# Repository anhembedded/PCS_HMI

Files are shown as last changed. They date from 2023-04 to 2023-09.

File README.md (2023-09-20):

# Microcontroller-HMI replace for PLC

The Festo PCS system, currently available at Cao Thang Technical College, is used for teaching the practical course of Electrical and Electronic Engineering 2, utilizing control systems through EASY PORT or PLC S7-1200 and HMI. However, it poses challenges in terms of maintenance, repair, and replacement due to its high cost. Therefore, this project employs the STM32 microcontroller as a cost-effective alternative, aiming to proactively enhance maintenance and repair, as well as improve the quality of microcontroller utilization and embedded programming skills among students in the field of Electrical and Electronic Engineering.

## Table of Contents

- [Installation](#installation)
- [Usage](#usage)
- [Contributing](#contributing)

## Installation

## Usage

## Contributing

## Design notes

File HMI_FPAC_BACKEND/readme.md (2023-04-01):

# STM32F469I-DISCO TBS

The default IDE is set to STM32CubeIDE, to change IDE open the STM32F469I-DISCO.ioc with CubeMX and select from the supported IDEs (EWARM from version 8.50.9, MDK-ARM, and STM32CubeIDE). Supports flashing of the STM32F469I-DISCO board directly from TouchGFX Designer using GCC and STM32CubeProgrammer.Flashing the board requires STM32CubeProgrammer which can be downloaded from the ST webpage. 

This TBS is configured for 480 x 800 pixels 16bpp screen resolution.  

Performance testing can be done using the GPIO pins designated with the following signals: VSYNC_FREQ  - Pin PA2(D5), RENDER_TIME - Pin PA6(D6), FRAME_RATE  - Pin PA1(D3), MCU_ACTIVE  - Pin PG12(D4)

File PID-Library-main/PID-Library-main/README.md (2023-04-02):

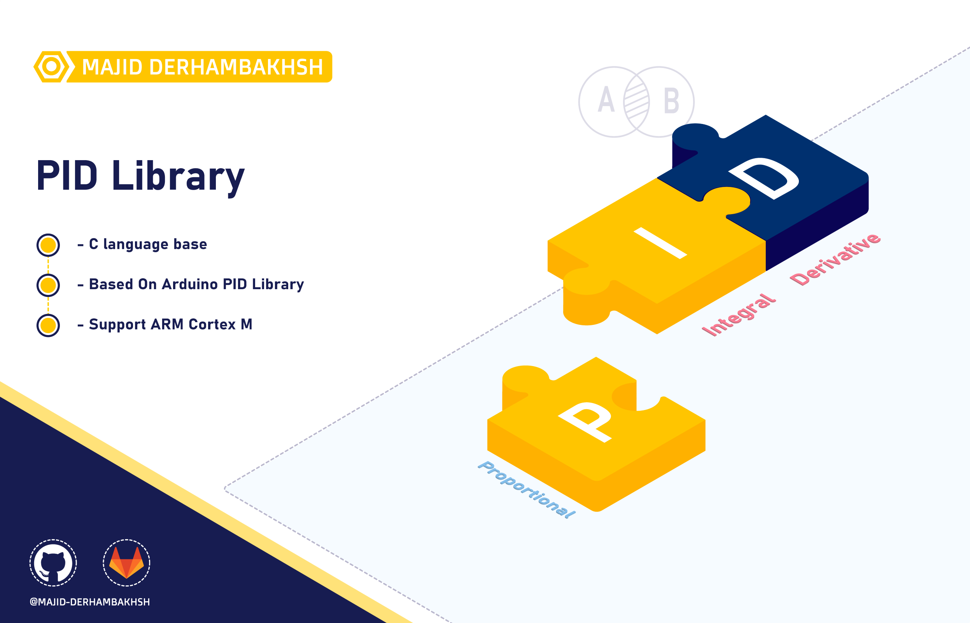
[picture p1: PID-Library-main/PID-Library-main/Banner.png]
Banner


# PID-Library (C Version)

PID Controller library for ARM Cortex M (STM32)

> #### Download Arduino Library : [Arduino-PID-Library](https://github.com/br3ttb/Arduino-PID-Library)  

## Release

- #### Version : 1.0.0

- #### Type : Embedded Software

- #### Support  

               - ARM STM32 series  

- #### Program Language : C/C++

- #### Properties

- #### Changes  

- #### Required Library/Driver

## Overview

### Initialization and de-initialization functions

```c++
void PID(PID_TypeDef *uPID, double *Input, double *Output, double *Setpoint, double Kp, double Ki, double Kd, PIDPON_TypeDef POn, PIDCD_TypeDef ControllerDirection);
void PID2(PID_TypeDef *uPID, double *Input, double *Output, double *Setpoint, double Kp, double Ki, double Kd, PIDCD_TypeDef ControllerDirection);
```

### Operation functions

```c++
/* ::::::::::: Computing ::::::::::: */
uint8_t PID_Compute(PID_TypeDef *uPID);

/* ::::::::::: PID Mode :::::::::::: */
void            PID_SetMode(PID_TypeDef *uPID, PIDMode_TypeDef Mode);
PIDMode_TypeDef PID_GetMode(PID_TypeDef *uPID);

/* :::::::::: PID Limits ::::::::::: */
void PID_SetOutputLimits(PID_TypeDef *uPID, double Min, double Max);

/* :::::::::: PID Tunings :::::::::: */
void PID_SetTunings(PID_TypeDef *uPID, double Kp, double Ki, double Kd);
void PID_SetTunings2(PID_TypeDef *uPID, double Kp, double Ki, double Kd, PIDPON_TypeDef POn);

/* ::::::::: PID Direction ::::::::: */
void          PID_SetControllerDirection(PID_TypeDef *uPID, PIDCD_TypeDef Direction);
PIDCD_TypeDef PID_GetDirection(PID_TypeDef *uPID);

/* ::::::::: PID Sampling :::::::::: */
void PID_SetSampleTime(PID_TypeDef *uPID, int32_t NewSampleTime);

/* ::::::: Get Tunings Param ::::::: */
double PID_GetKp(PID_TypeDef *uPID);
double PID_GetKi(PID_TypeDef *uPID);
double PID_GetKd(PID_TypeDef *uPID);
```

### Macros

```diff  
non   
```

## Guide

#### This library can be used as follows

#### 1.  Add pid.h header  

#### 2.  Create PID struct and initialize it, for example

- Initializer:

  ```c++
  PID(PID_TypeDef *uPID, double *Input, double *Output, double *Setpoint, double Kp, double Ki, double Kd, PIDPON_TypeDef POn, PIDCD_TypeDef ControllerDirection);
  ```

- Parameters:  
  - uPID : Pointer to pid struct
  - Input : The variable we're trying to control (double)
  - Output : The variable that will be adjusted by the pid (double)
  - Setpoint : The value we want to Input to maintain (double)
  - Kp,Ki,Kd : Tuning Parameters. these affect how the pid will change the output (double>=0)
  - POn : Either P_ON_E (Default) or P_ON_M. Allows Proportional on Measurement to be specified.  
  - ControllerDirection : Either DIRECT or REVERSE. determines which direction the output will move when faced with a given error. DIRECT is most common  

- Example:

  ```c++  
  PID_TypeDef TPID;

  double Temp, PIDOut, TempSetpoint;

  PID(&TPID, &Temp, &PIDOut, &TempSetpoint, 2, 5, 1, _PID_P_ON_E, _PID_CD_DIRECT);
  ```

#### 3.  Set 'mode', 'sample time' and 'output limit', for example  

- Functions:

  ```c++
  void PID_SetMode(PID_TypeDef *uPID, PIDMode_TypeDef Mode);
  void PID_SetOutputLimits(PID_TypeDef *uPID, double Min, double Max);
  void PID_SetSampleTime(PID_TypeDef *uPID, int32_t NewSampleTime);
  ```

- Parameters:  
  - uPID : Pointer to pid struct
  - Mode : _PID_MODE_AUTOMATIC or_PID_MODE_MANUAL
  - Min : Low end of the range. must be < max (double)
  - Max : High end of the range. must be > min (double)
  - NewSampleTime : How often, in milliseconds, the PID will be evaluated. (int>0)  

- Example:

  ```c++  
  PID_SetMode(&TPID, _PID_MODE_AUTOMATIC);
  PID_SetSampleTime(&TPID, 500);
  PID_SetOutputLimits(&TPID, 1, 100);
  ```
  
#### 4.  Using Compute function, for example  

```c++
PID_Compute(&TPID);
```  

## Examples  

#### Example 1: PID Compute for temperature

```c++  
#include "main.h"
#include "pid.h"

PID_TypeDef TPID;

char OutBuf[50];
double Temp, PIDOut, TempSetpoint;

int main(void)
{
 
  HW_Init();
  
  PID(&TPID, &Temp, &PIDOut, &TempSetpoint, 2, 5, 1, _PID_P_ON_E, _PID_CD_DIRECT);
 
  PID_SetMode(&TPID, _PID_MODE_AUTOMATIC);
  PID_SetSampleTime(&TPID, 500);
  PID_SetOutputLimits(&TPID, 1, 100);
  
    while (1) 
    {
  
      Temp = GetTemp();
      PID_Compute(&TPID);
      
      sprintf(OutBuf, "Temp%3.2f : %u\n", Temp, (uint16_t)PIDOut);
      UART_Transmit((uint8_t *)OutBuf, strlen(OutBuf));
      
      Delay_ms(500);
    
    }
}
   
```

## Tests performed

- [x] Run on STM32 Fx cores

## Developers

- ### Majid Derhambakhsh

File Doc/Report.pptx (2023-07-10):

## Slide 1

TRƯỜNG KỸ THUẬT CAO ĐẲNG CAO THẮNG
KHOA CƠ KHÍ
BỘ MÔN CƠ ĐIỆN TỬ

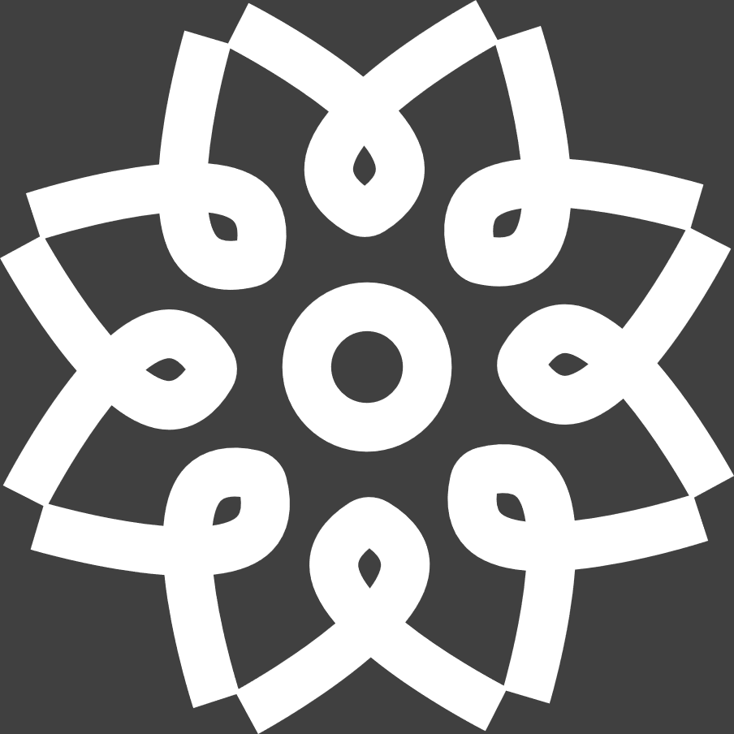
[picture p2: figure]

BÁO CÁO ĐỒ ÁN

THIẾT KẾ VÀ THI CÔNG LÒ NHIỆT

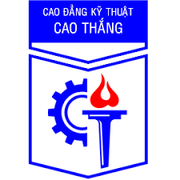
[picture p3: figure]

Ngày 14/12/2022
12 giờ 30 sáng

www.caothang.edu.vn

## Nhóm thực hiện

- GVHD: HỒ MINH CHÍNH

- SVTH: TRẦN HOÀNG ANH 0307171101 CĐ CĐT 19B
- TGTH: 12/6/2023 – 8/7/2023

## Mục tiêu

- Sử dụng board vi điều khiển STM32 có màng hình cảm ứng thay thế PLC S7-1200 và màng hình HMI.

## Chương 1: TỔNG QUAN

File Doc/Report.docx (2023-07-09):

# LỜI CẢM ƠN

Đến với trang đầu tiên của đồ án này , em xin gửi lời cảm ơn đến quý Thầy Cô của Trường Cao Đẳng Kỹ Thuật Cao Thắng là những người đã tận tình truyền đạt những kiến thức cho em suốt thời gian qua.

Bên cạnh đó, cho em gửi lời cảm ơn này đến tất cả Thầy Cô của bộ môn Cơ Điện Tử. mọi người đã luôn tận tình giảng dạy và theo sát trong chặng đường vừa qua.

Và đặc biệt hơn em xin gửi lời cảm ơn chân thành đến Thầy Th.s Hồ Minh Chính người đã đồng hành cùng em mặc dù dịch bệnh vẫn còn phức tạp nhưng thầy vẫn luôn sẵn sàng hỗ trợ đề tài đồ án tốt nghiệp này.

# TÓM TẮT

Ai cũng biết nước đóng vai trò quan trọng trong đời sống cũng như sản xuất, như xa xưa con người lấy nước bằng những cách thô sơ và khó khăn. Và công nghệ 4.0 đang tiếp cận ngày càng nhiều vào cuộc sống của chúng ta thì việc lấy nước từ nơi này sang nơi khác trở nên dễ dàng hơn tiết kiệm nhân công và thời gian.

Để nói rõ hơn thì đồ án này của em là cải tiến trạm PCS bằng việc mô phỏng quá trình lấy nước từ bồn tank1 sang bồn tank2 và ngược lại bằng cách viết chương trình cho board stm32f469 DISC, với giao diện điều khiển bằng màng hình cảm ứng điện dung, ngoài ra có thể điều khiển được mức nước lưu lượng và cũng như áp suất.

Với đề tài đồ án này em đã thực hiện theo các bước sau:

Bước 1: Nghiên cứu tài liệu về tổng quan về chức năng, mục đích sử dụng của hệ thống.

Bước 2: Nghiên cứu sâu vào các đặt tính điện, lô-gíc , chức năng của phần điều khiển mức nước, lưu lượng và áp suất.

Bước 3: Chọn các module chức năng đáp ứng được các yêu cầu về điện, và tín hiệu điều khiển.

Bước 4: Tiến hành viết firmware cho vi điều khiển.

Bước 5: Tiến hành viết HMI cho vi điều khiển.

# DANH SÁCH CHỮ VIẾT TẮT

PCS Processing control system

PID Proportional, Integral, and Derivative

SCADA Supervisory Control And Data Acquisition

# DANH SÁCH CÁC HÌNH

# DANH SÁCH BẢNG

# Chương 1: TỔNG QUAN

## 1.1. Tính cấp thiết của đề tài:

## 1.2. Tổng quan kết quả nghiên cứu liên quan

#### Các kết quả nghiên cứu nước ngoài:

#### Các kết quả nghiên cứu trong nước:

## 1.3. Mục tiêu nghiên cứu của đề tài:

## 1.4. Nhiệm vụ của đề tài và giới hạn đề tài

### Nhiệm vụ đề tài:

### Giới hạn đề tài:

# Chương 2: CƠ SỞ LÝ THUYẾT

## 2.1. Tổng quan về board Stm32f469 DISC

Stm32f469 DISC là một bộ kit phát triển dựa trên vi điều khiển STM32F469NIH6 có hiệu năng cao với lõi ARM Cortex-M4 và Chrom-ART Accelerator. Bộ kit cho phép người dùng phát triển các ứng dụng đa dạng tận dụng các tính năng đồ họa, âm thanh, cảm biến, màn hình màu WVGA, bảo mật, mở rộng bộ nhớ và kết nối. Bộ kit có sẵn trình gỡ lỗi/programmer ST-LINK/V2-1 tích hợp; các bo mạch mở rộng chuyên biệt có thể được kết nối nhờ các cổng Arduino UNO hoặc các cổng mở rộng. Bộ kit cũng có màn hình LCD TFT 4 inch 800x480 pixel với giao tiếp MIPI DSI và màn hình cảm ứng điện dung, DAC âm thanh SAI, jack cắm tai nghe stereo, 3 micro MEMS, khe cắm thẻ MicroSD, bộ nhớ SDRAM 4Mx32bit, bộ nhớ Flash Quad-SPI 128-Mbit và nhiều tính năng khác .

## 2.2. Tổng quan về lõi ARM® Cortex®-M4

Lõi ARM® Cortex®-M4 là một bộ xử lý nhúng hiệu năng cao được phát triển để đáp ứng các thị trường điều khiển tín hiệu số yêu cầu một sự kết hợp hiệu quả và dễ sử dụng giữa khả năng điều khiển và xử lý tín hiệu. Lõi Cortex-M4 có các tính năng và lợi ích sau :

- Hỗ trợ đơn vị tính toán dấu chấm động (FPU) với định dạng IEEE 754-2008.

- Hỗ trợ giao tiếp song song và nối tiếp với các giao thức khác nhau .

- Hỗ trợ gỡ lỗi và theo dõi với các thành phần ETM, MPU, NVIC, FPB, DWT, ITM, AHB, TPIU.

Lõi Cortex-M4 được thiết kế để phục vụ cho nhiều ứng dụng như điều khiển công nghiệp, cảm biến IoT, trí tuệ nhân tạo, xử lý âm thanh và hình ảnh. Lõi Cortex-M4 có thể hoạt động ở tốc độ lên đến 240 MHz và có khả năng xử lý 1.25 DMIPS/MHz. Lõi Cortex-M4 là một trong những lõi vi xử lý ARM phổ biến nhất hiện nay.

## 2.3. Tổng quan về nền tảng stm32 touch gfx

STM32 touch gfx là một nền tảng đồ họa nâng cao và miễn phí được tối ưu hóa cho các vi điều khiển STM32. STM32 touch gfx cho phép tạo ra các giao diện người dùng đẹp mắt và trơn tru trên các thiết bị nhúng, từ các ứng dụng đơn giản với ít màu sắc đến các ứng dụng phức tạp với độ phân giải và màu sắc cao. STM32 touch gfx tận dụng các khả năng phần cứng, kiến trúc và hệ sinh thái của STM32 để tăng tốc quá trình phát triển giao diện người dùng.

STM32 touch gfx có kích thước nhỏ gọn, chỉ cần một lượng bộ nhớ hạn chế để chạy các giao diện người dùng mượt mà. STM32 touch gfx có thể chạy với RTOS hoặc trên bare metal, hỗ trợ các vi điều khiển STM32 dựa trên các bộ xử lý Arm Cortex-M0+, M3, M4, M33 và M7.

## 2.4. Bộ điều khiển PID

Bộ điều khiển PID là một loại bộ điều khiển phản hồi phổ biến trong các hệ thống tự động hóa công nghiệp. Bộ điều khiển PID sử dụng ba thành phần cơ bản: đạo hàm (D), tích phân (I) và tỷ lệ (P) để tính toán một tín hiệu điều khiển dựa trên sự chênh lệch giữa giá trị mong muốn và giá trị thực tế của một biến quá trình. Bộ điều khiển PID có thể điều chỉnh độ nhạy, thời gian đáp ứng và độ ổn định của hệ thống bằng cách thay đổi các thông số P, I và D. Bộ điều khiển PID được ứng dụng rộng rãi trong các lĩnh vực như điều khiển nhiệt độ, áp suất, lưu lượng, tốc độ, vị trí và nhiều biến quá trình khác.

## 2.5. Phương pháp thiết kế bộ điều khiển PID theo Ziegler-Nichols

Phương pháp Ziegler-Nichols là một phương pháp đơn giản để lựa chọn các hệ số Kp, Ki và Kd cho bộ điều khiển PID. Phương pháp này dựa trên việc quan sát biểu đồ đáp ứng của hệ thống khi áp dụng một tín hiệu bước vào đầu vào.

# Chương 3: GIỚI THIỆU MÔ HÌNH

### 1.1.1. Bơm:

Giới thiệu đặc tính bơm, các thông số cơ bản, vai trò của bơm trong hệ thống

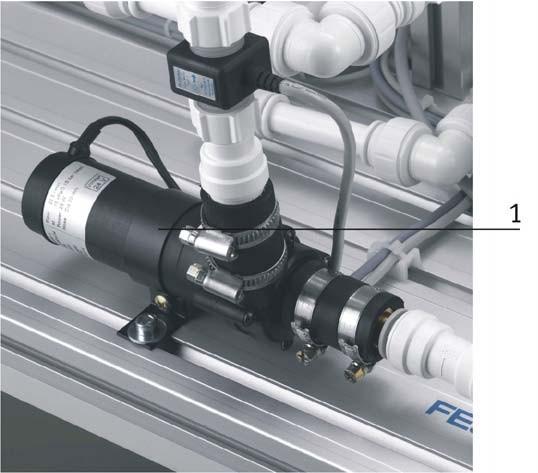
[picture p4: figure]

Hình 3-2 cụm bơm

Máy bơm không được vận hành khi chạy khô. Trước khi vận hành thử, bể chứa hoặc hệ thống đường ống đến / từ máy bơm phải được đổ đầy chất lỏng.

Bơm được dẫn động bởi bộ điều khiển động cơ A4 và rơ le K1. Với đầu ra kỹ thuật số (O2 tại XMA1), có thể chuyển từ điều khiển nhị phân kỹ thuật số sang biến điều khiển tương tự từ 0 đến 24 V. Tại điều khiển nhị phân kỹ thuật số (O2 = 0), máy bơm được bật / tắt với một đầu ra bổ sung (O3 tại XMA1). Ở điều khiển tương tự (O2 = 1), điện áp biến tần từ kênh tín hiệu đầu ra tương tự 0 (UA1 tại X2) đang cài đặt tốc

độ của bơm từ 0 đến 10 V.

- Chức năng của bơm

Máy bơm cung cấp chất lỏng từ bể chứa qua hệ thống đường ống. Tốc độ dòng chảy được phát hiện nhờ cảm biến cánh gạt quang điện tử B102 (2) ở dạng giá trị thực. Giá trị thực tế cũng nên được giữ trên một tốc độ dòng chảy nhất định nếu xảy ra nhiễu loạn hoặc thay đổi điểm đặt.

Để điều khiển hệ thống, có thể sử dụng phần tử liên tục . Có hai chế độ hoạt động:

- Điều khiển tốc độ dòng chảy bằng máy bơm P101 như một hệ thống được điều khiển. Giá trị thao tác là điện áp của máy bơm, thiết lập tốc độ quay vòng.
- Điều khiển tốc độ dòng chảy bằng van tỷ lệ V106 như một hệ thống được điều khiển. Giá trị thao tác là điện áp của cuộn van, thiết lập hành trình của piston van. Máy bơm P101 đang chạy với tốc độ quay vòng không đổi.

### 1.1.2. Bình chứa

#### 1.1.2.1. Bình B101

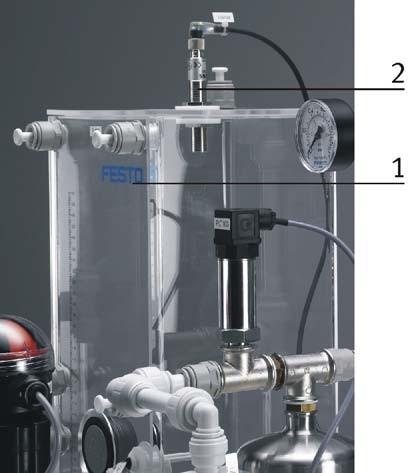
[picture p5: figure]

Hình 3-3 tank 1

#### 1.1.2.2. Bình chứa B102

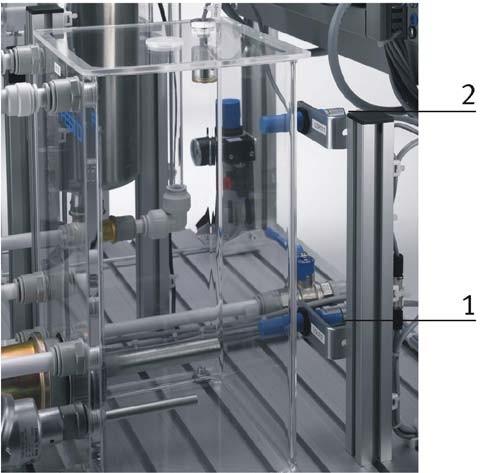
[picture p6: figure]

Hình 3-4 tank 2

#### 1.1.2.3. Bình áp suất B103

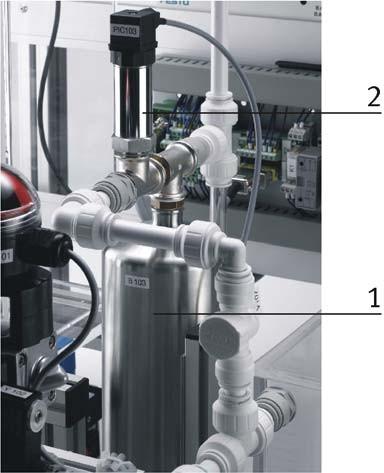
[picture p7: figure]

Hình 3-5 bình áp suất

Áp suất quá trình của chất lỏng bên trong bình tích áp phải được điều chỉnh. Hệ thống điều khiển áp suất được sử dụng là hệ thống được điều khiển có khả năng tự điều chỉnh (hệ thống điều khiển PT1). Bởi vì bình tích áp được làm đầy một phần khí (không khí) nên nó là một hệ thống lưu trữ năng lượng.

Thông qua hệ thống đường ống, máy bơm P101 cung cấp chất lỏng từ bồn chứa vào bồn chứa áp suất được bơm đầy khí B103 (1). Áp suất của khí (không khí) trong bình tích áp được phát hiện bằng cảm biến áp suất tương đối áp suất dưới dạng một giá trị thực tế. Giá trị thực tế cũng nên được giữ ở một áp suất nhất định nếu xảy ra nhiễu loạn hoặc thay đổi điểm đặt.

### 1.1.3. Van cầu đóng mở bằng khí nén

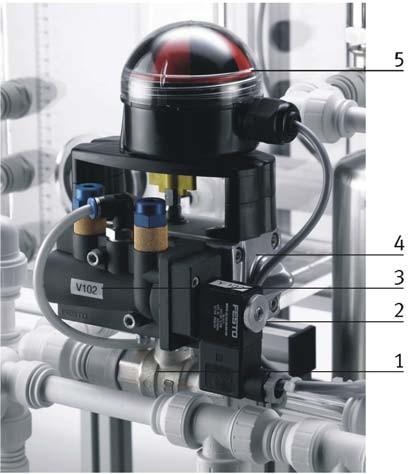
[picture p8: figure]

Hình 3-6 van cầu đómg

V102 lắp khớp được đóng mở bằng bộ truyền động khí nén. Thiết bị được điều khiển bao gồm một van bi bằng đồng (1) với kiểu ổ quay SYPAR (4), sử dụng nguyên lý chạy scotch. Một van điện từ (2) 5/2 chiều (3) với kiểu cổng tới NAMUR và hộp cảm biến (5) được lắp mặt bích vào ổ quay. Dòng chảy của chất lỏng từ thùng trên B102 vào thùng dưới B101 được điều khiển bằng van bi của bộ truyền động quá trình.

Cấu tạo của van cầu

1. van bi đồng điện
2. van điện từ
3. Van 5/2 chiều với kiểu cổng tới kiểu ổ quay NAMUR
4. SYPAR, hộp cảm biến nguyên lý ổ cắm scotch
5. bao gồm hai công tắc vi điện với cần con lăn. Hai tín hiệu nhị phân 24 VDC (S115 và S116) được kết nối làm đầu vào cho I / O-terminal XMA1. Ngoài ra còn có một chỉ dẫn trực quan về vị trí ổ đĩa cho người vận hành.

### 1.1.4. Van tỉ lệ

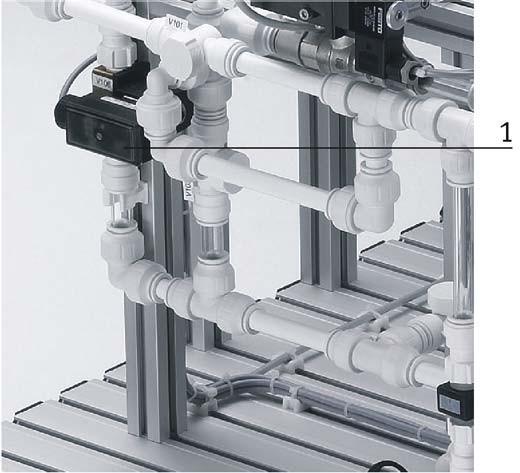
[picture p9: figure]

Hình 3-7 van tỉ lệ

Van tỷ lệ V106 (1) là van 2 chiều được kích hoạt trực tiếp để kiểm soát dòng chảy của chất lỏng. Nó có thể được sử dụng như một phần tử điều chỉnh từ xa trong các vòng mở hoặc đóng. Các piston của van được nâng lên khỏi chỗ của nó như một chức năng của dòng điện cuộn dây điện từ và giải phóng dòng chảy qua van

Điện tử điều khiển của van tỷ lệ được kích hoạt với đầu ra nhị phân (O4 tại XMA1). Tín hiệu tương tự từ kênh 1 (UA2 tại X2) được điều khiển đầu vào tín hiệu của van tỷ lệ với tín hiệu tương tự tiêu chuẩn từ 0 đến 10 V.

Tín hiệu tương tự tiêu chuẩn được biến đổi thành điều chế độ rộng xung (PWM) và độ mở của van có thể điều chỉnh vô hạn. Tần suất của PWM có thể được điều chỉnh cho các loại van khác nhau.

### 1.1.5. Các cảm biến

#### 1.1.1.1. Cảm biến siêu âm

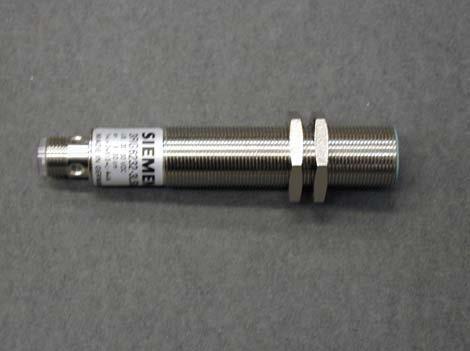
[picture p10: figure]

Hình 3-8 cảm biến siêu âm

Chức năng:

- Nguyên tắc hoạt động của cảm biến siêu âm dựa trên việc tạo ra sóng âm và phát hiện chúng sau phản xạ trên một vật thể. Thông thường, không khí trong khí quyển hoạt động như một vật mang sóng siêu âm.
- Máy phát âm thanh được kích hoạt trong một khoảng thời gian ngắn và phát ra xung siêu âm mà tai người không nghe được. Sau khi phát xạ, xung siêu âm được phản xạ trên một vật thể nằm trong phạm vi và dội ngược trở lại máy thu. Khoảng thời gian của xung siêu âm được đánh giá bằng điện tử. Trong một phạm vi nhất định, tín hiệu đầu ra tỷ lệ với thời lượng tín hiệu của xung siêu âm. Đối tượng được phát hiện có thể được làm bằng các vật liệu khác nhau. Hình dạng hoặc màu sắc, tình trạng rắn, lỏng hoặc bột không có bất kỳ hoặc ảnh hưởng rất nhỏ đến việc phát hiện.
- Trong trường hợp các vật thể có bề mặt nhẵn, đồng đều, bề mặt đó phải được căn chỉnh theo chiều dọc của chùm tia siêu âm.
- Với loại cảm biến này, bạn có thể thực hiện hai loại phép đo: Đầu tiên, bạn có thể đo khoảng cách giữa cảm biến và một đối tượng. Thiết lập của nhà sản xuất của cảm biến là lý tưởng cho loại phép đo này. Tăng tín hiệu đầu ra ở khoảng cách tăng tới đối tượng.
- Nhưng để đo mức đổ đầy của vật chứa, cần phải có một thiết lập khác vì khi mức lấp đầy tăng lên, khoảng cách của đối tượng được đo (mặt nước) đến cảm biến ngày càng nhỏ.
- Do đó đầu ra tín hiệu được thay đổi từ đặc tính tăng sang đặc tính giảm. Ngoài ra, phạm vi đo đã được thay đổi để chúng tôi có thể nhận được tín hiệu đầu ra tối đa ở mức tối đa và tín hiệu đầu ra tối thiểu ở mức lấp đầy tối thiểu.

Thông số kĩ thuật:

Thông số | Giá trị
Bảo vệ | Kháng nước IP 67
Trọng lượng | Tối đa 67g
Nhiệt độ môi trường xung quanh | -25 đến 70°C
Lỗi điểm chuyển mạch | ± 2,5 % (-25 to 70°C)
Điện áp hoạt động định mức Ue | 24 V DC
Dải điện áp hoạt động UB | 20 ... 30 V DC (ở 12 ... 20 V DC giảm độ nhạy lên đến 20%)
Gợn sóng dư cho phép | 10%
Mức tiêu thụ hiện tại không hoạt động I0 | ‹ 50 mA
Công tắc đầu ra (NC / NO) / Đầu ra tần số (FA) Định mức hoạt động hiện tại tức là Điện áp rơi Ud | ≤ 150 mA ≤ 3 V at 150 mA
Đầu ra tương tự (UA / IA) Phạm vi hiện tại Sức tải | 4...20 mA 0...300 Ω
Cảm biến hoạt động | Điện áp hoạt động hoặc dòng điện đầu vào trở kháng cao IE. Tối đa 16 mA
Cảm biến không hoạt động | 0 ... 3 V Dòng đầu vào IE tối đa 11 mA

bảng 3-1 thông số kĩ thuật cảm biến siêu âm

Chi tiết thiết lập:

Thông số | Giá trị
Phạm vi đo lường | Từ: 50mm Đến: 345mm
Phạm vi đo lường tối đa | Từ: 46mm Đến: 346mm
Tín hiệu đầu ra (Dòng điện) | 4…20 mA

bảng 3-2 thông số thiết lập cảm biến siêu âm

#### 1.1.1.2. Cảm biến siêu âm tương tự

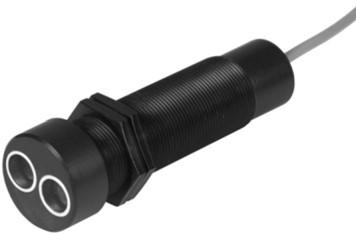
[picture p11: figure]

Hình 3-9 cảm biến siêu âm(1)

Chức năng:

- Nguyên tắc hoạt động của cảm biến siêu âm dựa trên việc tạo ra sóng âm và phát hiện chúng sau phản xạ trên một vật thể. Thông thường, không khí trong khí quyển hoạt động như một vật mang sóng siêu âm. Máy phát âm thanh được kích hoạt trong một khoảng thời gian ngắn và phát ra xung siêu âm mà tai người không nghe được. Sau khi phát xạ, xung siêu âm được phản xạ trên một vật thể nằm trong phạm vi và dội ngược trở lại máy thu. Khoảng thời gian của xung siêu âm được đánh giá bằng điện tử. Trong một phạm vi nhất định, tín hiệu đầu ra tỷ lệ với thời lượng tín hiệu của xung siêu âm. Đối tượng được phát hiện có thể được làm bằng các vật liệu khác nhau. Hình dạng hoặc màu sắc, tình trạng rắn, lỏng hoặc bột không có bất kỳ hoặc ảnh hưởng rất nhỏ đến việc phát hiện. Trong trường hợp các vật thể có bề mặt nhẵn, đồng đều, bề mặt đó phải được căn chỉnh theo chiều dọc của chùm tia siêu âm.
- Cảm biến siêu âm có thể được lắp ráp trên một giá đỡ bằng cách sử dụng hai đai ốc đầu nối. Cảm biến có thiết kế hình trụ với ren M30x1.

Thông số màu dây:

Điện áp hoạt động | Cực dương | Màu trắng
| Cực âm | Màu nâu
Tín hiệu đầu ra tương tự | Dòng điện | Màu xanh lá

bảng 3-3 màu dây

- Cảm biến được bảo vệ chống phân cực ngược.
- Đầu ra cảm biến cung cấp một dòng điện ấn tượng và được tải trong quá trình hoạt động ngắn mạch. Tốt nhất, đầu ra nên được tải với điện trở RL = 0 Ω.

Thômg số kĩ thuật:

Thông số | Giá trị
Điện áp hoạt động cho phép | 24 VDC
Tiêu thụ hiện tại (không tải) | ‹ 35 mA
Chịu tải | ‹ 400 Ω
Ngõ ra dòng điện | 4 ... 20 mA
Dải đo | 500 ... 150 mm
Khoảng cách tối thiểu giữa cảm biến và tường phản xạ bên | › 75 mm
Độ phân giải | 1 mm
Phạm vi nhiệt độ hoạt động / Môi trường xung quanh | –20 ... +75 °C
Nhiệt độ dao động | 0,1%/°C
Lỗi tuyến tính | 0,2% FSD * (* FSD = độ lệch toàn quy mô)
Đo tần số xung | 40 Hz
Góc khẩu độ hình nón âm thanh | Approx. 5°
Bảo vệ phân cực ngược | có
Bảo vệ | Kháng nước IP 65
Vật liệu | Nhựa dẻo
Trọng lượng | 0,250 kg

bảng 3-4 thông số kĩ thuật cảm biến siêu âm (1)

#### 1.1.1.3. Cảm biến lưu lượng

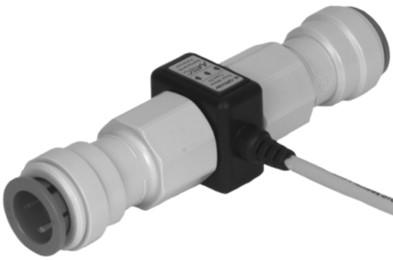
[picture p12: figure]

Hình 3-10 cảm biến lưu lượng

Chức năng:

- Chất lỏng trong suốt được đưa vào theo hướng của mũi tên được dẫn thành chuyển động tròn qua tấm xoáy trong buồng đo và được dẫn vào rôto ba cánh gạt nhẹ. Tốc độ của rôto tỷ lệ thuận với tốc độ dòng chảy và được phát hiện mà không cần phản hồi thông qua hệ thống quang điện tử hồng ngoại tích hợp (diode và phototransistor).
- Bộ khuếch đại tích hợp cung cấp tín hiệu sóng vuông ổn định, theo đó mức tín hiệu phụ thuộc vào điện áp cung cấp được áp dụng (5 đến 12 V DC).
- Do thiết kế đặc biệt của rôto, bất kỳ bong bóng khí nào (bọt khí) có thể xuất hiện trong chất lỏng, sẽ không bị hòa tan mà mang theo chất lỏng. Mọi vị trí lắp ráp đều được. Hướng của dòng chảy được biểu thị bằng một mũi tên trên vỏ cảm biến. Vùng ổn định lên hoặc xuống của thiết bị đo là không cần thiết.
- Các dao động hoặc xung tốc độ dòng chảy không có ảnh hưởng tiêu cực đến kết quả đo.
- Một bộ lọc bảo vệ được lắp ở phía đầu vào.
- Tất cả các bộ phận của vỏ máy đo tiếp xúc với môi trường được làm bằng polyvinylidene fluoride (PVDF)

Thông số kĩ thuật:

Thông số | Giá trị
Điện áp hoạt động cho phép | 5 ... 12 VDC
Mức tiêu thụ dòng | 6 ... 24 mA
Dải tần số ( Đầu ra) | 26,66 ... 800 Hz
Tải tối đa | 2,2 k
Khai thác tín hiệu | Hồng ngoại (Quang điện tử)
Hệ số K (xung / dm³) | 3200
Dải đo | 0,5 ... 15,0 l/phút
Độ tin cậy của phép đo | ± 1% trong số đo. Giá trị, tại 20 °C
Tuyến tính | ± 1% tại 20 °C
Độ nhớt | Áp dụng lên đến 15 cST.
Áp lực vận hành | Tối đa. 6 bar tại 80°C
Phạm vi nhiêt độ tiêu chuẩn | 0°C... +65 °C
Bảo vệ phân cực ngược | có
Vật liệu | PVDF Viton
Kích thước: Chiều dài Kết nối dây | 47mm M20x2
Kết nối điện | Cáp, dài 750 mm

bảng 3-5 thông số kĩ thuật cảm biến lưu lượng

#### 1.1.1.4. Cảm biến áp suất tương tự

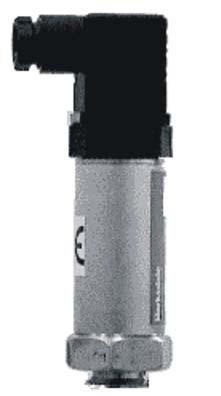
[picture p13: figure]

Hình 3-11 cảm biến áp suất (1)

Chức năng

- Cảm biến áp suất tương tự piezoresistive với bộ khuếch đại tích hợp và bộ bù nhiệt độ được lắp vào một vỏ nhôm duy nhất. Áp suất cần đo được truyền đến một phần tử tạo áp lực. Do đó, tín hiệu được tạo ra được khuếch đại và xuất ra dưới dạng điện áp tại đầu nối điện.
- Cảm biến áp suất tương tự được lắp vào hệ thống đường ống thông qua đầu nối G ½ ”. Kết nối điện được thực hiện bằng ổ cắm 3 chân.

2

3

1

1 Nguồn +24 VDC
2 Nối đất, 0 VDC
3 Đầu ra điện áp: 0 VDC đến 10 VDC

Thông số kĩ thuật

Thông số | Giá trị
Dải đo | 0 mbar đến 100 mbar
Quá tải | 2,5 bar
Cung cấp điện áp UB | 13 VDC đến 30 VDC
Tín hiệu đầu ra | 0 VDC đến 10 VDC
Mức tiêu thụ hiện tại | tối đa 25 mA ở đầu ra hiện tại tối đa. 5 mA ở đầu ra điện áp
Lỗi tuyến tính | ±0,5% f. s.
Thời gian đáp ứng | ≤1 ms
Tính lặp lại | ≤±0,1% v. f. s.
Trung bình | Nước
Màng | Thép không gỉ
Nhiệt độ môi trường tiêu chuẩn | 0 °C đến +65 °C
Kết nối điện | ổ cắm 3-pin
Kết nối quá trình | G ½ "ren vít bên ngoài, thép không gỉ
Trọng lượng | 250 g
Phạm vi nhiệt độ Phương tiện truyền thông Thiết bị điện tử Lưu trữ | -25°C đến +100°C -25°C đến +80°C -40°C đến +100°C

bảng 3-6 thông số kĩ thuật cảm biến áp suất

#### 1.1.1.5. Cảm biến áp suất

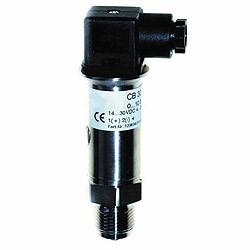
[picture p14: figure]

Hình 3-12 cảm biến áp suất

Chức năng:

- Bộ chuyển đổi đo áp suất sử dụng tế bào đo lường gốm làm cảm biến.
- Thiết bị điện tử chuyển tín hiệu đo thành các tín hiệu đầu ra 4..20mA, 0..20mA hoặc 0..10V.
- Do thiết kế mạnh mẽ, cảm biến này cũng được sử dụng trong môi trường công nghiệp khắc nghiệt.
- Phạm vi nhiệt độ quá trình tối đa không được vượt quá 100 ° C.

Thiết kế:

- Để bảo vệ thiết bị điện tử khỏi rung động và độ ẩm, nó được truyền vào.
- Điểm 0 có thể được điều chỉnh bằng một chiết áp tích hợp. Nó có thể đạt được bằng cách tháo một vít vỏ.
- Cảm biến có thể được kết nối với công nghệ 2 dây hoặc 3 dây.
- Việc bù áp được thực hiện bằng một lỗ ở đầu cảm biến.

Thông số kĩ thuật

Thông số | Giá trị
Kết nối điện | Đầu nối khuỷu tay đẩy vào DIN 43650
Bảo vệ | Kháng nước IP65
Các bộ phận tiếp xúc với chất đo | Vòng đệm bằng gốm, thép không gỉ,vòng đệm NBR
Ô đo lường | Tế bào gốm
Phạm vi nhiệt độ - Nhiệt độ quá trình (ở mức tối đa nhiệt độ môi trường 50 ° C) - Nhiệt độ bảo quản - Nhiệt độ môi trường cho phép - Phạm vi nhiệt độ bù | 25°C..+100°C -40°C..+85°C -25°C..85°C -10°C..55°C
Ảnh hưởng nhiệt độ - Về điểm 0 - Trên phạm vi | ‹0,25% f.E./10K ‹0,15% f.E./10K
Nguồn cấp - Định mức điện áp - Dải điện áp - Tối đa cung cấp điện áp cho phép | 24VDC 11VDC..40VDC 40VDC
Đầu ra tín hiệu Công nghệ 2 dây Công nghệ 3 dây | 4..20mA 0..20mA or 0..10V
Giới hạn hiện tại ở tín hiệu đầu ra | Ở 110% dải áp suất
Phạm vi điều chỉnh | Điểm không ± 10%
Độ lệch đường cong đặc trưng (Độ tuyến tính, độ trễ, độ lặp lại) | ‹0,5% f.E. (điều chỉnh điểm 0)
Thời gian đáp ứng | ‹3ms
Tải RL tối đa | (Usupply-11)/0,02
Tải ở đầu ra tín hiệu 0..10V | ›2,5 kΩ
Trọng lượng | ~300g
Khả năng chống ồn | Đến DIN 50082

bảng 3-7 thông số kĩ thuật cảm biến áp suất

#### 1.1.1.6. Cảm biến tiệm cận điện dung

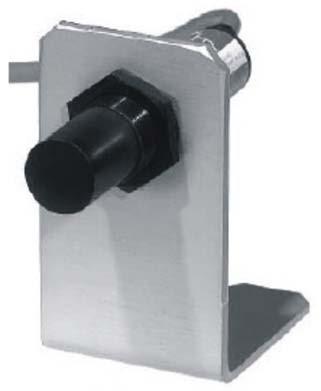
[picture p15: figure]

Hình 3-14 cảm biến tiệm cận điện dung

Chức năng

- Nguyên lý hoạt động của cảm biến tiệm cận điện dung dựa trên việc đánh giá sự thay đổi điện dung của tụ điện trong mạch cộng hưởng RC. Điện dung tăng lên khi một đối tượng tiếp cận cảm biến độ gần. Điều này dẫn đến sự thay đổi trong hoạt động dao động của mạch RC có thể được đánh giá. Sự thay đổi điện dung phần lớn phụ thuộc vào khoảng cách, kích thước và hằng số điện môi của vật liệu tương ứng.
- Cảm biến tiệm cận có đầu ra PNP, tức là đường tín hiệu được chuyển sang điện thế dương ở trạng thái được chuyển mạch. Công tắc được thiết kế dưới dạng tiếp điểm thường mở.
- Tải được kết nối giữa đầu ra tín hiệu cảm biến và đất. Đi-ốt phát sáng màu vàng (LED) cho biết trạng thái chuyển mạch. Không thể lắp cảm biến tiệm cận điện dung.
- Cảm biến tiệm cận điện dung có thể được gắn qua một giá đỡ góc và hai đai ốc khóa. Cảm biến có thiết kế hình trụ với ren M18x1.

Thông số kĩ thuật

Thông số | Giá trị
Điện áp hoạt động cho phép | 10 ... 55 VDC
Chuyển đầu ra | PNP, Tiếp điểm thường mở
Khoảng cách chuyển đổi danh nghĩa | 2 ... 8 mm
Độ trễ (ở khoảng cách chuyển mạch danh nghĩa) | 3 ... 15 %
Chuyển mạch tối đa hiện tại | 200 mA
Tần số chuyển mạch tối đa | 300 Hz
Mức tiêu thụ hiện tại khi chạy không tải (ở 55 V) | 7 mA
Nhiệt độ môi trường hoạt động cho phép | 20 °C ... +70 °C
Bảo vê | Kháng nước IP 65
Bảo vệ phân cực ngược, cường độ ngắn mạch | có
Vật liệu | Nhựa nhiệt dẻo
Trọng lượng | 0,20 kg
Kết nối điện | Cáp, dài 2000 mm

# Chương 4: THIẾT KẾ THI CÔNG HỆ THỐNG NHÚNG

Xác định vấn đề:

Là hệ thống nhúng điều khiển các cổng I/O và các peripherals, thông qua màng hình cảm ứng. Chương trình phức tạp, nhiều trạng thái, nhiều event. Yêu cầu chính xác về mặc thời gian, không bỏ lỡ event. Thực toán có liên quan đến số thực. Cần phần mềm debug chuyên nghiệp.

Căn cứ vào các yêu cầu đó ta cần có:

- Phương pháp quản lý mã nguồn: áp dụng GIT vào quả lý mã nguồn.
- IDE chuyên nghiệp: sử dụng Visual studio code để phát triển phần mềnm.
- Phần mềm được chạy trên real time os: áp dụng freeRTOS cho phần mềm
- Tách riêng forntend và backend để phát triển độc lập: tạo 1 project cho frontend, và 1 project cho backend để phát triển độc lập.

Chương trình được phân thì 2 lớp (layer):

Frontend và backend, frontend gồm các file chương trình C++ để điều khiển HMI, backend gồm các chương trình để điều khiển I/O, peripherals…

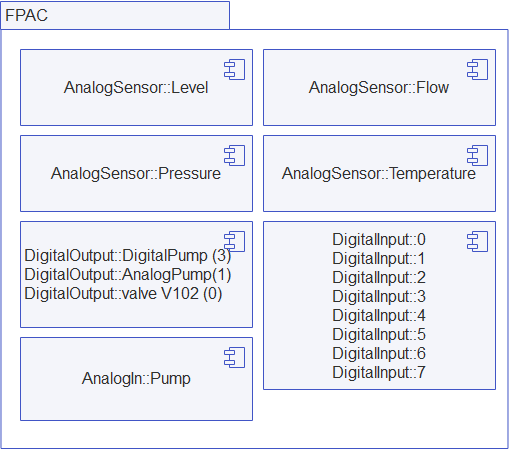
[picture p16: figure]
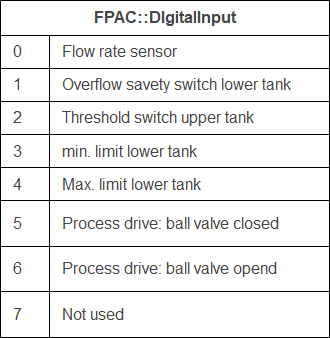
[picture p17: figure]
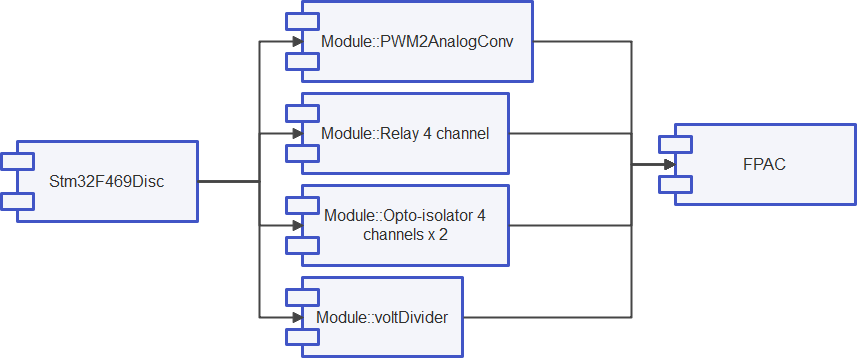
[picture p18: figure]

- Các loại tính hiệu điều khiển:

Digital Input

Logic level 0 – 24v, tần số thấp.

Số lượng 8.

Digital Output

Logic level 0 – 24v, tần số thấp, công suất cần đủ để đóng ngắt relay.

Số lượng 3.

Analog Output

0 – 10v

Số lượng 1.

Analog Input

0 -10v, chưa được hạn dòng.

Số lượng 3.

### Chon thiết bị:

#### Digital Input:

Opto Isolator 4 channel Module x2.

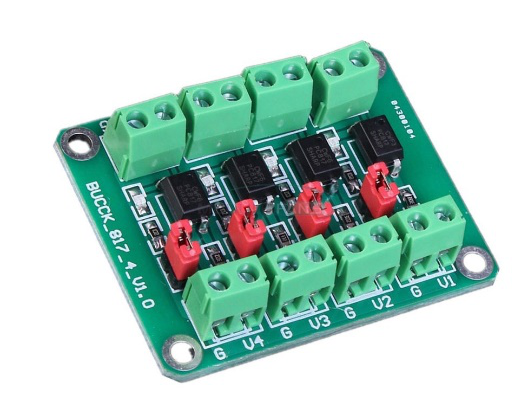
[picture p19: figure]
PC817 4 Channel Optocoupler Isolation Board Voltage Converter Adapter ...

Điện áp tính hiệu điều kiển: 0-24V

Điện áp đầu ra tối đa của ngõ ra: 30V

#### Digital Output:

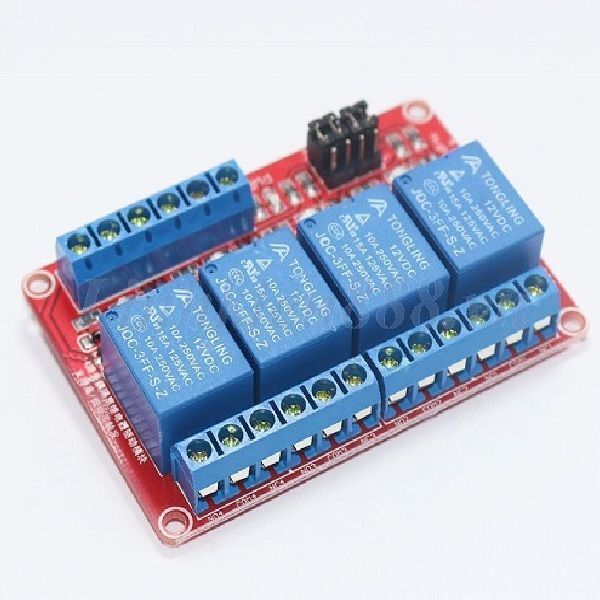
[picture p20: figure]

Relay 4 channel Module.

Tính hiệu điều khiển: digital logic level 3.3V

Điện áp nuôi mạch: 5 VDC.

Tiếp điểm đóng ngắt max: 250VAC-10A hoặc 30VDC-10A

#### Analog Output

Pwm to analog converter module

#### Analog Input

Mạch chia phân 4 kênh tự gia công và thiết kế

Input analog 0 – 10 V, output analog 0 – 3.1 V

#### Nguồn cho vi điều kiển và các module

Thiết kế chương trình điều khiển

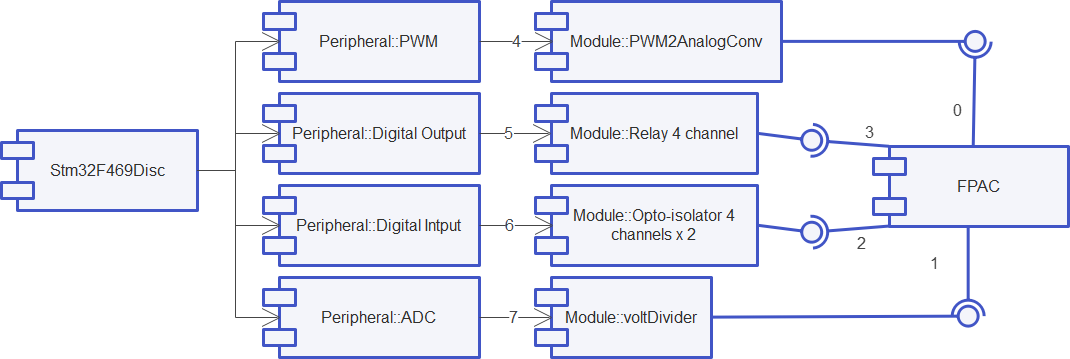
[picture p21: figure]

Căn cứ vào yêu cầu tín hiều của hệ thống, ta có bảng sau:

SignalType | STM32 Peripheral | STM32F469 Alternative Function | Peripheral Clock Bus | STM32F469 Pinout | Note
AnalogIn0 | ADC1 | ADC12_IN9 | APB2 | PB1
AnalogIn1 | ADC1 | ADC12_IN12 | APB2 | PC2
AnalogIn2 | ADC1 | ADC12_IN13 | APB2 | PC3
AnalogIn3 | ADC1 | ADC12_IN14 | APB2 | PC4
DigitalOutput0 | GPIOC | ADC12_IN15 | AHB1 | PC5
DigitalOutput1 | GPIOA | ADC12_IN4 | AHB1 | PA4
DigitalOutput2 | GPIOG | | AHB1 | PG9
DigitalOutput3 | GPIOG | | AHB1 | PG14
DigitalOutput4 | GPIOG | | AHB1 | PG13
AnalogOut0 | TIM5 | TIM5_CH2/PWM | APB1 | PA1 | 1.37 Khz
Non
AnalogOut1 | TIM5 | TIM5_CH3/PWM | APB1 | PA2 | 1.37 Khz
Non
DigitalInput0 | GPIOG | | AHB1 | PG11 | EXTI_LINE_11
DigitalInput1 | GPIOG | | AHB1 | PG10 | EXTI_LINE_10
DigitalInput2 | GPIOA | | AHB1 | PA7 | EXTI_LINE_7
DigitalInput3 | GPIOH | | AHB1 | PH6 | EXTI_LINE_6
DigitalInput4 | GPIOB | | AHB1 | PB15 | EXTI_LINE_15
DigitalInput5 | GPIOB | | AHB1 | PB14 | EXTI_LINE_14
DigitalInput6 | GPIOD | | AHB1 | PD3 | EXTI_LINE_3

Viết chương trình cấu hình các chứng năng của vi điều khiển theo bảng sau.

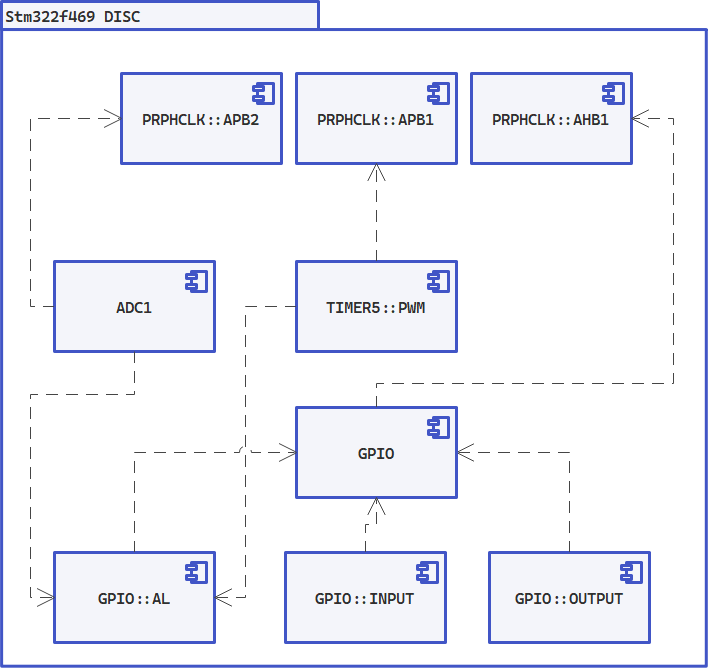
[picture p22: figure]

Cấu hình Analog.

Cấu hình digital input.

Cấu hình digital output.

Cấu hình timer pwm.

Thiết kế giao diện HMI:

Giao diện được thiết kế trên phần mềm TouchGfx designer.

# Chương 5: Thực Nghiệm

      1. Level
      2. Flow
      3. Pressure

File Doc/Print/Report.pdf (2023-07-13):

TRƯỜNG CAO ĐẲNG KỸ THUẬT CAO THẮNG

KHOA CƠ KHÍ

BỘ MÔN CƠ ĐIỆN TỬ

## Tên đề tài:

# BÁO CÁO ĐỒ ÁN

THIẾT KẾ, THI CÔNG BỘ ĐIỀU KHIỂN PCS

GVHD: TH.S HỒ MINH CHÍNH

MSSV:
SVTH: TRẦN HOÀNG ANH | 0307171101

Lớp: CĐ CĐT 19B

## Mục lục

1. Thực nghiệm xác định hệ số factor và offet của cảm biến .........49

## LỜI CẢM ƠN

Đến với trang đầu tiên của đồ án này , em xin gửi lời cảm ơn đến quý Thầy Cô của Trường Cao Đẳng Kỹ Thuật Cao Thắng là những người đã tận tình truyền đạt những kiến thức cho em suốt thời gian qua.

Bên cạnh đó, cho em gửi lời cảm ơn này đến tất cả Thầy Cô của bộ môn Cơ Điện Tử. mọi người đã luôn tận tình giảng dạy và theo sát trong chặng đường vừa qua.

Và đặc biệt hơn em xin gửi lời cảm ơn chân thành đến Thầy Th.s Hồ Minh Chính người đã đồng hành cùng em mặc dù dịch bệnh vẫn còn phức tạp nhưng thầy vẫn luôn sẵn sàng hỗ trợ đề tài đồ án tốt nghiệp này.

## TÓM TẮT

Ai cũng biết nước đóng vai trò quan trọng trong đời sống cũng như sản xuất, như xa xưa con người lấy nước bằng những cách thô sơ và khó khăn. Và công nghệ 4.0 đang tiếp cận ngày càng nhiều vào cuộc sống của chúng ta thì việc lấy nước từ nơi này sang nơi khác trở nên dễ dàng hơn tiết kiệm nhân công và thời gian.
Để nói rõ hơn thì đồ án này của em là cải tiến trạm PCS bằng việc mô phỏng quá trình lấy nước từ bồn tank1 sang bồn tank2 và ngược lại bằng cách viết chương trình cho board stm32f469 DISC, với giao diện điều khiển bằng màng hình cảm ứng điện dung, ngoài ra có thể điều khiển được mức nước lưu lượng và cũng như áp suất.

## DANH SÁCH CHỮ VIẾT TẮT

PCS | Processing control system
CMSIS | The Cortex Microcontroller Software Interface Standard
FPAC | Festo process automation compact Workstation

## DANH SÁCH CÁC HÌNH

Hình 4.5 cung cấp 1 hàm với chức năng là trả về giá trị của system

## DANH SÁCH BẢNG

## Chương 1: TỔNG QUAN

### 1.1. Tính cấp thiết của đề tài:

Trong thời đại 4.0, công nghiệp hóa và số hóa là xu hướng không thể đảo ngược. PLC HMI là thiết bị điều khiển và hiển thị thông tin quan trọng trong các hệ thống tự động hóa. Tuy nhiên, PLC HMI có những hạn chế như giá thành cao, khả năng mở rộng thấp và giao diện người dùng không thân thiện. Để khắc phục những hạn chế đó, đề tài này dùng stm32 touchgfx thay thế PLC HMI trên hệ PCS là một giải pháp tiềm năng. stm32 touchgfx là một nền tảng phát triển ứng dụng giao diện người dùng đồ họa trên vi điều khiển stm32. stm32 touchgfx có những ưu điểm như giá thành rẻ, khả năng tùy biến cao và giao diện người dùng đẹp mắt. Đề tài này có tính cấp thiết cao vì nó góp phần nâng cao hiệu quả và tiết kiệm chi phí cho nhà trường và doanh nghiệp trong thời đại 4.0.

Một số lợi ích của việc sử dụng stm32 touchgfx để thay thế PLC HMI là:

- Giảm chi phí: stm32 touchgfx có giá thành rẻ hơn so với PLC HMI, do không cần mua thêm các bộ phận như bộ nhớ, bộ xử lý, bộ nguồn, v.v.
- Tăng tính linh hoạt: stm32 touchgfx có khả năng tùy biến cao, do có thể lập trình theo nhu cầu của từng ứng dụng, cũng như có thể kết nối với nhiều loại cảm biến và thiết bị khác nhau.
- Tăng hiệu suất: stm32 touchgfx có tốc độ xử lý nhanh hơn so với PLC HMI, do sử dụng vi điều khiển 32 bit và có hỗ trợ phần cứng cho đồ họa. Ngoài ra, stm32 touchgfx cũng có khả năng cập nhật phần mềm dễ dàng hơn so với PLC HMI, do có thể sử dụng kết nối USB hoặc không dây.

### 1.2. Tổng quan kết quả nghiên cứu liên quan

1.2.1 Các kết quả nghiên cứu nước ngoài:

Một số kết quả nghiên cứu ở nước ngoài về việc sử dụng stm32 touchgfx để thay thế PLC HMI là:

- Một nghiên cứu của Đại học Kỹ thuật Istanbul, Thổ Nhĩ Kỳ, đã thiết kế và xây dựng một hệ thống điều khiển công nghiệp cho một máy ép nhựa, sử dụng stm32 touchgfx để tạo giao diện người dùng đồ họa và kết nối với một vi điều khiển STM32F407VGT6 để điều khiển các thiết bị như động cơ, van, cảm biến, v.v. Hệ thống này đã được kiểm tra và đánh giá về hiệu suất và độ tin cậy, và cho kết quả tốt hơn so với PLC HMI truyền thống.
- Một nghiên cứu của Đại học Kỹ thuật Quốc gia Athens, Hy Lạp, đã phát triển một hệ thống điều khiển công nghiệp cho một máy sản xuất bánh pizza, sử dụng stm32 touchgfx để tạo giao diện người dùng đồ họa và kết nối với một vi điều khiển STM32F429ZIT6 để điều khiển các thiết bị như băng tải, máy trộn, máy ép, v.v. Hệ thống này đã được kiểm tra và đánh giá về hiệu suất và độ tin cậy, và cho kết quả tương đương hoặc tốt hơn so với PLC HMI truyền thống.
- Một nghiên cứu của Đại học Kỹ thuật Hà Lan, Hà Lan, đã thiết kế và xây dựng một hệ thống điều khiển công nghiệp cho một máy pha cà phê, sử dụng stm32 touchgfx để tạo giao diện người dùng đồ họa và kết nối với một vi điều khiển STM32F746NGH6 để điều khiển các thiết bị như bơm, van, nhiệt kế, v.v. Hệ thống này đã được kiểm tra và đánh giá về hiệu suất và độ tin cậy, và cho kết quả tốt hơn so với PLC HMI truyền thống.

Như vậy, có thể thấy rằng stm32 touchgfx là một nền tảng phát triển giao diện người dùng đồ họa hiệu quả và tiết kiệm cho các ứng dụng điều khiển công nghiệp, có thể thay thế PLC HMI trong nhiều trường hợp. Tuy nhiên, stm32 touchgfx cũng có một số hạn chế như:

- Yêu cầu kỹ năng lập trình cao: stm32 touchgfx yêu cầu người dùng phải có kỹ năng lập trình C/C++ và hiểu biết về vi điều khiển stm32, cũng như các giao thức truyền thông và các thiết bị điều khiển công nghiệp. Điều này có thể gây khó khăn cho những người không có nền tảng kỹ thuật.
- Không tương thích với các thiết bị khác: stm32 touchgfx chỉ hỗ trợ vi điều khiển stm32 của STMicroelectronics, do đó không thể kết nối với các thiết bị sử dụng vi điều khiển khác hoặc các PLC HMI khác. Điều này có thể gây hạn chế cho việc mở rộng hoặc tích hợp hệ thống.

Do đó, stm32 touchgfx là một giải pháp phù hợp cho những người có kỹ năng lập trình cao và muốn tạo ra các giao diện người dùng đồ họa chuyên nghiệp và độc đáo cho các ứng dụng điều khiển công nghiệp. Tuy nhiên, stm32 touchgfx cũng cần được cải tiến về khả năng tương thích và dễ sử dụng để có thể phổ biến rộng rãi hơn trong tương lai.
1.2.2 Các kết quả nghiên cứu trong nước:
Stm32 touchgfx hiện tại là chưa phổ biến ở Việt Nam do nhiều lý do như giá thành cao, thiếu tài liệu hướng dẫn bản ngữ, khó khăn trong việc cài đặt và sử dụng.

### 1.3. Mục tiêu nghiên cứu của đề tài:

Hệ thống PCS hãng Festo đang có tại Trường CĐ KT Cao Thắng dùng để dạy môn thực hành cơ điện tử 2 sử dụng bộ điều khiển bằng EASY PORT hoặc PLC S7-1200và HMI khó khăn trong việc bảo trì, sửa chữa thay thế, giá thành cao nên đề tài này sử dụng vi điều kiển STM32 thay thế nhằm giảm giá thành, chủ động trong thay thế sữa chữa cũng như nâng cao chất lượng việc sử dụng vi điều khiển, lập trình nhúng trong sinh viên ngành cơ điện tử.

### 1.4. Nhiệm vụ của đề tài và giới hạn đề tài

1.4.1 Nhiệm vụ đề tài:
Thiết kế thi công bảng điện dễ dàng lắp đặt với hệ thống hiện có mà không làm thay đổi cấu trúc chung, dễ dàng thay đổi linh hoạt giữa các bộ điều khiển bằng EASY PORT và PLC S7-1200 hiện có.

Thiết kế chế tạo mạch chuyển đổi tín hiệu ngõ ra, ngõ vào 0V-24V thành tín hiệu 0V-3.3V kết nối với Vi điều khiển STM32

Thiết kế chế tạo mạch chuyển đổi tín hiệu ngõ ra, ngõ vào analog 0-10V sẵn có thành tín hiệu 0V-3.3V giao tiếp với vi điều khiển STM32.

Lập trình bộ điều khiển PID trên vi điều khiển STM32

Thiết kế giao diện điều khiển thuật toán PID với đối tượng mức

1.4.2 Giới hạn đề tài:
Đề tài được nghiên cứu điều khiển các quá trình mức, lưu lượng và áp suất trên mô hình PCS của hãng Festo.

## Chương 2: CƠ SỞ LÝ THUYẾT

### 2.1. Tổng quan về board Stm32f469 DISC

Stm32f469 DISC là một bộ kit phát triển dựa trên vi điều khiển STM32F469NIH6 có hiệu năng cao với lõi ARM Cortex-M4 và Chrom-ART Accelerator. Bộ kit cho phép người dùng phát triển các ứng dụng đa dạng tận dụng các tính năng đồ họa, âm thanh, cảm biến, màn hình màu WVGA, bảo mật, mở rộng bộ nhớ và kết nối. Bộ kit có sẵn trình gỡ lỗi/programmer ST-LINK/V2-1 tích hợp; các bo mạch mở rộng chuyên biệt có thể được kết nối nhờ các cổng Arduino UNO hoặc các cổng mở rộng. Bộ kit cũng có màn hình LCD TFT 4 inch 800x480 pixel với giao tiếp MIPI DSI và màn hình cảm ứng điện dung, DAC âm thanh SAI, jack cắm tai nghe stereo, 3 micro MEMS, khe cắm thẻ MicroSD, bộ nhớ SDRAM 4Mx32bit, bộ nhớ Flash Quad-SPI 128-Mbit và nhiều tính năng khác .

### 2.2. Tổng quan về lõi ARM® Cortex®-M4

Lõi ARM® Cortex®-M4 là một bộ xử lý nhúng hiệu năng cao được phát triển để đáp ứng các thị trường điều khiển tín hiệu số yêu cầu một sự kết hợp hiệu quả và dễ sử dụng giữa khả năng điều khiển và xử lý tín hiệu. Lõi Cortex-M4 có các tính năng và lợi ích sau :

- Hỗ trợ đơn vị tính toán dấu chấm động (FPU) với định dạng IEEE 754-2008.
- Hỗ trợ giao tiếp song song và nối tiếp với các giao thức khác nhau .
- Hỗ trợ gỡ lỗi và theo dõi với các thành phần MPU, NVIC, DWT, AHB, TPIU.

Lõi Cortex-M4 được thiết kế để phục vụ cho nhiều ứng dụng như điều khiển công nghiệp, cảm biến IoT, trí tuệ nhân tạo, xử lý âm thanh và hình ảnh. Lõi Cortex-M4 có thể hoạt động ở tốc độ lên đến 240 MHz và có khả năng xử lý 1.25 DMIPS/MHz. Lõi Cortex-M4 là một trong những lõi vi xử lý ARM phổ biến nhất hiện nay.

### 2.3. Tổng quan về nền tảng stm32 touch gfx

STM32 touch gfx là một nền tảng đồ họa nâng cao và miễn phí được tối ưu hóa cho các vi điều khiển STM32. STM32 touch gfx cho phép tạo ra các giao diện người dùng đẹp mắt và trơn tru trên các thiết bị nhúng, từ các ứng dụng đơn giản với ít màu sắc đến các ứng dụng phức tạp với độ phân giải và màu sắc cao. STM32 touch gfx tận dụng các khả năng phần cứng, kiến trúc và hệ sinh thái của STM32 để tăng tốc quá trình phát triển giao diện người dùng.

STM32 touch gfx có kích thước nhỏ gọn, chỉ cần một lượng bộ nhớ hạn chế để chạy các giao diện người dùng mượt mà. STM32 touch gfx có thể chạy với RTOS hoặc trên bare metal, hỗ trợ các vi điều khiển STM32 dựa trên các bộ xử lý Arm Cortex-M0+, M3, M4, M33 và M7.
2.4. Bộ điều khiển PID
Bộ điều khiển PID là một loại bộ điều khiển phản hồi phổ biến trong các hệ thống tự động hóa công nghiệp. Bộ điều khiển PID sử dụng ba thành phần cơ bản: đạo hàm (D), tích phân (I) và tỷ lệ (P) để tính toán một tín hiệu điều khiển dựa trên sự chênh lệch giữa giá trị mong muốn và giá trị thực tế của một biến quá trình. Bộ điều khiển PID có thể điều chỉnh độ nhạy, thời gian đáp ứng và độ ổn định của hệ thống bằng cách thay đổi các thông số P, I và D. Bộ điều khiển PID được ứng dụng rộng rãi trong các lĩnh vực như điều khiển nhiệt độ, áp suất, lưu lượng, tốc độ, vị trí và nhiều biến quá trình khác.

## Chương 3: GIỚI THIỆU MÔ HÌNH

### 3.1 Bơm:

Giới thiệu đặc tính bơm, các thông số cơ bản, vai trò của bơm trong hệ thống

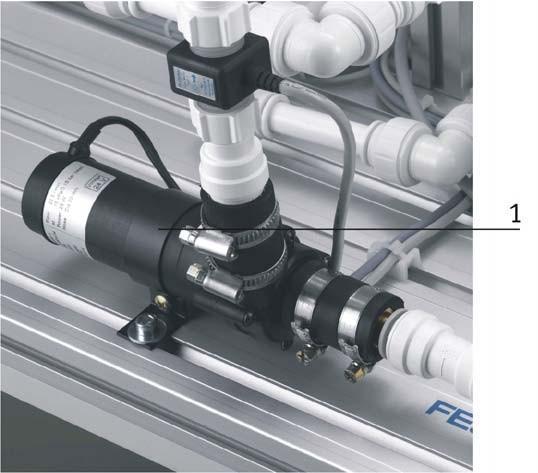
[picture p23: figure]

Hình 3.1 Cụm bơm

Máy bơm không được vận hành khi chạy khô. Trước khi vận hành thử, bể chứa hoặc hệ thống đường ống đến / từ máy bơm phải được đổ đầy chất lỏng.

Bơm được dẫn động bởi bộ điều khiển động cơ A4 và rơ le K1. Với đầu ra kỹ thuật số (O2 tại XMA1), có thể chuyển từ điều khiển nhị phân kỹ thuật số sang biến điều khiển tương tự từ 0 đến 24 V. Tại điều khiển nhị phân kỹ thuật số (O2 = 0), máy bơm được bật / tắt với một đầu ra bổ sung (O3 tại XMA1). Ở điều khiển tương tự (O2 = 1), điện áp biến tần từ kênh tín hiệu đầu ra tương tự 0 (UA1 tại X2) đang cài đặt tốc
độ của bơm từ 0 đến 10 V.

### 3.2 Chức năng của bơm

Máy bơm cung cấp chất lỏng từ bể chứa qua hệ thống đường ống. Tốc độ dòng chảy được phát hiện nhờ cảm biến cánh gạt quang điện tử B102 (2) ở dạng giá trị thực. Giá trị thực tế cũng nên được giữ trên một tốc độ dòng chảy nhất định nếu xảy ra nhiễu loạn hoặc thay đổi điểm đặt.

Để điều khiển hệ thống, có thể sử dụng phần tử liên tục . Có hai chế độ hoạt động:

- Điều khiển tốc độ dòng chảy bằng máy bơm P101 như một hệ

thống được điều khiển. Giá trị thao tác là điện áp của máy

bơm, thiết lập tốc độ quay vòng.

- Điều khiển tốc độ dòng chảy bằng van tỷ lệ V106 như một hệ

thống được điều khiển. Giá trị thao tác là điện áp của cuộn

van, thiết lập hành trình của piston van. Máy bơm P101 đang

chạy với tốc độ quay vòng không đổi.

### 3.3 Bình chứa

3.3.1 Bình B101

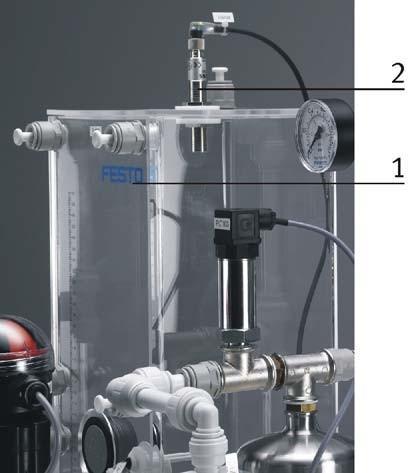
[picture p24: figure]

Hình 3.2


3.3.2 Bình áp suất B103

Hình 3-4 Bình chứa B102

Áp suất quá trình của chất lỏng bên trong bình tích áp phải được điều chỉnh. Hệ thống điều khiển áp suất được sử dụng là hệ

Hình 3.345Hình Bình ch Bình ch Bình ch 3.3ứa B102 thống được điều khiển có khả năng tự điều chỉnh (hệ thống điều khiển PT1). Bởi vì bình tích áp được làm đầy một phần khí (không khí) nên nó là một hệ thống lưu trữ năng lượng.

Thông qua hệ thống đường ống, máy bơm P101 cung cấp chất lỏng từ bồn chứa vào bồn chứa áp suất được bơm đầy khí B103 (1). Áp suất của khí (không khí) trong bình tích áp được phát hiện bằng cảm biến áp suất tương đối áp suất dưới dạng một giá trị thực tế. Giá trị thực tế cũng nên được giữ ở một áp suất nhất định nếu xảy ra nhiễu loạn hoặc thay đổi điểm đặt.

3.4 Van cầu đóng mở bằng khí nén


Hình 3-5
V102 lắp khớp được đóng mở bằng bộ truyền động khí nén. Thiết bị được điều khiển bao gồm một van bi bằng đồng (1) với kiểu ổ quay SYPAR (4), sử dụng nguyên lý chạy scotch. Một van điện từ
(2) 5/2 chiều (3) với kiểu cổng tới NAMUR và hộp cảm biến (5) được lắp mặt bích vào ổ quay. Dòng chảy của chất lỏng từ thùng trên B102 vào thùng dưới B101 được điều khiển bằng van bi của bộ truyền động quá trình.
Cấu tạo của van cầu
1. van bi đồng điện
2. van điện từ

3. Van 5/2 chiều với kiểu cổng tới kiểu ổ quay NAMUR
4. SYPAR, hộp cảm biến nguyên lý ổ cắm scotch
5. bao gồm hai công tắc vi điện với cần con lăn. Hai tín hiệu nhị

phân 24 VDC (S115 và S116) được kết nối làm đầu vào cho I

/ O-terminal XMA1. Ngoài ra còn có một chỉ dẫn trực quan về

vị trí ổ đĩa cho người vận hành.

3.4 Các cảm biến
3.1.1.1 Cảm biến siêu âm


Hình 3.6 cảm biến siêu âm

Chức năng:

− | Nguyên tắc hoạt động của cảm biến siêu âm dựa trên việc
| tạo ra sóng âm và phát hiện chúng sau phản xạ trên một vật thể. Thông thường, không khí trong khí quyển hoạt động như
| một vật mang sóng siêu âm.
− | Máy phát âm thanh được kích hoạt trong một khoảng thời gian ngắn và phát ra xung siêu âm mà tai người không nghe
| được. Sau khi phát xạ, xung siêu âm được phản xạ trên một vật thể nằm trong phạm vi và dội ngược trở lại máy thu.
| Khoảng thời gian của xung siêu âm được đánh giá bằng điện
| tử. Trong một phạm vi nhất định, tín hiệu đầu ra tỷ lệ với thời
| lượng tín hiệu của xung siêu âm. Đối tượng được phát hiện
| có thể được làm bằng các vật liệu khác nhau. Hình dạng hoặc

màu sắc, tình trạng rắn, lỏng hoặc bột không có bất kỳ hoặc

ảnh hưởng rất nhỏ đến việc phát hiện.

− | Trong trường hợp các vật thể có bề mặt nhẵn, đồng đều,
| bề mặt đó phải được căn chỉnh theo chiều dọc của chùm tia
| siêu âm.
− | Với loại cảm biến này, bạn có thể thực hiện hai loại phép
| đo: Đầu tiên, bạn có thể đo khoảng cách giữa cảm biến và
| một đối tượng. Thiết lập của nhà sản xuất của cảm biến là lý
| tưởng cho loại phép đo này. Tăng tín hiệu đầu ra ở khoảng
| cách tăng tới đối tượng.
− | Nhưng để đo mức đổ đầy của vật chứa, cần phải có một
| thiết lập khác vì khi mức lấp đầy tăng lên, khoảng cách của
| đối tượng được đo (mặt nước) đến cảm biến ngày càng nhỏ.
− | Do đó đầu ra tín hiệu được thay đổi từ đặc tính tăng sang
| đặc tính giảm. Ngoài ra, phạm vi đo đã được thay đổi để
| chúng tôi có thể nhận được tín hiệu đầu ra tối đa ở mức tối đa
| và tín hiệu đầu ra tối thiểu ở mức lấp đầy tối thiểu.

Thông số kĩ thuật:

Thông số | Giá trị
Bảo vệ | Kháng nước IP 67
Trọng lượng | Tối đa 67g
Nhiệt độ môi trường xung quanh | -25 đến 70°C
Lỗi điểm chuyển mạch | ± 2,5 % (-25 to 70°C)
Điện áp hoạt động định mức Ue | 24 V DC
Dải điện áp hoạt động UB | 20 ... 30 V DC (ở 12 ... 20 V DC giảm độ nhạy lên đến 20%)
Gợn sóng dư cho phép | 10%

Mức tiêu thụ hiện tại không hoạt động I0 | ‹ 50 mA
Công tắc đầu ra (NC / NO) / Đầu ra tần số (FA) Định mức hoạt động hiện tại tức là Điện áp rơi Ud | ≤ 150 mA ≤ 3 V at 150 mA
Đầu ra tương tự (UA / IA) Phạm vi hiện tại Sức tải | 4...20 mA 0...300 Ω
Cảm biến hoạt động | Điện áp hoạt động hoặc dòng điện đầu vào trở kháng cao IE. Tối đa 16 mA
Cảm biến không hoạt động | 0 ... 3 V Dòng đầu vào IE tối đa 11 mA

Bảng 3-1 thông số kĩ thuật cảm biến siêu âm
Chi tiết thiết lập:
Thông số | Giá trị
Phạm vi đo lường | Từ: 50mm Đến: 345mm
Phạm vi đo lường tối đa | Từ: 46mm Đến: 346mm
Tín hiệu đầu ra (Dòng điện) | 4…20 mA

Bảng 3-2 Thông số thiết lập cảm biến siêu âm

3.1.1.2Cảm biến siêu âm tương tự

Hình 3.7 cảm biến siêu âm

Chức năng:

− Nguyên tắc hoạt động của cảm biến siêu âm dựa trên việc

tạo ra sóng âm và phát hiện chúng sau phản xạ trên một vật thể.

Thông thường, không khí trong khí quyển hoạt động như một vật

mang sóng siêu âm. Máy phát âm thanh được kích hoạt trong một khoảng thời gian ngắn và phát ra xung siêu âm mà tai người không

nghe được. Sau khi phát xạ, xung siêu âm được phản xạ trên một vật thể nằm trong phạm vi và dội ngược trở lại máy thu. Khoảng

thời gian của xung siêu âm được đánh giá bằng điện tử. Trong một

phạm vi nhất định, tín hiệu đầu ra tỷ lệ với thời lượng tín hiệu của

xung siêu âm. Đối tượng được phát hiện có thể được làm bằng

các vật liệu khác nhau. Hình dạng hoặc màu sắc, tình trạng rắn,

lỏng hoặc bột không có bất kỳ hoặc ảnh hưởng rất nhỏ đến việc

phát hiện. Trong trường hợp các vật thể có bề mặt nhẵn, đồng đều,

bề mặt đó phải được căn chỉnh theo chiều dọc của chùm tia siêu

âm.

− Cảm biến siêu âm có thể được lắp ráp trên một giá đỡ bằng

cách sử dụng hai đai ốc đầu nối. Cảm biến có thiết kế hình trụ với

ren M30x1.

− | Cảm biến được bảo vệ chống phân cực ngược.
− | Đầu ra cảm biến cung cấp một dòng điện ấn tượng và được
| tải trong quá trình hoạt động ngắn mạch. Tốt nhất, đầu ra nên
| được tải với điện trở RL = 0 Ω.

Thômg số kĩ thuật:
Thông số | Giá trị
Điện áp hoạt động cho phép | 24 VDC
Tiêu thụ hiện tại (không tải) | ‹ 35 mA
Chịu tải | ‹ 400 Ω
Ngõ ra dòng điện | 4 ... 20 mA
Dải đo | 500 ... 150 mm
Khoảng cách tối thiểu giữa cảm biến và tường phản xạ bên | › 75 mm
Độ phân giải | 1 mm
Phạm vi nhiệt độ hoạt động / Môi trường xung quanh | –20 ... +75 °C
Đo tần số xung | 40 Hz
Bảo vệ phân cực ngược | có
Bảo vệ | Kháng nước IP 65
Vật liệu | Nhựa dẻo
Trọng lượng | 0,250 kg

Bảng 3-3 thông số kĩ thuật cảm biến siêu âm

3.1.1.3Cảm biến lưu lượng

Hình 3.8 cảm biến lưu lượng

Chức năng:

− Chất lỏng trong suốt được đưa vào theo hướng của mũi tên

được dẫn thành chuyển động tròn qua tấm xoáy trong buồng

đo và được dẫn vào rôto ba cánh gạt nhẹ. Tốc độ của rôto tỷ

lệ thuận với tốc độ dòng chảy và được phát hiện mà không

cần phản hồi thông qua hệ thống quang điện tử hồng ngoại

tích hợp (diode và phototransistor).

− Bộ khuếch đại tích hợp cung cấp tín hiệu sóng vuông ổn định,

theo đó mức tín hiệu phụ thuộc vào điện áp cung cấp được

áp dụng (5 đến 12 V DC).

− Do thiết kế đặc biệt của rôto, bất kỳ bong bóng khí nào (bọt

khí) có thể xuất hiện trong chất lỏng, sẽ không bị hòa tan mà

mang theo chất lỏng. Mọi vị trí lắp ráp đều được. Hướng của

dòng chảy được biểu thị bằng một mũi tên trên vỏ cảm biến.

Vùng ổn định lên hoặc xuống của thiết bị đo là không cần thiết.

− Các dao động hoặc xung tốc độ dòng chảy không có ảnh

hưởng tiêu cực đến kết quả đo.

− Một bộ lọc bảo vệ được lắp ở phía đầu vào.

− Tất cả các bộ phận của vỏ máy đo tiếp xúc với môi trường

được làm bằng polyvinylidene fluoride (PVDF)

Thông số kĩ thuật:

Thông số | Giá trị
Điện áp hoạt động cho phép | 5 ... 12 VDC
Mức tiêu thụ dòng | 6 ... 24 mA
Dải đo | 0,5 ... 15,0 l/phút
Độ tin cậy của phép đo | ± 1% trong số đo. Giá trị, tại 20 °C
Tuyến tính | ± 1% tại 20 °C
Phạm vi nhiêt độ tiêu chuẩn | 0°C... +65 °C
Bảo vệ phân cực ngược | có
Vật liệu | PVDF
Kích thước: Chiều dài Kết nối dây | 47mm M20x2
Kết nối điện | Cáp, dài 750 mm

Bảng 3-4 thông số kĩ thuật cảm biến lưu lượng
3.1.1.4 Cảm biến áp suất tương tự

Hình 3.9 cảm biến áp suất

Chức năng

− Cảm biến áp suất tương tự piezoresistive với bộ khuếch đại

tích hợp và bộ bù nhiệt độ được lắp vào một vỏ nhôm duy

nhất. Áp suất cần đo được truyền đến một phần tử tạo áp

lực. Do đó, tín hiệu được tạo ra được khuếch đại và xuất ra

dưới dạng điện áp tại đầu nối điện.

− Cảm biến áp suất tương tự được lắp vào hệ thống đường

ống thông qua đầu nối G ½ ”. Kết nối điện được thực hiện

bằng ổ cắm 3 chân.

1 Nguồn +24 VDC

2 Nối đất, 0 VDC

3 Đầu ra điện áp: 0 VDC đến 10 VDC

Thông số kĩ thuật

Thông số | Giá trị
Dải đo | 0 mbar đến 100 mbar
Quá tải | 2,5 bar
Cung cấp điện áp UB | 13 VDC đến 30 VDC
Tín hiệu đầu ra | 0 VDC đến 10 VDC
Mức tiêu thụ hiện tại | tối đa 25 mA ở đầu ra hiện tại tối đa. 5 mA ở đầu ra điện áp
Lỗi tuyến tính | ±0,5% f. s.
Thời gian đáp ứng | ≤1 ms

2

3
1

Tính lặp lại | ≤±0,1% v. f. s.
Trung bình | Nước
Màng | Thép không gỉ
Nhiệt độ môi trường tiêu chuẩn | 0 °C đến +65 °C
Kết nối điện | ổ cắm 3-pin
Kết nối quá trình | G ½ "ren vít bên ngoài, thép không gỉ
Trọng lượng | 250 g
Phạm vi nhiệt độ Phương tiện truyền thông Thiết bị điện tử Lưu trữ | -25°C đến +100°C -25°C đến +80°C -40°C đến +100°C

Bảng 3-5 thông số kĩ thuật cảm biến áp suất

Bảng 3-6 thông số kĩ thuật cảm biến áp suất

3.1.1.5Cảm biến tiệm cận điện dung


Hình 3.10 cảm biến tiệm cận điện dung

Chức năng

− Cảm biến tiệm cận có đầu ra PNP, tức là đường tín hiệu được

chuyển sang điện thế dương ở trạng thái được chuyển mạch.

Công tắc được thiết kế dưới dạng tiếp điểm thường mở.

− Tải được kết nối giữa đầu ra tín hiệu cảm biến và đất. Đi-ốt

phát sáng màu vàng (LED) cho biết trạng thái chuyển mạch.

Không thể lắp cảm biến tiệm cận điện dung.

− Cảm biến tiệm cận điện dung có thể được gắn qua một giá đỡ

góc và hai đai ốc khóa. Cảm biến có thiết kế hình trụ với ren

M18x1.

Thông số kĩ thuật

Thông số | Giá trị
Điện áp hoạt động cho phép | 10 ... 55 VDC
Chuyển đầu ra | PNP, Tiếp điểm thường mở
Khoảng cách chuyển đổi danh nghĩa | 2 ... 8 mm
Độ trễ (ở khoảng cách chuyển mạch danh nghĩa) | 3 ... 15 %
Chuyển mạch tối đa hiện tại | 200 mA
Tần số chuyển mạch tối đa | 300 Hz
Mức tiêu thụ hiện tại khi chạy không tải (ở 55 V) | 7 mA
Nhiệt độ môi trường hoạt động cho phép | 20 °C ... +70 °C
Bảo vê | Kháng nước IP 65

Bảo vệ phân cực ngược, cường độ ngắn mạch | có
Vật liệu | Nhựa nhiệt dẻo
Trọng lượng | 0,20 kg
Kết nối điện | Cáp, dài 2000 mm

Bảng 3-7 Thông số kỹ thuật cảm biến điện dung

## Chương 4: THIẾT KẾ THI CÔNG HỆ THỐNG NHÚNG

### 4.1 Xác định vấn đề:

Là hệ thống nhúng điều khiển các cổng I/O và các peripherals, thông qua màng hình cảm ứng. Chương trình phức tạp, nhiều trạng thái, nhiều event. Yêu cầu thời gian thực, đa nhiệm và chia sẻ tài nguyên. Thực toán có liên quan đến số thực. Cần phần mềm debug chuyên nghiệp phân tích và trực quan hóa hành vi thời gian thực của ứng dụng nhúng. Thời gian flash frontend và backend cùng lúc rất lâu.

Căn cứ vào các yêu cầu đó ta cần có:

- Phương pháp quản lý mã nguồn: áp dụng GIT để quản lý mã nguồn.
- IDE chuyên nghiệp: sử dụng Visual studio code để phát triển phần mềm.
- Phần mềm được chạy trên real time OS: cài freeRTOS cho phần mềm.
- Tách riêng forntend và backend để phát triển độc lập: tạo 1 project stm32 cho frontend, và 1 stm32 project cho backend để phát triển độc lập.

Chương trình được phân thành 2 lớp (layer):

Frontend và backend, frontend gồm các file chương trình C++ để điều khiển HMI, backend gồm các chương trình để điều khiển I/O, peripherals…


Hình 4.1 project frontend và backend

### 4.2 Xây dựng kiến trúc phần mềm

6.


Hình 4.2 kiến trúc của phần mềm

Stm32F469 : board stm32

CMSIS: là một tập hợp các định nghĩa, giao diện và thư viện phần mềm cho các vi điều khiển dựa trên lõi ARM Cortex-M. CMSIS giúp đơn giản hóa việc phát triển và tái sử dụng các ứng dụng phần mềm trên nhiều nền tảng phần cứng khác nhau.

STM32F469 HAL là một tập hợp các thư viện phần cứng trừu tượng cho các vi điều khiển STM32. Nó cung cấp các hàm API để tương tác với các ngoại vi như GPIO, UART, SPI, I2C.

STM32F469 LOW-LEVEL: là viết tắt của STM32 Low Layer. Đây là một bộ thư viện phần mềm cho các dòng vi điều khiển STM32, cung cấp các hàm API để truy cập trực tiếp vào các thanh ghi và bit của các module ngoại vi.

BSP: Board support packet là một tập hợp các phần mềm và tài liệu hỗ trợ cho việc phát triển ứng dụng trên một board nhúng cụ thể. Nó thường bao gồm các driver, bootloader, hệ điều hành, các thư viện và các công cụ phát triển. Board support packet giúp cho các nhà phát triển có thể tận dụng được các tính năng và khả năng của board mà không cần phải viết lại hoặc cấu hình lại các phần mềm cơ bản.

User firmware: firmware cấu hình và điểu khiểu GPIO, và các peripherals.

User app: Phần mềm bao gồm frontend và backend.

### 4.3 Phát triển firmware


Hình 4.3 Sơ đồ khối từ vi điều khiển đến hệ PCS

Hình 4.4 Sơ đồ các ngoại vi trong stm32f469

SignalType | STM32 Peripheral | STM32F469 Alternative Function | Peripheral Clock Bus | STM32F469 Pinout | Note
AnalogIn0 | ADC1 | ADC12_IN9 | APB2 | PB1
AnalogIn1 | ADC1 | ADC12_IN12 | APB2 | PC2
AnalogIn2 | ADC1 | ADC12_IN13 | APB2 | PC3
AnalogIn3 | ADC1 | ADC12_IN14 | APB2 | PC4
DigitalOutput0 | GPIOC | ADC12_IN15 | AHB1 | PC5
DigitalOutput1 | GPIOA | ADC12_IN4 | AHB1 | PA4
DigitalOutput2 | GPIOG | | AHB1 | PG9
DigitalOutput3 | GPIOG | | AHB1 | PG14
DigitalOutput4 | GPIOG | | AHB1 | PG13
AnalogOut0 | TIM5 | TIM5_CH2/PWM | APB1 | PA1 | 1.37 Khz
Non
AnalogOut1 | TIM5 | TIM5_CH3/PWM | APB1 | PA2 | 1.37 Khz
Non
DigitalInput0 | GPIOG | | AHB1 | PG11 | EXTI_LINE_11
DigitalInput1 | GPIOG | | AHB1 | PG10 | EXTI_LINE_10
DigitalInput2 | GPIOA | | AHB1 | PA7 | EXTI_LINE_7
DigitalInput3 | GPIOH | | AHB1 | PH6 | EXTI_LINE_6
DigitalInput4 | GPIOB | | AHB1 | PB15 | EXTI_LINE_15
DigitalInput5 | GPIOB | | AHB1 | PB14 | EXTI_LINE_14
DigitalInput6 | GPIOD | | AHB1 | PD3 | EXTI_LINE_3
Bảng 4-1 bảng thiết lập firmware

4.3.1 Firmware PID
Ứng dụng thư viện PID có sẵn cho stm32. Viết trên ngôn ngữ C

Có chức năng tính toán PID theo kP, kI, kD.

Có thể tùy chỉnh được thời gian lấy mẫu.

Yêu cầu từ thư viện:Thư viện yêu cầu cung cấp 1 hàm với chức năng là trả về giá trị của system ticks kiểu dữ liệu uint32_t.


Hình 4.5 cung cấp 1 hàm với chức năng là trả về giá trị của system ticks.

4.3.2 Firmware External Interrupt
Xây đựng cấu hình theo yêu cầu: Trigger edge : falling and rising, các chân từ ARD_D7 đến ARD_D13.

4.3.3 Firmware PWM
- Xây đựng cấu hình theo yêu cầu: Sử dụng timer 5 pwm out channel 2 và channel 3, Xung PWM có tần số trong đoạn [1000 -3000] Hz. Sử dụng ngắt tràng để update giá trị dutyCycle

4.3.4 Firmware ADC
4.3.5 Firmware Digital Output

### 4.4 Các task của phần mền:

Việc áp dụng hệ điều hành dẫn đến việc cần thiết kết các task cho hệ thống.

Task là một đơn vị cơ bản của hệ điều hành thời gian thực (RTOS). Một task có thể được hiểu như một chương trình con độc lập, thực hiện một nhiệm vụ cụ thể.

Vậy ta xây các task như là: task tính toán PID, task đọ và gửi dữ liệu analog, task xử lý đồ họa. các task này sẽ hoạt động song song với nhau.


Hình 4.6 Các tác vụ (task) của chương trình

4.4.1 Task::readAnalog


Hình 4.7 sơ đồ, task::ADC


4.4.2 Task::Pwm

Hình 4.8 activity diagram pwm task

4.4.3 Task::PwmPid

Hình 4.9 activity diagram Task::PwmPid


4.4.4 Task::digitalOutput

Hình 4.10 activity diagram Task::DigitalOutput
4.4.5 Task::Digital Input

Hình 4.11 activity diagram Task::digitalInput

4.4.6 Task::PidComputing


Hình 4.12 activity diagram task::PidComputing

Hình 4.13 class
diagram pid
parameter

## Chương 5: Chọn linh kiện – thiết kế bảng điện

### 5.1 Chọn các module chuyển đổi tính hiệu

5.1.1 Module::PWM2AnalogConv

Hình 5.0.1 Module::PWM2AnalogConv Module::Input : xung PWM logic level 5v, 1000Hz – 3000Hz

Module::Output : tính hiệu analog 0 – 10v

Module::powerSupply : DC 24v

5.1.2 Module::Opto-isolator 4 channels


Hình 5.0.2 Module::Opto-isolator 4 channels

Module::Input : tín hiệu digital logic level 5v - 24v cho từng kênh

Module::powerSupply : không

5.1.3 Module::Relay 4 channel


Hình 5.0.3 Module::Relay 4 channel

Module::Input : tín hiệu digital logic level 5v cho từng kênh

Module::Output : đóng/mở tiếp điểm relay

Module::powerSupply : DC 5v

5.1.4 Analog 0 – 10V to Analog 0 – 3.1V


Hình 5.0.4 Analog 0 – 10V to Analog 0 – 3.1V module Ứng dụng nguyên lý mạch chia áp

Tự làm mạch chia áp cho 4 kênh analog.

Module::Input : tín hiệu analog 0 - 10V cho từng kênh

Module::Output : tín hiệu analog 0 – 3.1V từng kênh

Module::powerSupply : không (linh kiện điện tử thụ động)

## Chương 6: Thiết kết giao diện người dùng

### 6.1 Tổng quan nền tảng stm32TouchGfx

Stm32TouchGfx là một nền tảng phần mềm cho phép thiết kế giao diện người dùng (GUI) trên các thiết bị nhúng sử dụng vi điều khiển STM32. stm32TouchGfx cung cấp một bộ công cụ tích hợp (IDE) cho phép người dùng tạo, chỉnh sửa và xem trước các GUI trên máy tính, sau đó biên dịch và tải chúng lên thiết bị nhúng. stm32TouchGfx hỗ trợ nhiều loại màn hình cảm ứng, đồ họa 2D và 3D, hiệu ứng chuyển động, âm thanh và nhiều tính năng khác.

Hình 6.0.1 logo touch gfx

### 6.2 Thiết kế giao diện người dùng trên stm32TouchGfx

Để thiết kế giao diện người dùng trên stm32TouchGfx, người dùng cần thực hiện các bước sau:

- Tạo một dự án mới trong IDE của stm32TouchGfx, chọn loại vi điều khiển STM32, loại màn hình cảm ứng và các thư viện phần mềm cần thiết.
- Thêm các widget (các thành phần giao diện như nút, thanh trượt, văn bản, hình ảnh, ...) vào màn hình chính của GUI, sắp xếp vị trí và kích thước của chúng theo ý muốn.
- Thiết lập các thuộc tính của các widget, như màu sắc, kiểu chữ, hình nền, hiệu ứng, ...
- Tạo các sự kiện (event) và hành động (action) cho các widget, như khi nhấn, kéo, thả, vuốt, ... Các sự kiện và hành động có thể được lập trình bằng ngôn ngữ C++ hoặc kéo thả trong IDE.


- Xem trước GUI trên máy tính hoặc thiết bị nhúng, kiểm tra tính năng và hiệu suất của nó.
- Biên dịch và tải GUI lên thiết bị nhúng, thử nghiệm và sửa lỗi nếu có.

Hình 6.0.2 Giao diện thiết kế đồ họa của Touch gfx

### 6.3 Menu::screen

Hình 6.0.3 Menu::screen

### 6.4 Screen::SettingVar


Hình 6.0.4 Screen::SettingVar 6.5 Screen::ClosedLoopControl

Hình 6.0.5 Screen::ClosedLoopControl

### 6.6 Screen::ClosedLoopSetting


Hình 6.0.6 Screen::ClosedLoopSetting (1)

Hình 6.0.7 Screen::ClosedLoopSetting (2)

## Chương 7: Thực Nghiệm

### 1. Thực nghiệm xác định hệ số factor và offet của cảm biến

Thực nghiệm với cảm biến áp xuất, đầu tiên cho đóng/mở các van sao cho nước được bơm vào bình áp suất, vào màng hình setting var, chọn chế độ điều khiển bơm là analog, kéo thanh slider của bơm tối đa, để công suất của bơm cực đại. Lúc này ta thấy giá trị analog của cảm biến áp suất là 4.79v, giá trị hiển thị trên áp suất kế là 250 mbar. Tiếp tục thay đổi thanh slider của bơm tại 1 vị trí khác bất kỳ, ta được cặp số tương ứng 2.1V và 100 mbar.

Vì cảm biến là tuyến tính. Ta có thể tìm factor và offet bằng cách lập hệ phương trình:
{

250 = 4.79f + o
100 = 2.1f + o

giải hệ phương trình ta được:
{

f = 55,76
o = −17.09

Ta nhập 55.75 ở ô factor Ch.2 và -17.09 ở ô offset Ch.2

Sau đó nhấn nút tick để lưu và hệ thống cập nhật 2 giá trị.

Hình 7.0.1 nhập offset và factor

### 2. Thực nghiệm điều khiển PID

Điều khiển lưu lương:


Vào màng hình điều khiển pid, đóng/mở các van sao cho nước được bơm chạy qua cảm biến lưu lượng. Trên màng hình, mở digital 1, chọn bơm ở chế độ analog,

Hình 7.0.2 mở chế độ bơm analog

Sau đó chọn set

Hình 7.0.3 chọ set vào screen::SetingVar
Chon nhấn vào nút Actuator để chọn hệ điều khiển.


Hình 7.0.4 Chọn hệ điều khiển Chọn Flow rate và ấn vào nút tick xanh.

Sau đó tiến hành nhập các hệ số Kp = 1, Ti = 3, Td = 0 và set point = 100 như mong muốn. Ấn Confirm để hoàn tất cài đặt.

Hình 7.0.5 nhấn Start
Nhấn start để chạy, ta được biểu đồ như trên.

### 3. Một số biểu đồ đã thực nghiệm


Hình 7.0.6 Biểu đồ điều khiển mức nước với Kp = 10

Hình 7.7 Biểu đồ điều khiển lưu lượng với Kp = 1, Ti =3

## Chương 8: Kết quả và hướng nghiên cứu

### 8.1 Mục tiêu đã đạt được

Dùng vi điều khiển điều khiển đọc và điều khiển các thiết bị chuẩn công nghiệp.
Thiết kế và lập trình giao diện người dùng cho vi điều khiển.

Điều khiển mức nước, lưu lượng, và áp suất bằng thuật toán PID với chất lượng tương đượng hệ điều khiển bằng EASY PORT và PLC s7-1200 hiện có.

### 8.2 Hướng nghiên cứu

Có thể phảt triển tiếp theo hướng IOT, sử dụng vi điều khiển và màng hình cảm ứng kết hợp với các giải phải IOT để điều khiển hệ từ xa.

## TÀI LIỆU THAM KHẢO

STM32F469xx and STM32F479xx advanced Arm®-based 32-bit MCUs, Reference manual, STMicroelectronics
STM32F469xx Data sheet , Data sheet, STMicroelectronics
TouchGFX Documentation, STMicroelectronics
SEGGER system view Recording and analyzing runtime
behavior of embedded systems, User Guide, SEGGER Microcontroller GmbH
Richard Barry, Mastering the FreeRTOS™ Real Time Kernel A Hands-On Tutorial Guide, Tutorial book
Nguyễn Thị Phương Hà, Huỳnh Thái Hoàng, Lý thuyết điều khiển tự động, Nhà xuất bản đại học quốc gia Thành Phố Hồ Chí Minh, 2005. Bảng 9-1 Bảng tài liệu tham khảo

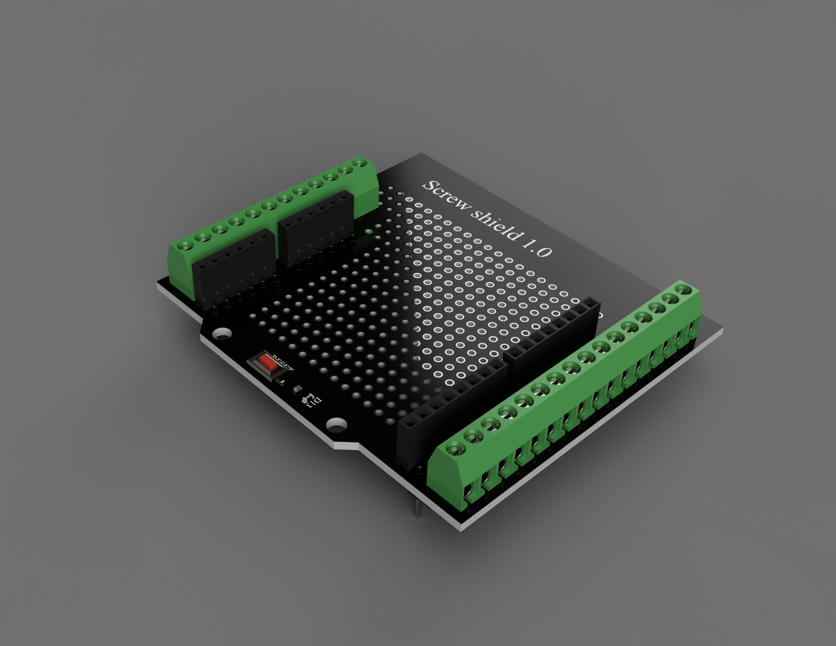
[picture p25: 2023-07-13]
Doc/bv h.Anh/arduino-uno-screw-shield-1.snapshot.9/0467bda1-4859-41b6-84f7-e0f14bcb8b81.PNG

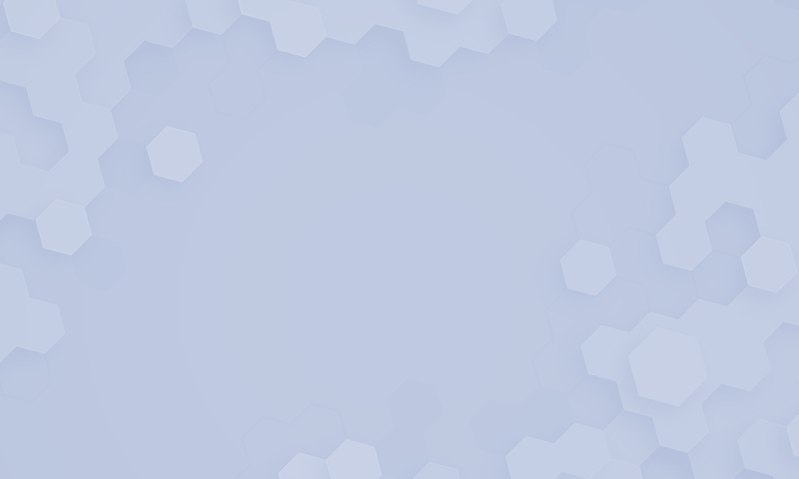
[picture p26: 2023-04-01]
HMI_FPAC_BACKEND/TouchGFX/assets/images/__generated/clay_theme_images_backgrounds_800x480_puzzle.png

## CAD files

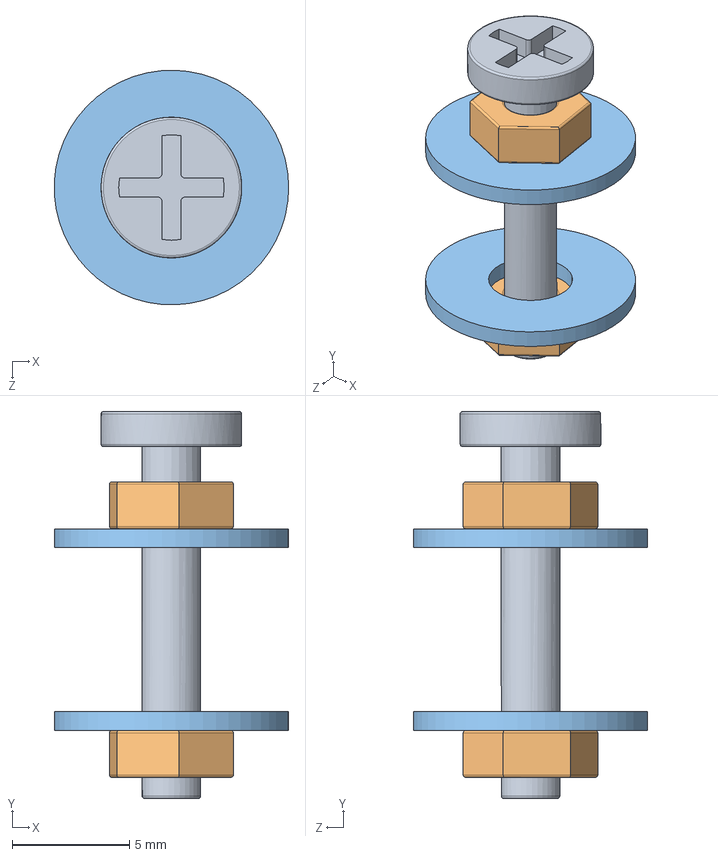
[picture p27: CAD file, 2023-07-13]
Doc/bv h.Anh/ban dien/cum m3.SLDASM
9.99 x 16.5 x 10.00 mm
m3
dai oc m3 x 2
long den m3 x 2

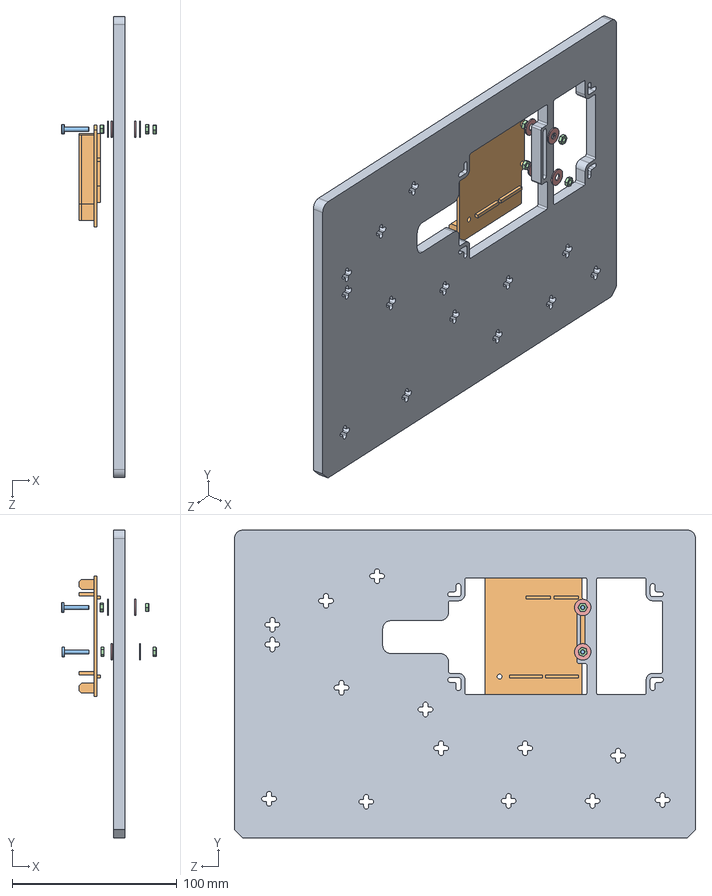
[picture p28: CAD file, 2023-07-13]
Doc/bv h.Anh/ban dien/step.SLDASM
57.5 x 187.0 x 280.0 mm
de
m3 x 2
dai oc m3 x 4
long den m3 x 4

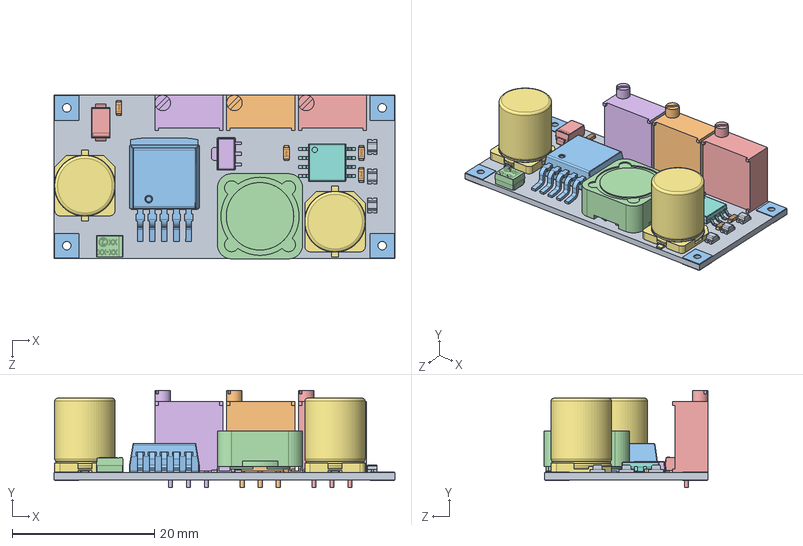
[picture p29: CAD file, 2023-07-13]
Doc/bv h.Anh/ban dien/lm 2596.SLDASM
48.0 x 13.7 x 23.1 mm
PCB^DC-DC
Trimmer 3296^DC-DC
TO263-5-1^DC-DC
DR125 series^DC-DC
Trimmer 3296^DC-DC_3
Trimmer 3296^DC-DC_2
CAPAE-D8.0x10.2^DC-DC x 2
SO-8 208mil^DC-DC___ _________
LED-0805h1.1^DC-DC x 3
Resistor 0603^DC-DC x 4
Connecting pin^DC-DC x 8
TR3 B-CASE^DC-DC
SMA DO-214AC^DC-DC
TO-243AA^DC-DC

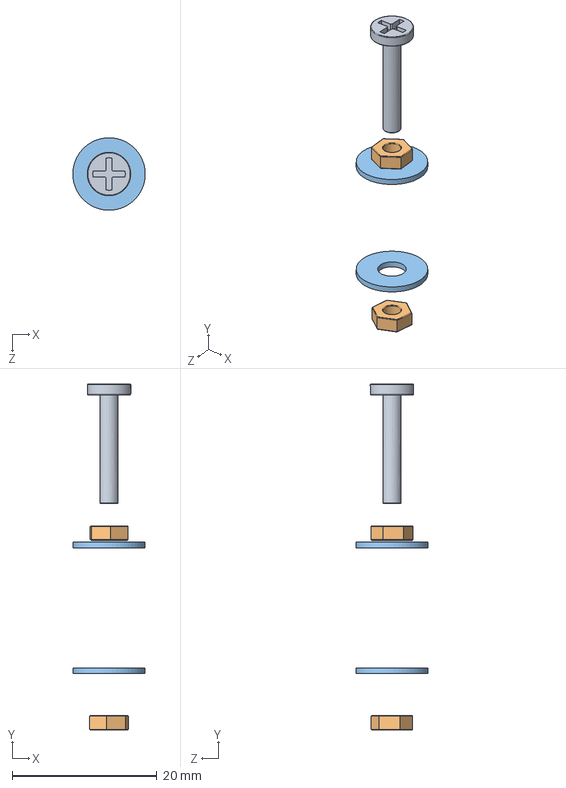
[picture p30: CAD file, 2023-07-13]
Doc/bv h.Anh/ban dien/cum m3 1.1.SLDASM
9.99 x 47.7 x 10.00 mm
m3
dai oc m3 x 2
long den m3 x 2

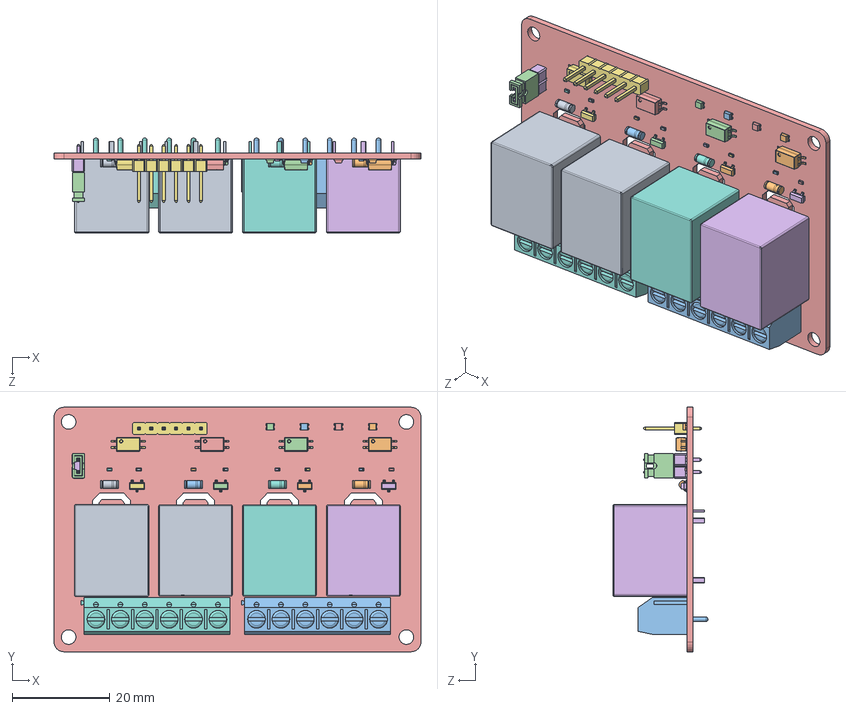
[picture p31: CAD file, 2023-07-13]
Doc/bv h.Anh/ban dien/New folder/4_Relay_module.SLDASM
75.2 x 50.1 x 19.4 mm
Relay001
Optolop
Optolop001
Optolop002
Relay004
Optolop003
Relay003
Relay002
BL-LS0805UWC
PZ_TransistorSMD002
6pin
SOD-80C
BL-LS0805UWC002
BL-LS0805UWC003
BL-LS0805UWC001
2pin
PZ_TransistorSMD003
SOD-80C001
SOD-80C003
PZ_TransistorSMD001
SOD-80C002
2Pin_jumper
PZ_TransistorSMD

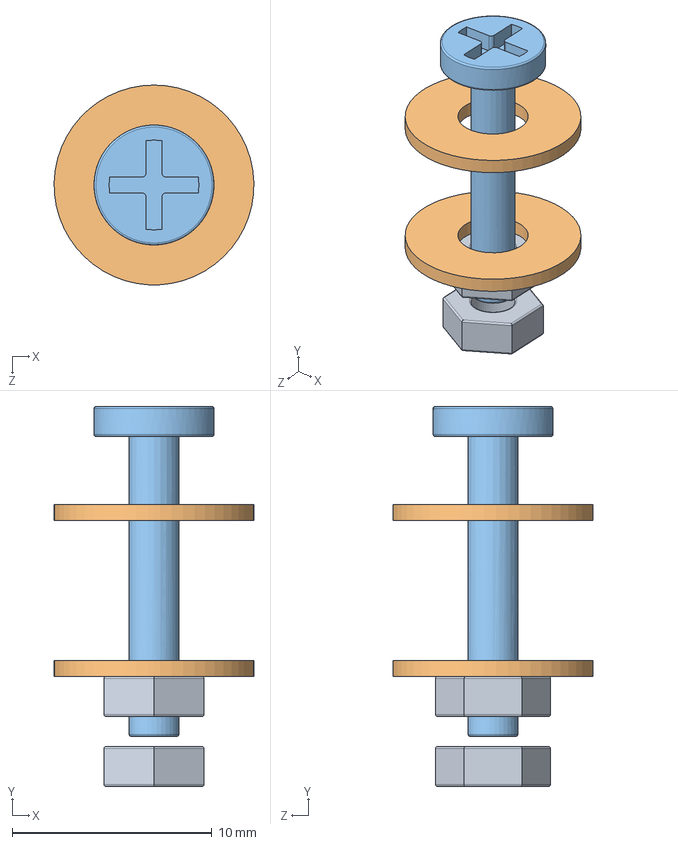
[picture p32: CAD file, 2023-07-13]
Doc/bv h.Anh/ban dien/cum m3 2.SLDASM
10.00 x 19.0 x 10.0 mm
dai oc m3 x 2
long den m3 x 2
m3

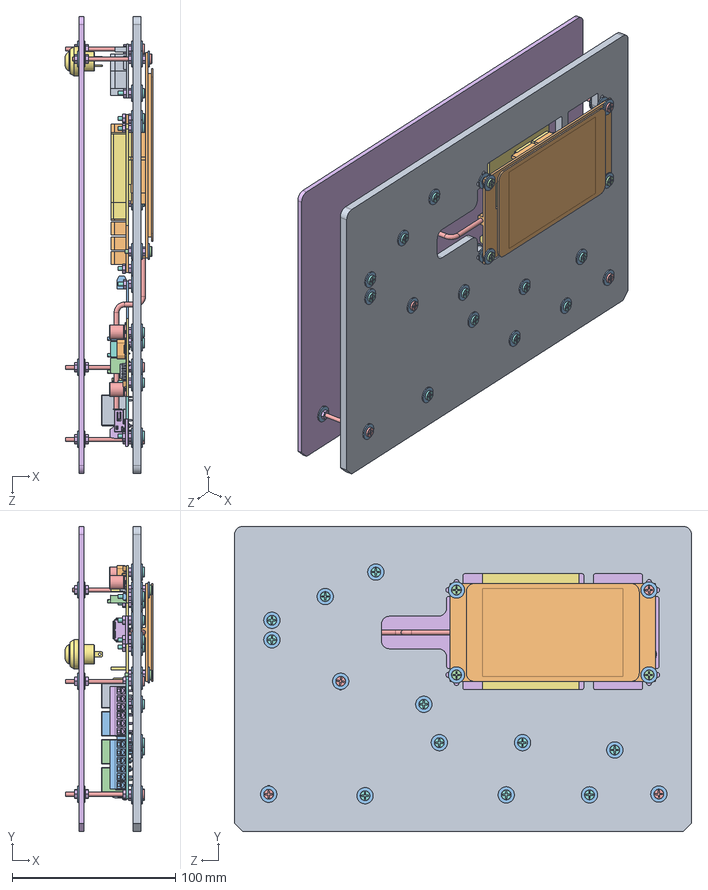
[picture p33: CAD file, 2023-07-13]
Doc/bv h.Anh/ban dien/ban dien.SLDASM
53.8 x 187.0 x 280.0 mm
de
man hinh
long den m3 x 52
m3x25 x 3
m3x30 x 4
dai oc m3 x 48
screw shield
m3 x 13
Relay001
Optolop
Optolop001
Optolop002
Relay004
Optolop003
Relay003
Relay002
BL-LS0805UWC
PZ_TransistorSMD002
6pin
SOD-80C
BL-LS0805UWC002
BL-LS0805UWC003
BL-LS0805UWC001
2pin
PZ_TransistorSMD003
SOD-80C001
SOD-80C003
PZ_TransistorSMD001
SOD-80C002
2Pin_jumper
PZ_TransistorSMD
USB2A_Female_DIP2,54_PCB_adapter board
PCB^DC-DC
Trimmer 3296^DC-DC
TO263-5-1^DC-DC
DR125 series^DC-DC
Trimmer 3296^DC-DC_3
Trimmer 3296^DC-DC_2
CAPAE-D8.0x10.2^DC-DC x 2
SO-8 208mil^DC-DC___ _________
LED-0805h1.1^DC-DC x 3
Resistor 0603^DC-DC x 4
Connecting pin^DC-DC x 8
TR3 B-CASE^DC-DC
SMA DO-214AC^DC-DC
TO-243AA^DC-DC
day cap
tam lot
nut reset

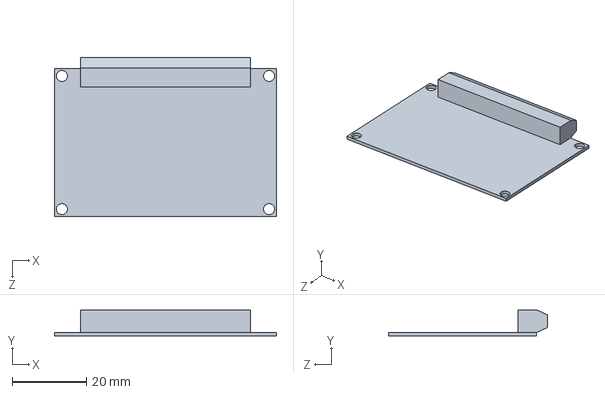
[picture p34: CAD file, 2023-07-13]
Doc/bv h.Anh/ban dien/4.SLDPRT
60.0 x 7.00 x 43.0 mm

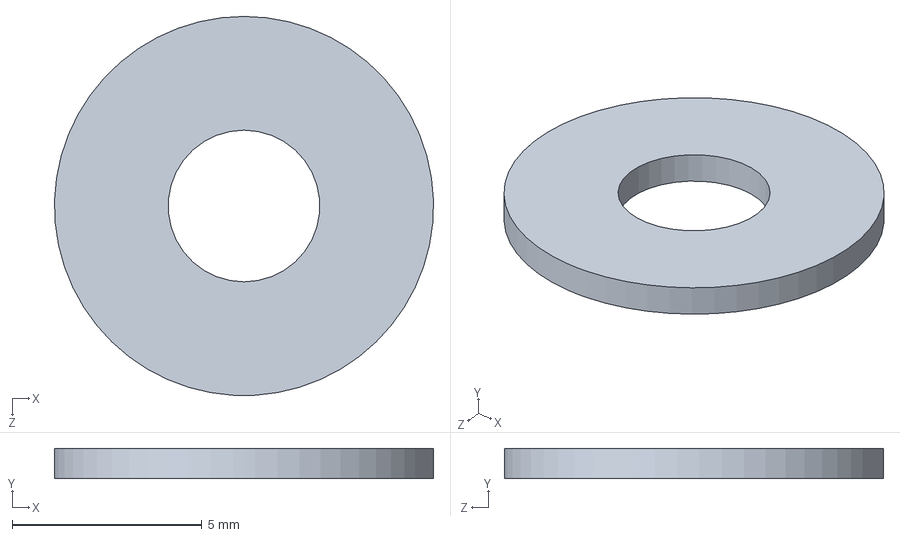
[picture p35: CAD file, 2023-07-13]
Doc/bv h.Anh/ban dien/long den m3.SLDPRT
10.00 x 0.8 x 10.0 mm

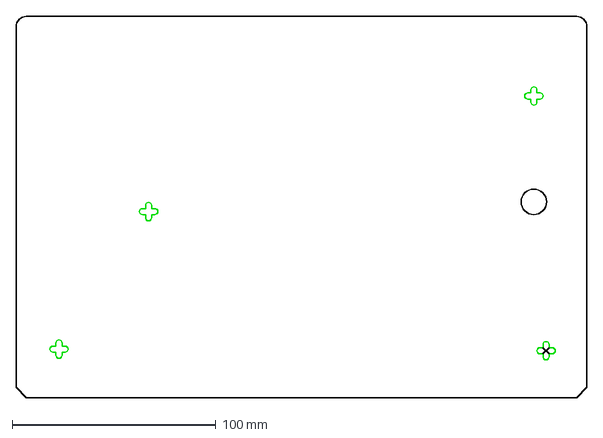
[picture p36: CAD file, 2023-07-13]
Doc/bv h.Anh/mica/bv cat mica 3mm.dxf
280.0 x 187.0 mm

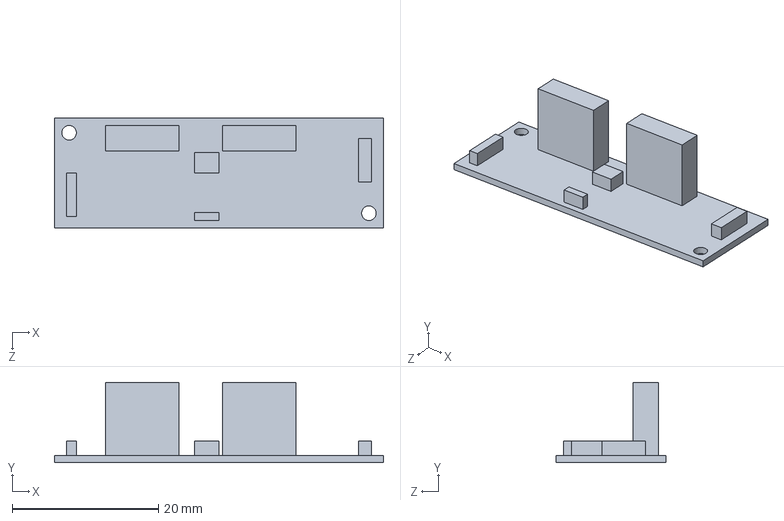
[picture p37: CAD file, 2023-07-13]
Doc/bv h.Anh/ban dien/2.SLDPRT
45.0 x 11.0 x 15.0 mm

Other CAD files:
Doc/bv h.Anh/ban dien/New folder/SOD-80C001.sldprt
Doc/bv h.Anh/mica/bv cat mica 5mm.dwg
Doc/bv h.Anh/ban dien/New folder/Compound008.sldprt
Doc/bv h.Anh/ban dien/New folder/Compound007.sldprt
Doc/bv h.Anh/ban dien/TO263-5-1^DC-DC.sldprt
Doc/bv h.Anh/mica/de.DWG
Doc/bv h.Anh/ban dien/New folder/Compound001.sldprt
Doc/bv h.Anh/arduino-uno-screw-shield-1.snapshot.9/Arduino Uno Screw Shield.f3d
Doc/bv h.Anh/ban dien/1.SLDPRT
Doc/bv h.Anh/ban dien/2d/1.SLDDRW
Doc/bv h.Anh/ban dien/2d/2.SLDDRW
Doc/bv h.Anh/ban dien/2d/2d/2.SLDDRW
Doc/bv h.Anh/ban dien/2d/2d/3.SLDDRW
Doc/bv h.Anh/ban dien/2d/2d/4.SLDDRW
Doc/bv h.Anh/ban dien/2d/2d/STEP 3.SLDDRW
Doc/bv h.Anh/ban dien/2d/2d/STEP 4.SLDDRW
Doc/bv h.Anh/ban dien/2d/2d/STEP 5.SLDDRW
Doc/bv h.Anh/ban dien/2d/2d/STEP 6.SLDDRW
Doc/bv h.Anh/ban dien/2d/2d/STEP 7.SLDDRW
Doc/bv h.Anh/ban dien/2d/2d/STEP 8.SLDDRW
Doc/bv h.Anh/ban dien/2d/2d/STEP 9.SLDDRW
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

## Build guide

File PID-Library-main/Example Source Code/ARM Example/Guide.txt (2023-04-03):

~ Author   : Majid Derhambakhsh
~ Created  : 11/28/2021
~ Support  : Majid.Derhambakhsh@outlook.com
~ Github ID: Majid-Derhambakhsh

- MCU                  : STM32F103C8T
- Compiler             : STM32CubeIDE.
- Library              : HAL Library.
- Programming language : C

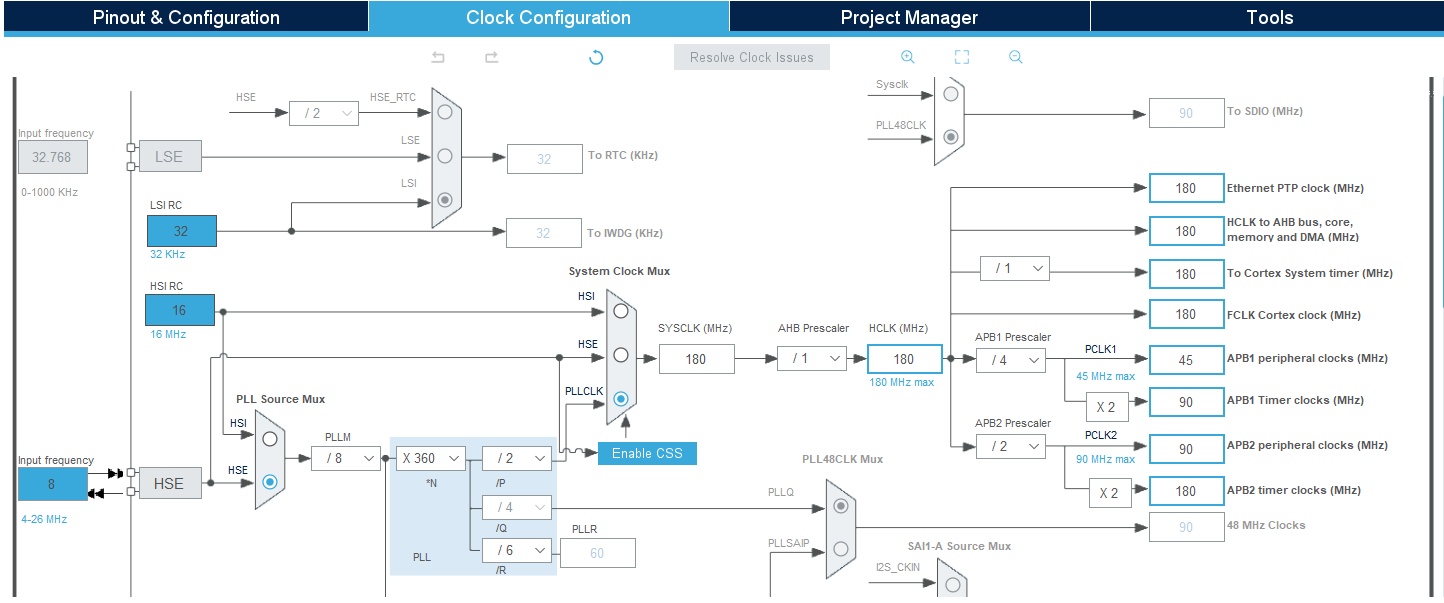
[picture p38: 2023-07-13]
Doc/Print/ClockDiagramProject.png

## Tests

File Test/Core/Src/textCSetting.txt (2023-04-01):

{
    "configurations": [
        {
            "name": "Win32",
            "includePath": [
                "${workspaceFolder}/**",
                "${workspaceFolder}/**/Core/Inc",
                "${workspaceFolder}/**/Drivers/STM32F4xx_HAL_Driver/Inc",
                "${workspaceFolder}/**/Drivers/STM32F4xx_HAL_Driver/Inc/Legacy",
                "${workspaceFolder}/**/Middlewares/Third_Party/FreeRTOS/Source/include",
                "${workspaceFolder}/**/Middlewares/Third_Party/FreeRTOS/Source/CMSIS_RTOS_V2",
                "${workspaceFolder}/**/Middlewares/Third_Party/FreeRTOS/Source/portable/GCC/ARM_CM4F",
                "${workspaceFolder}/**/Drivers/CMSIS/Device/ST/STM32F4xx/Include",
                "${workspaceFolder}/**/Drivers/CMSIS/Include"
            ],
            "defines": [
                "DEBUG",
                "USE_HAL_DRIVER",
                "STM32F469xx",
                "USE_FULL_LL_DRIVER"
            ],
            "windowsSdkVersion": "10.0.22000.0",
            "intelliSenseMode": "windows-gcc-x64",
            "configurationProvider": "ms-vscode.makefile-tools",
            "cStandard": "c11",
            "cppStandard": "c++11",
            "compilerPath": "C:/MinGW/bin/g++.exe"
        }
    ],
    "version": 4
}

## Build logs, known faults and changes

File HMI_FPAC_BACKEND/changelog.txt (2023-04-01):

3.0.9
- Upgraded to TouchGFX 4.21.0
- Upgraded to STM32CubeMX 6.7.0
- Upgraded to Firmware Package FW_F4 1.27.1
- Added Readme

3.0.8
- Upgraded to TouchGFX 4.20.0

3.0.7
- Upgraded to TouchGFX 4.19.1
- Upgraded to STM32CubeMX 6.5.0
- Upgraded to Firmware Package FW_F4 1.27.0
- Added GPIO pins (VSYNC_FREQ, RENDER_TIME, FRAME_RATE, MCU_ACTIVE) for performance testing

3.0.6
- Upgraded to TouchGFX 4.18.1
- Upgraded to STM32CubeMX 6.4.0

3.0.5
- Removed generation of .bin files for the external flash section
- Upgraded to TouchGFX 4.18

3.0.4
- Upgraded to STM32CubeMX 6.3.0
- Upgraded to Firmware Package FW_F4 1.26.2

3.0.3
- Upgraded to TouchGFX 4.17
- Upgraded to STM32CubeMX 6.2.1
- Upgraded to Firmware Package FW_F4 1.26.1
- Added DefaultTask to allow IP integration out of STM32CubeMX

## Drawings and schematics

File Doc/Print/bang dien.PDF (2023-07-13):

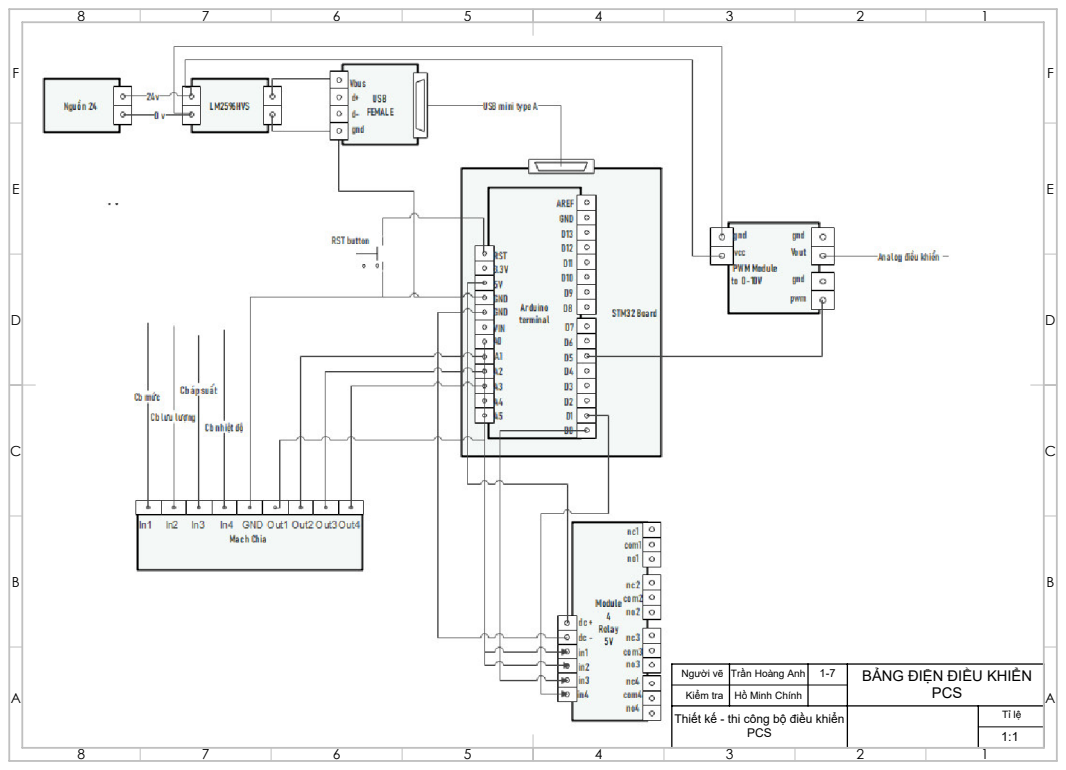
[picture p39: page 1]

Người vẽ | Trần Hoàng Anh | 1-7 | BẢNG ĐIỆN ĐIỀU KHIỂN
Kiểm tra | Hồ Minh Chính | | PCS
Thiết kế - thi công bộ điều khiển | | Tỉ lệ

PCS | | 1:1

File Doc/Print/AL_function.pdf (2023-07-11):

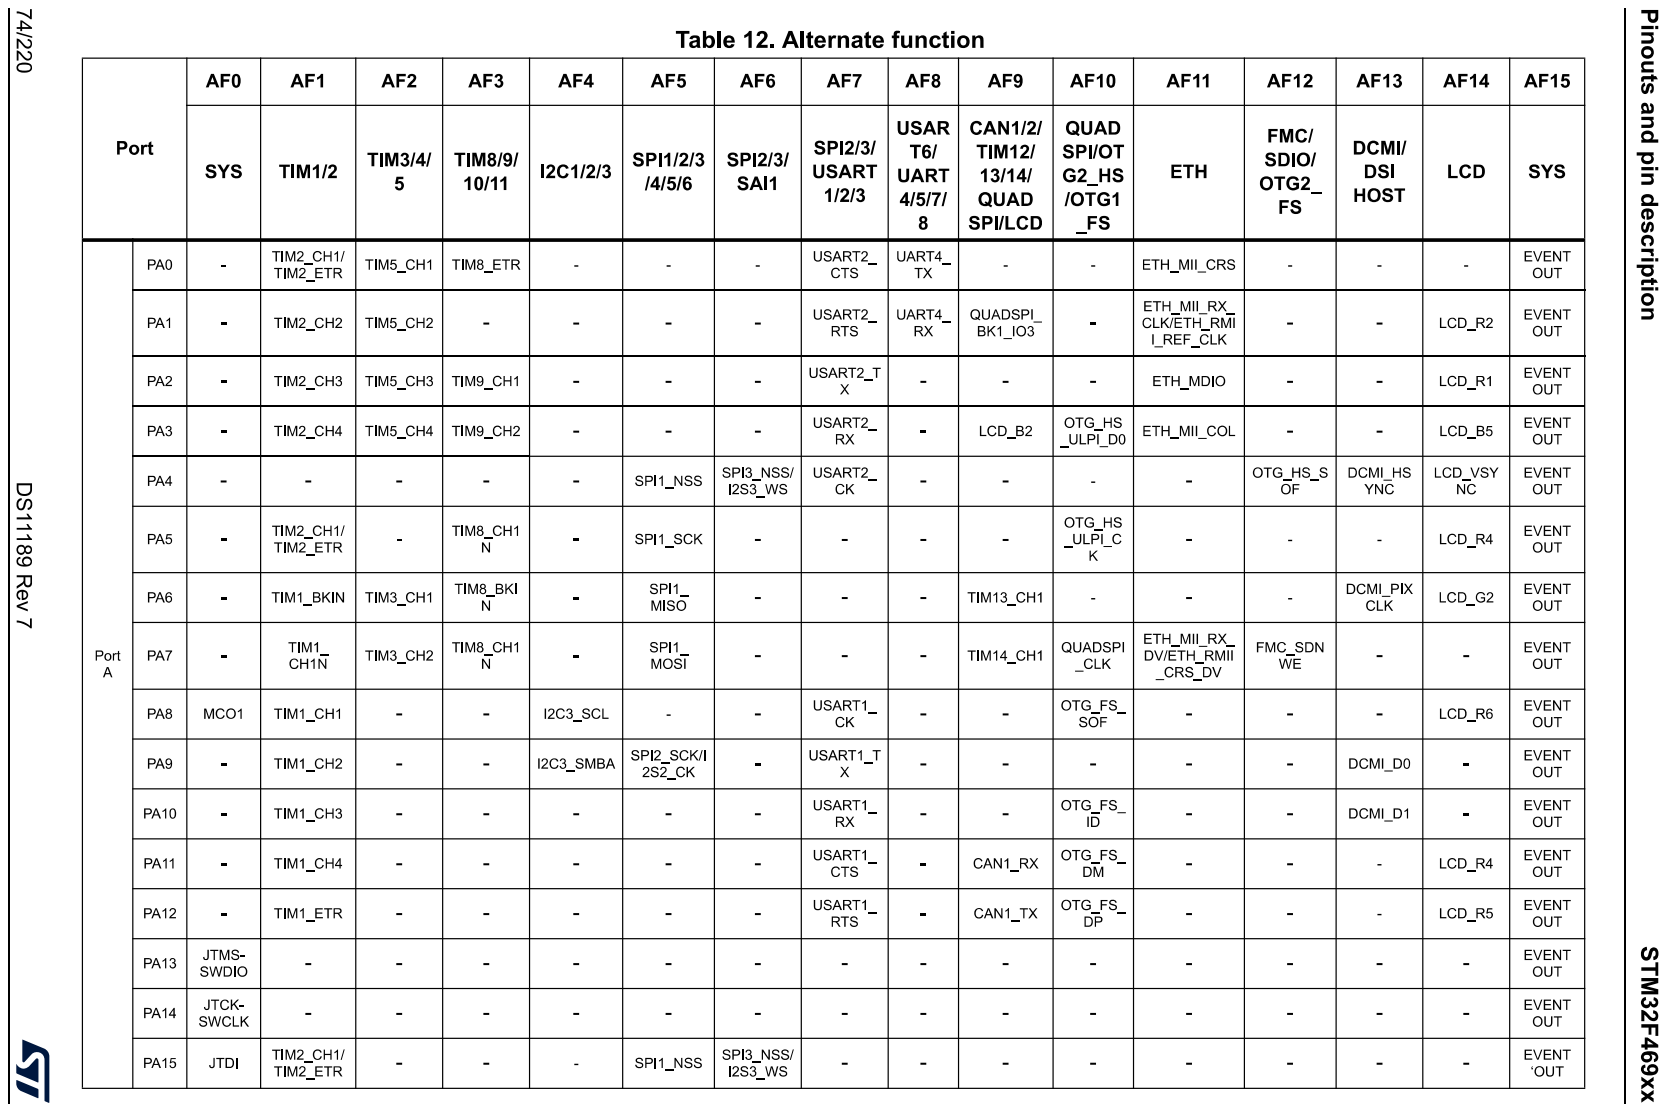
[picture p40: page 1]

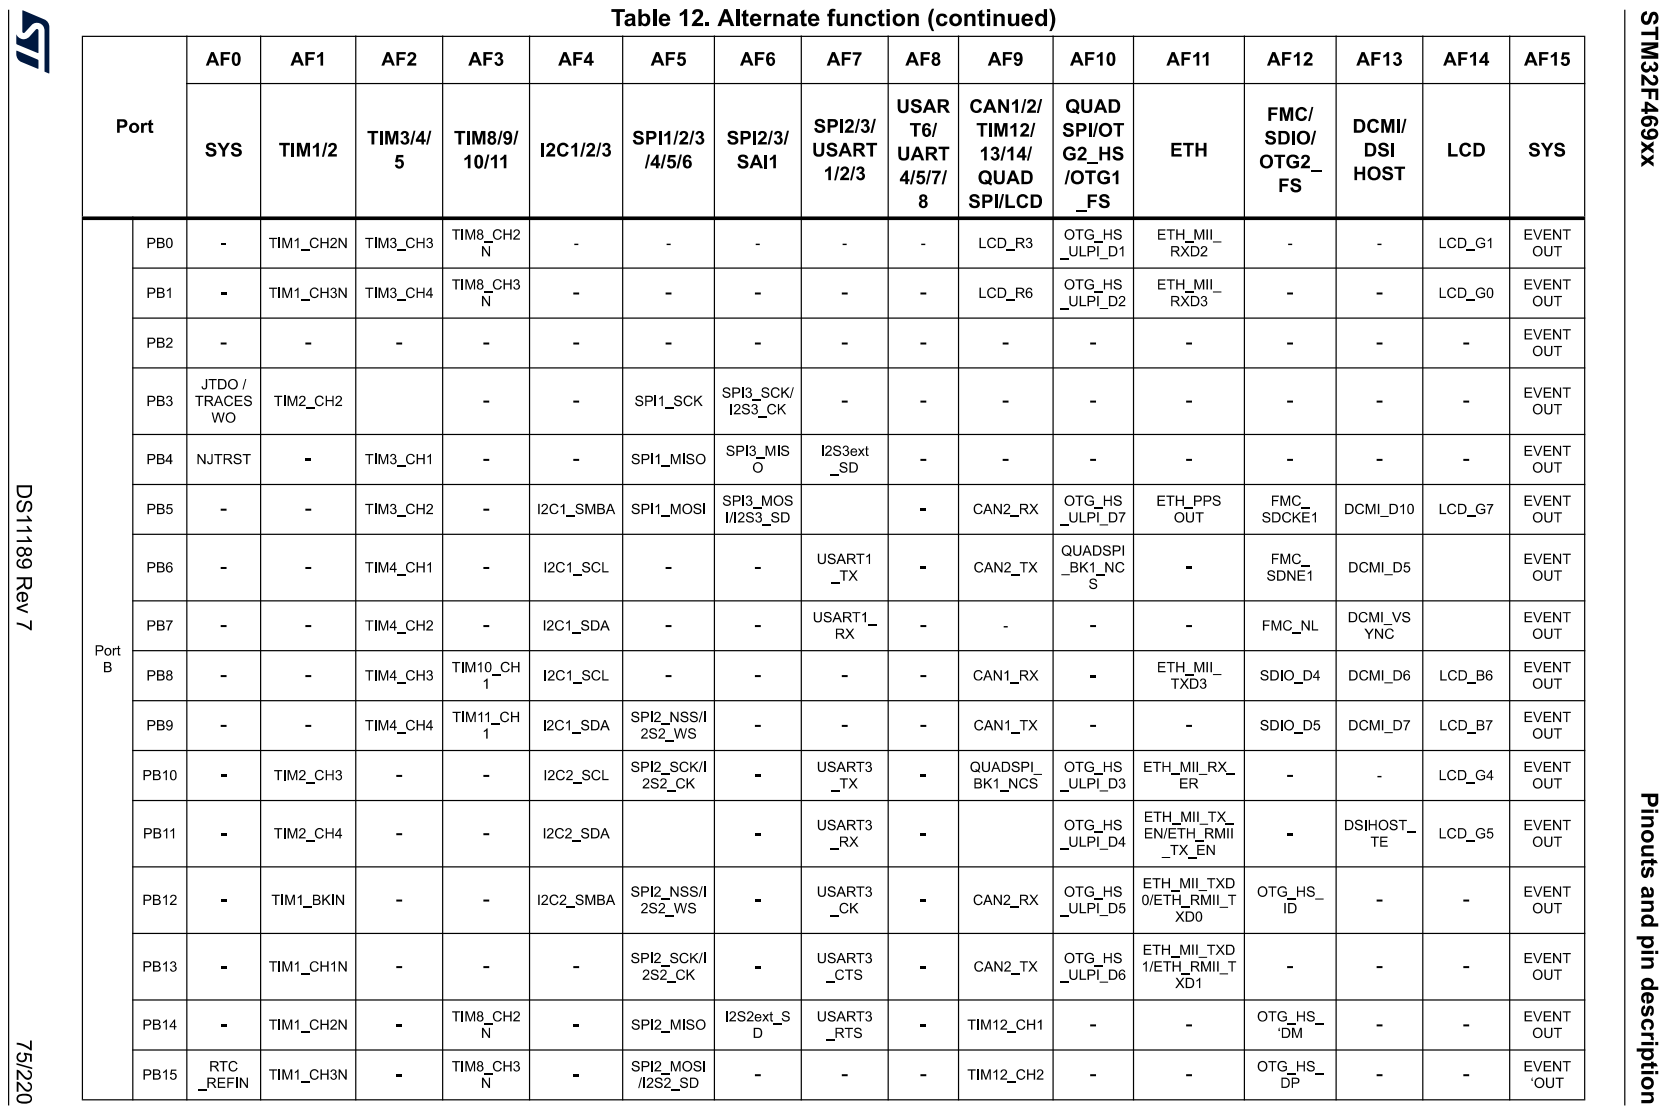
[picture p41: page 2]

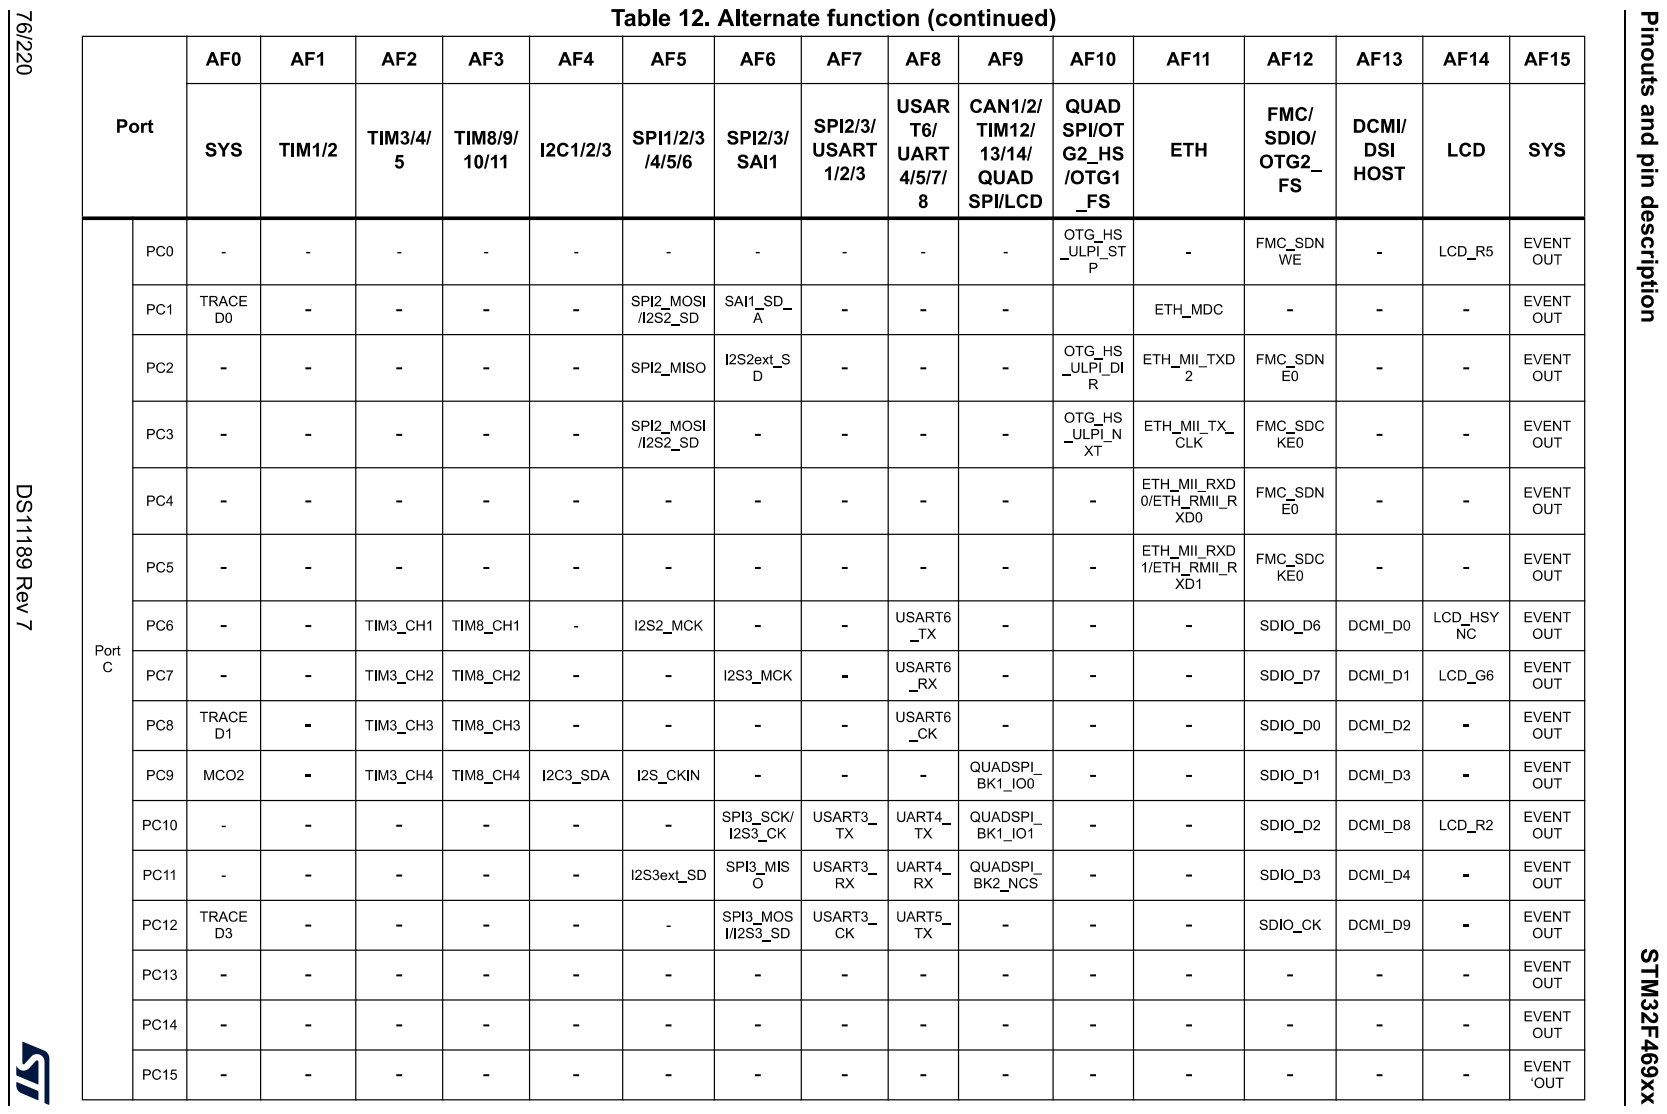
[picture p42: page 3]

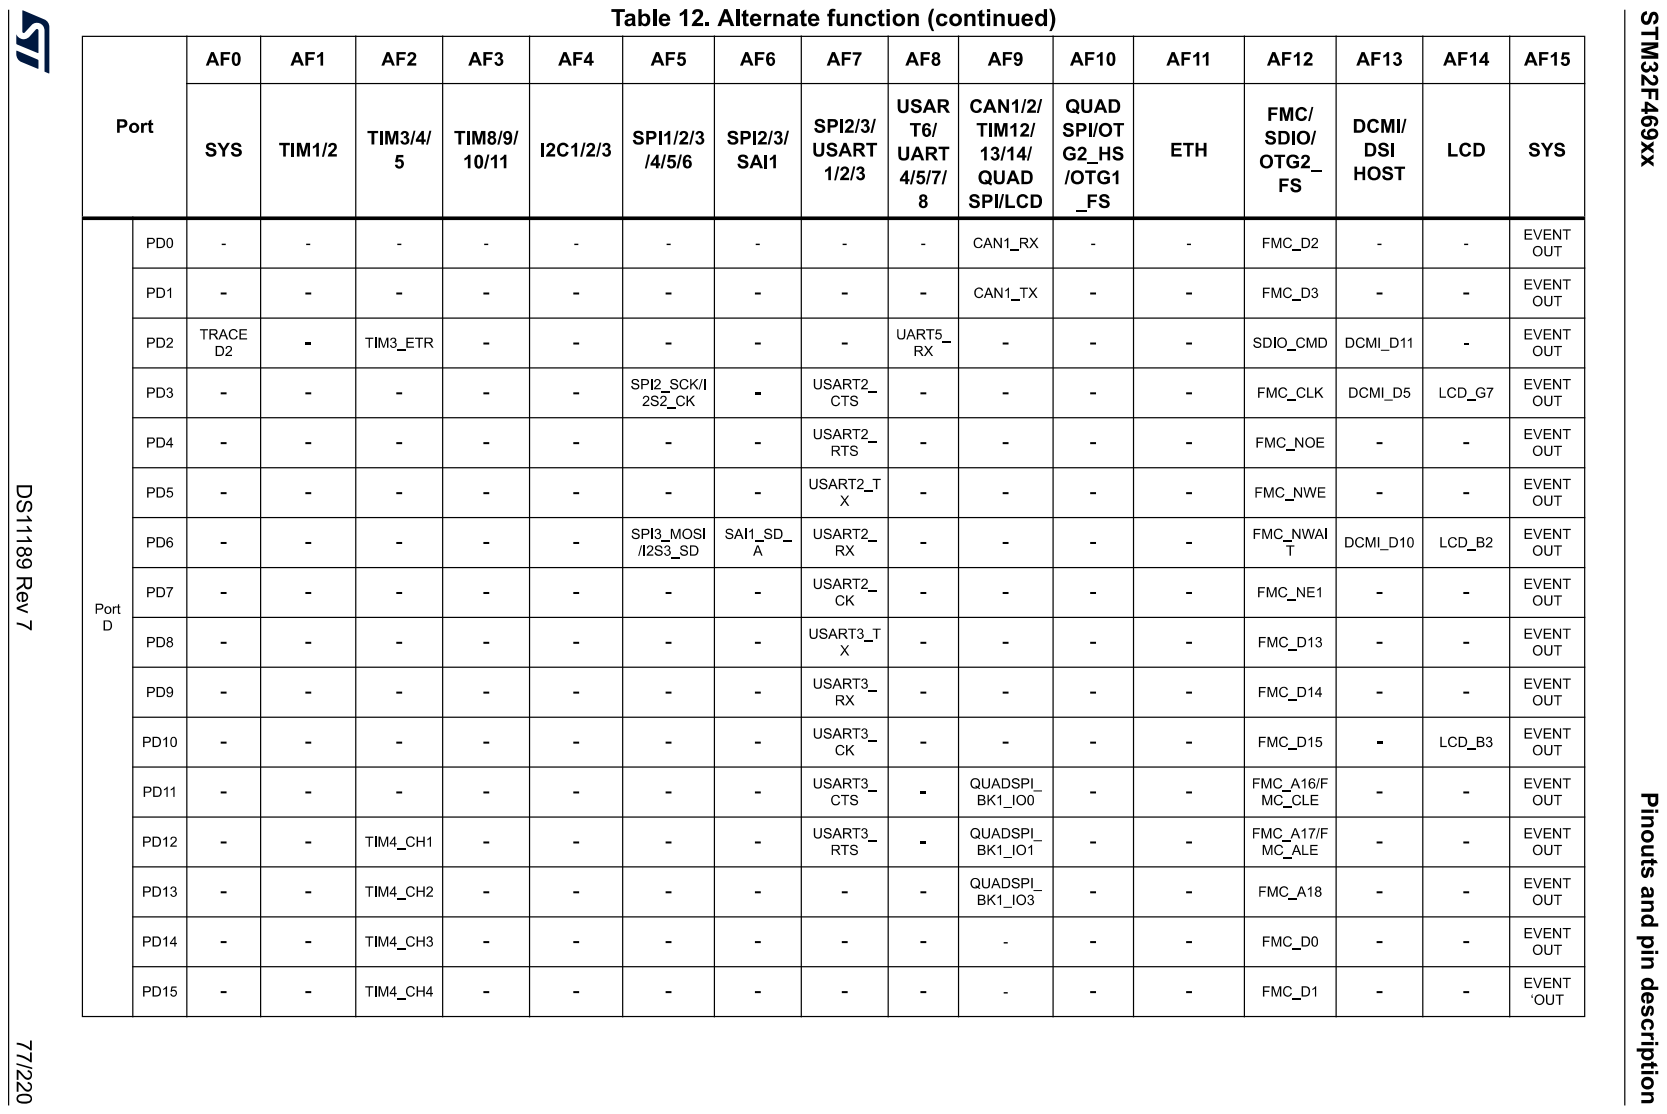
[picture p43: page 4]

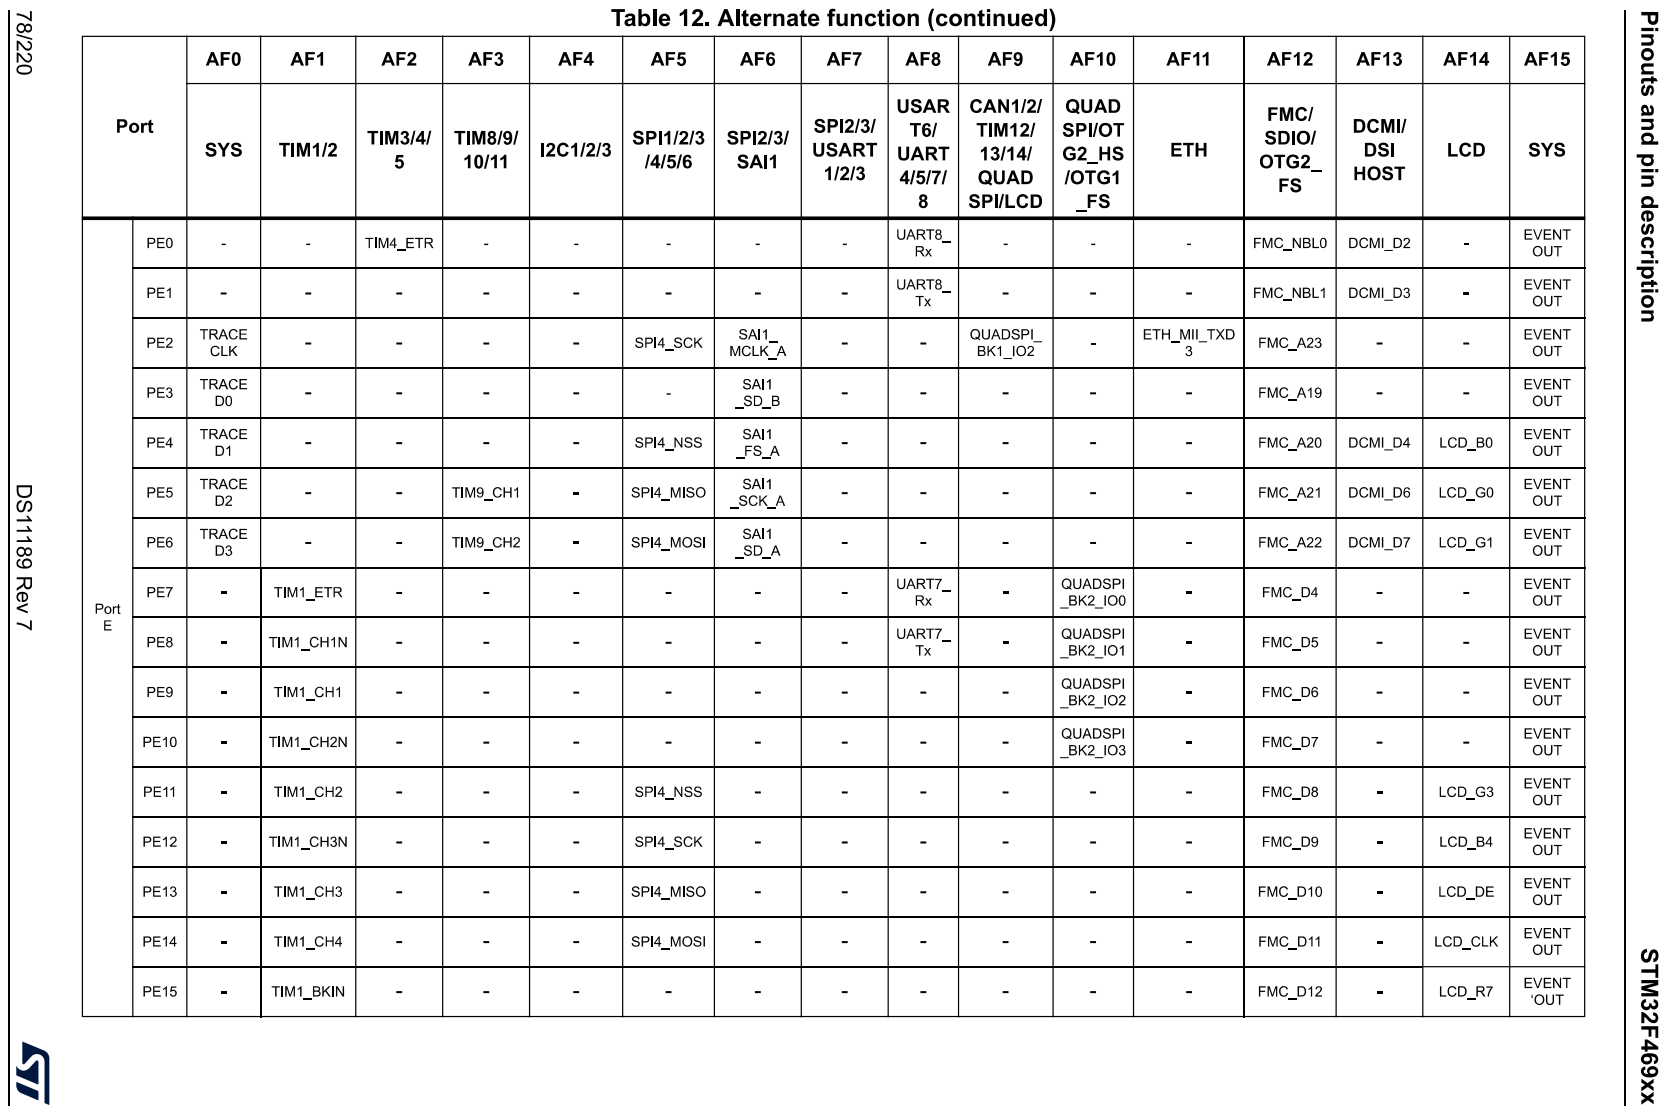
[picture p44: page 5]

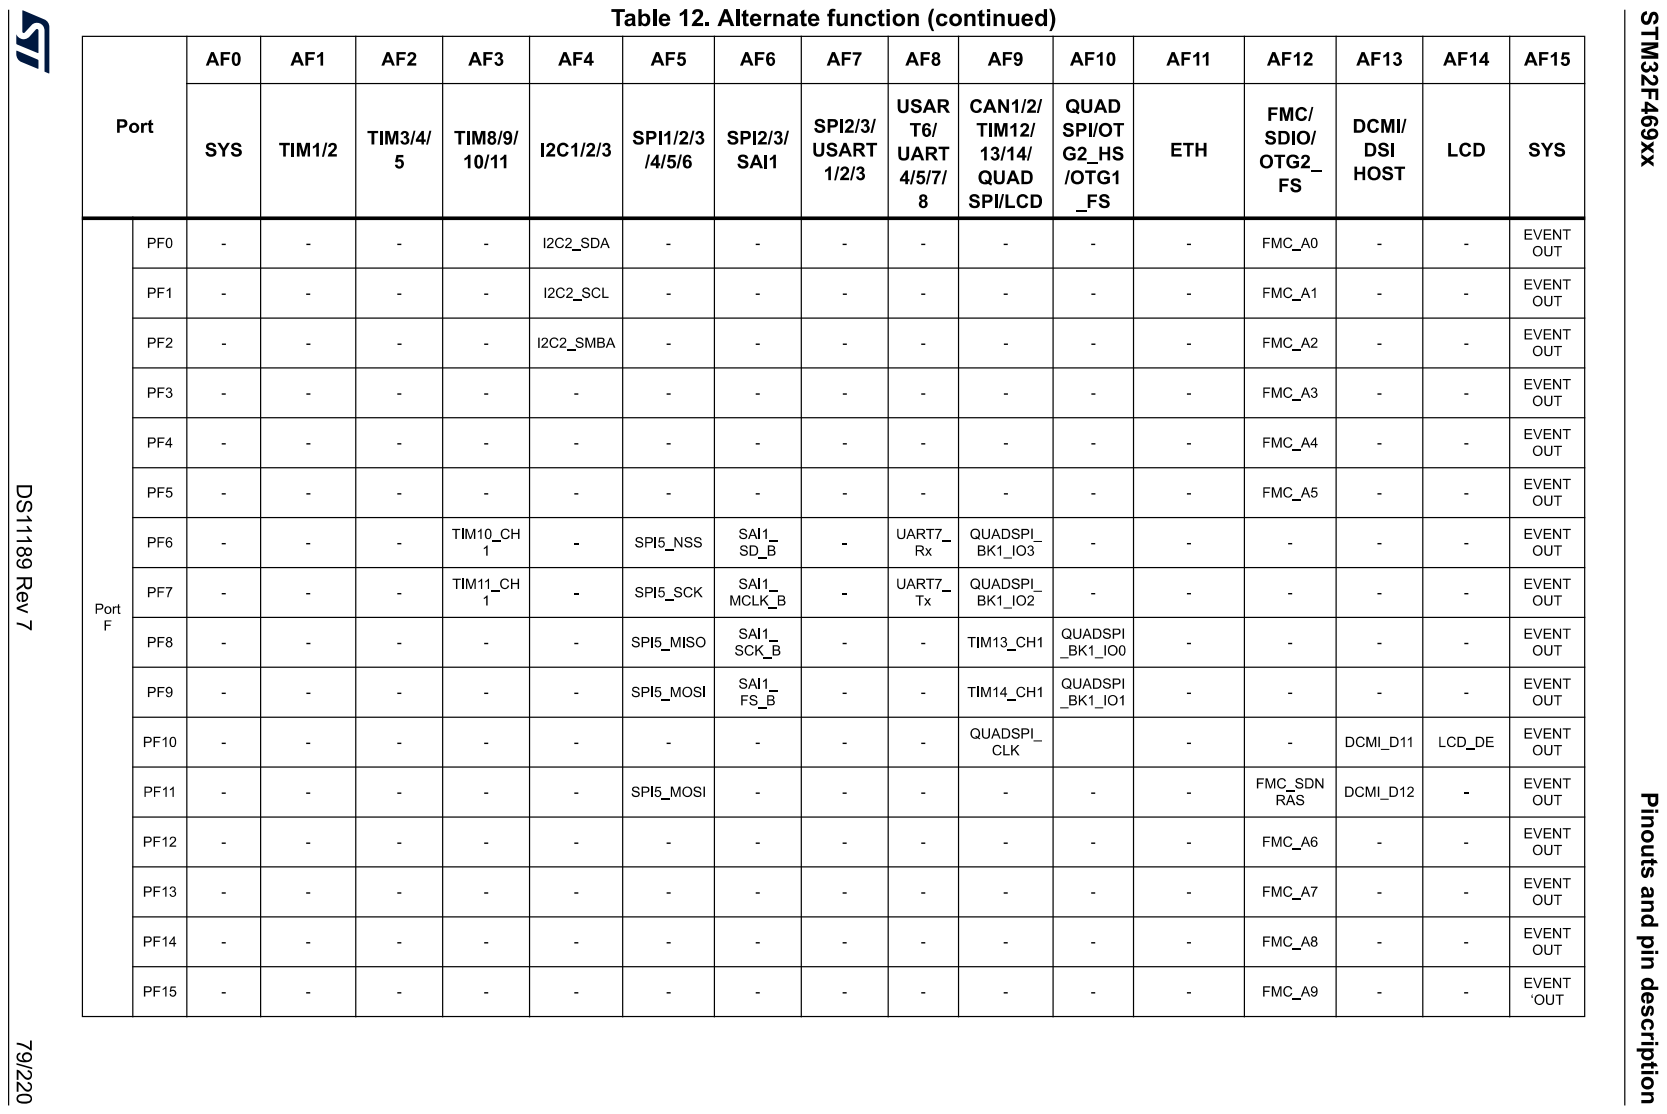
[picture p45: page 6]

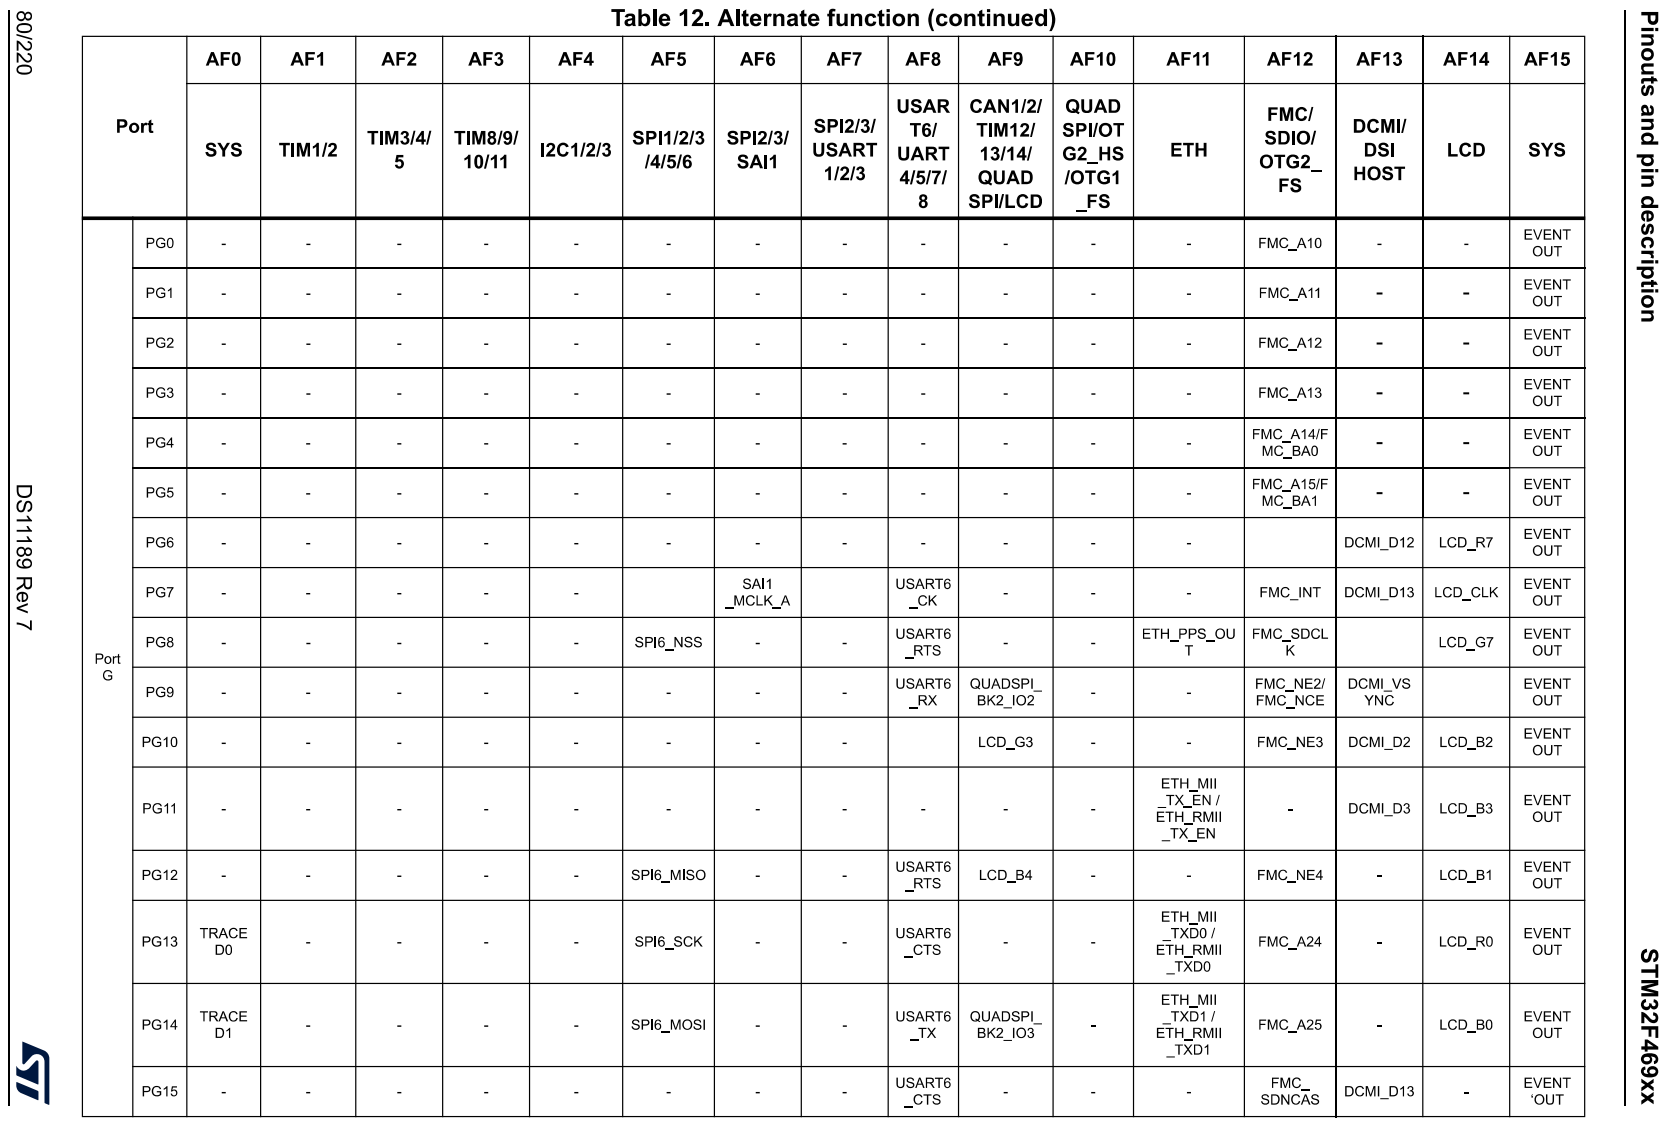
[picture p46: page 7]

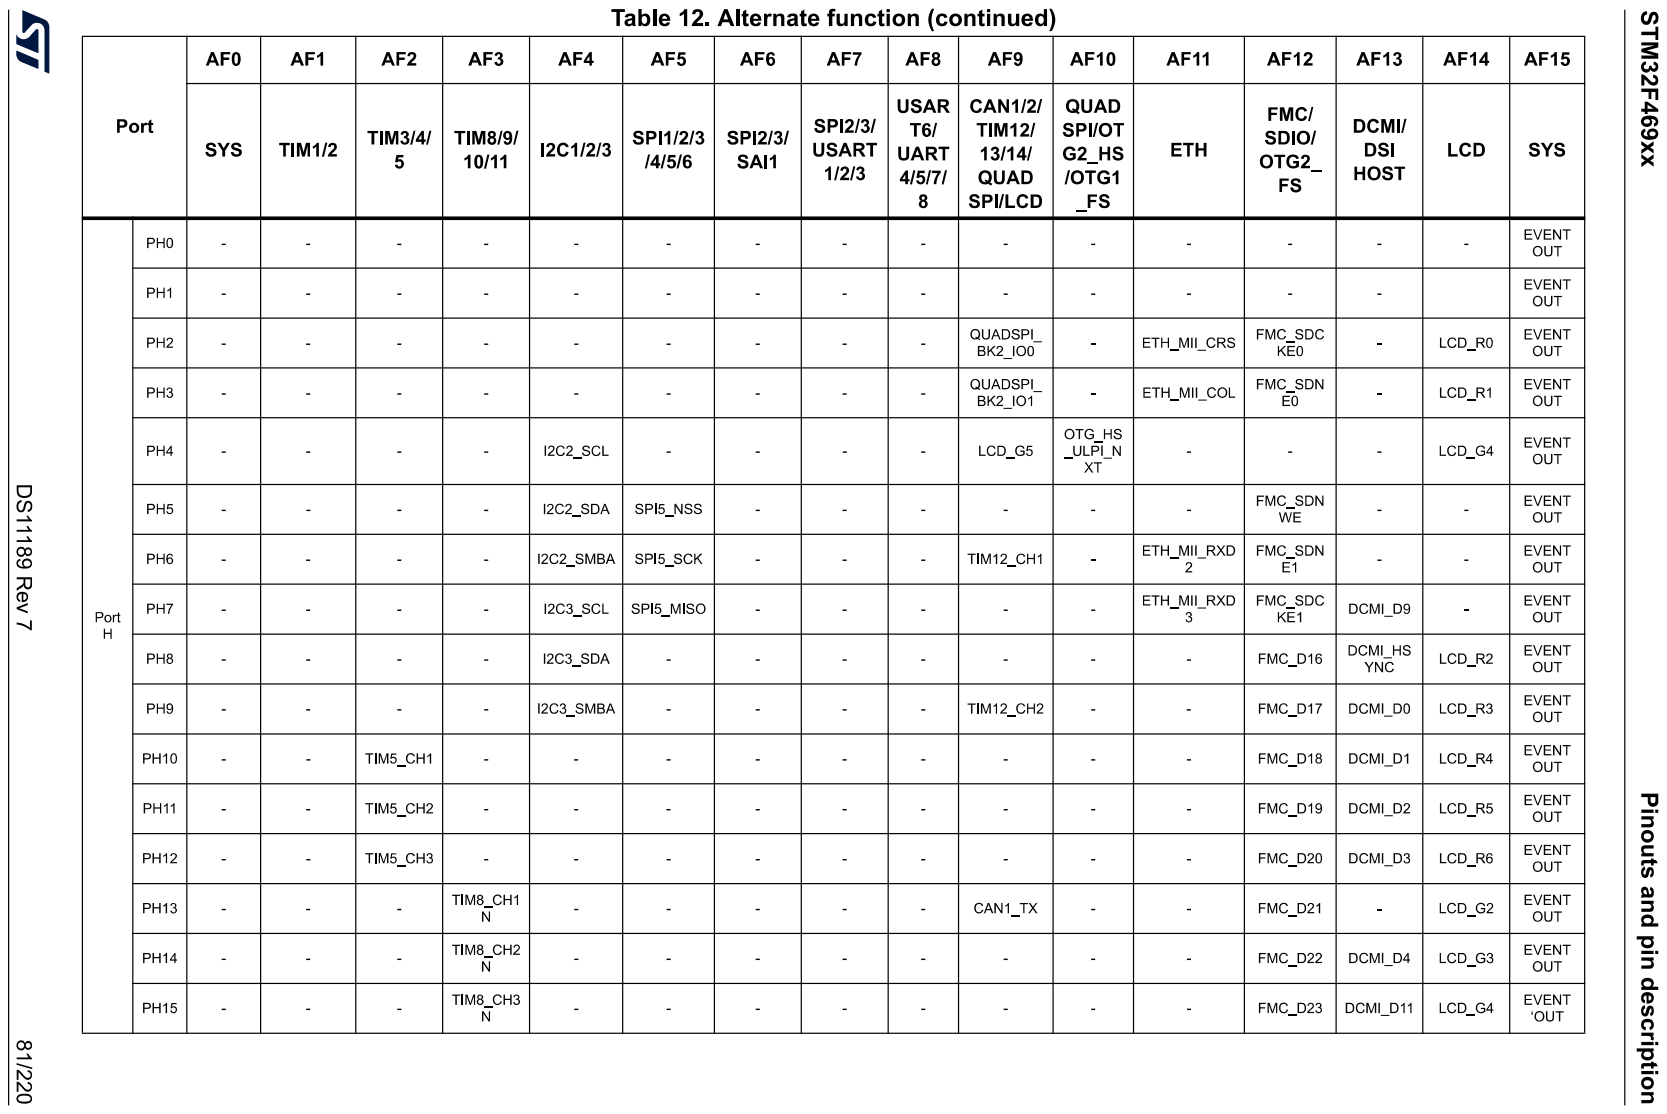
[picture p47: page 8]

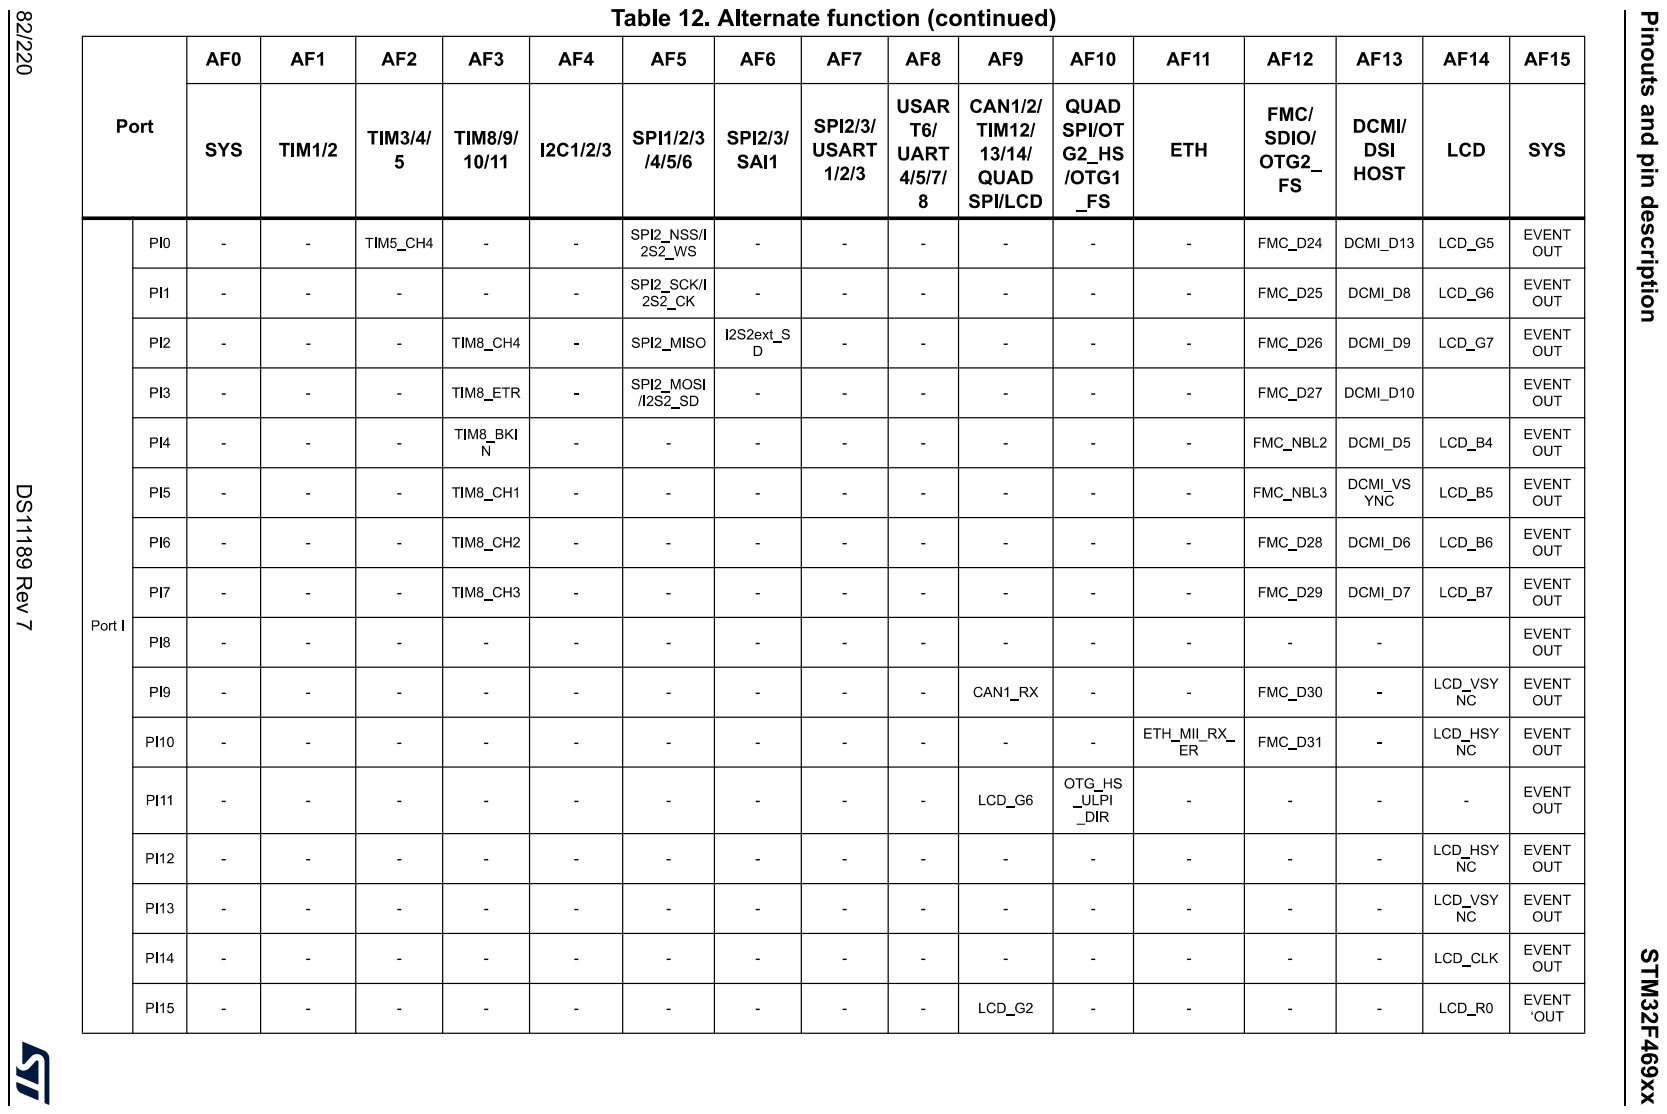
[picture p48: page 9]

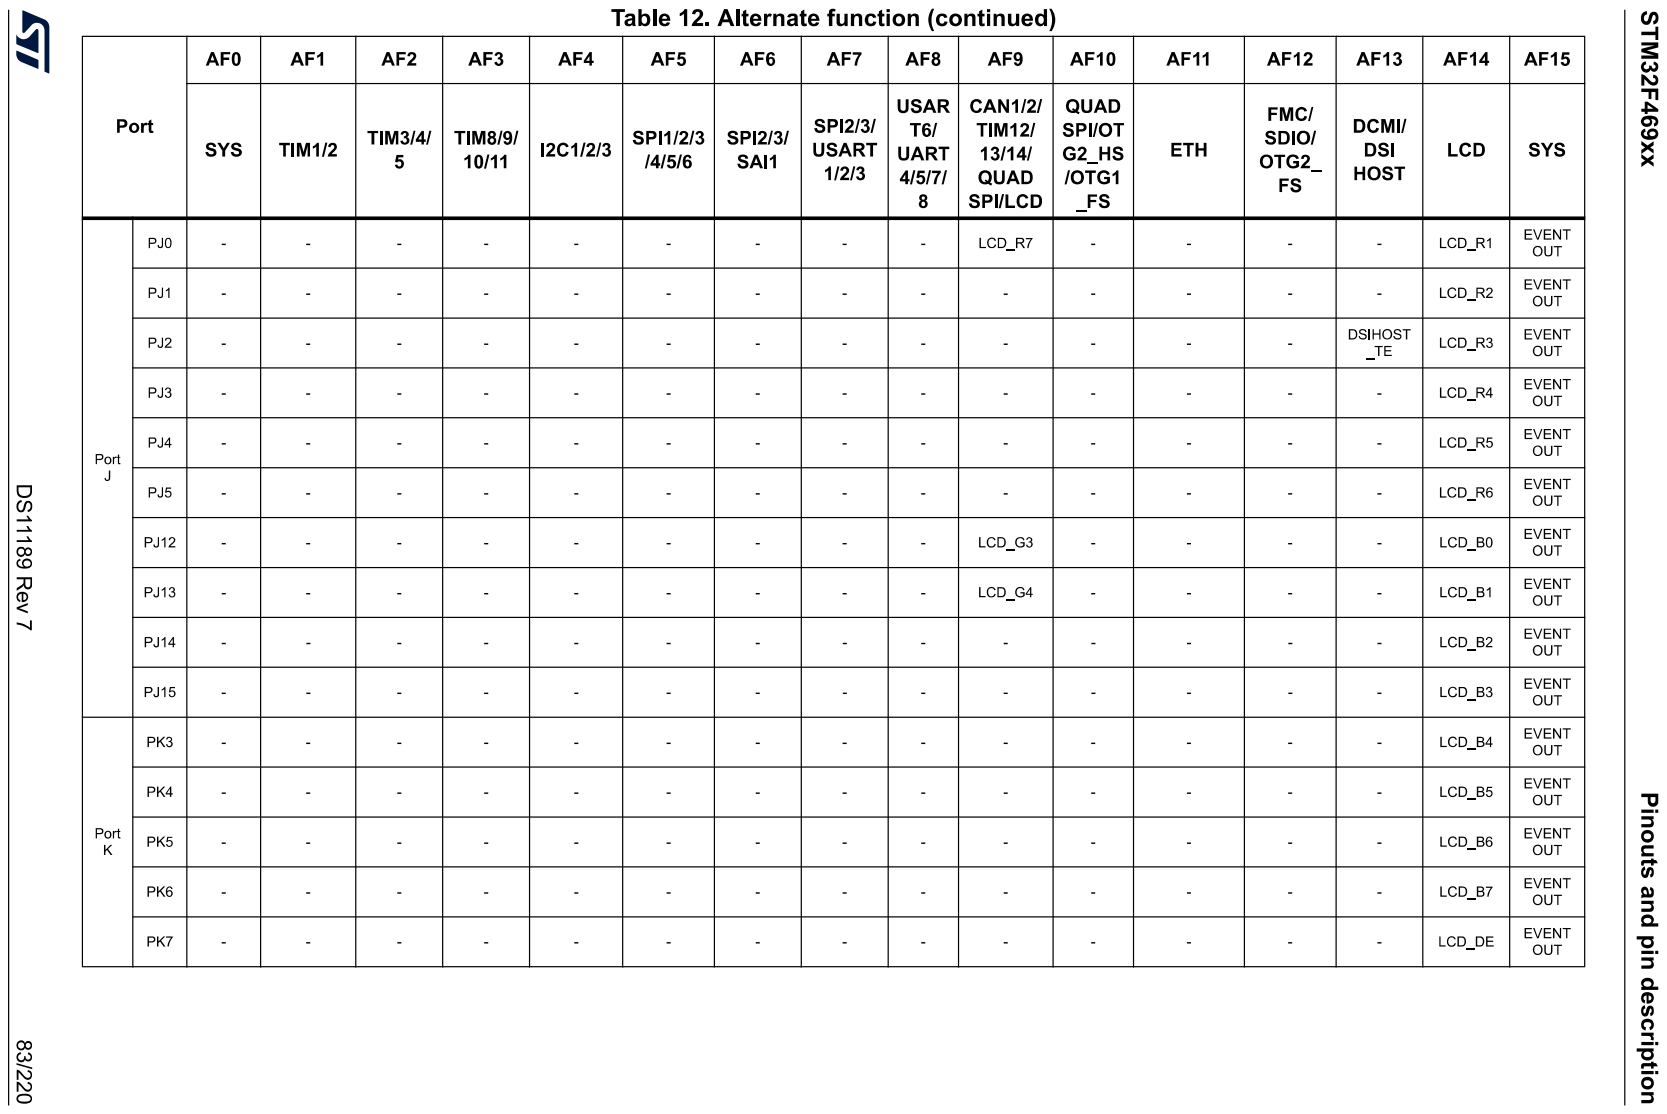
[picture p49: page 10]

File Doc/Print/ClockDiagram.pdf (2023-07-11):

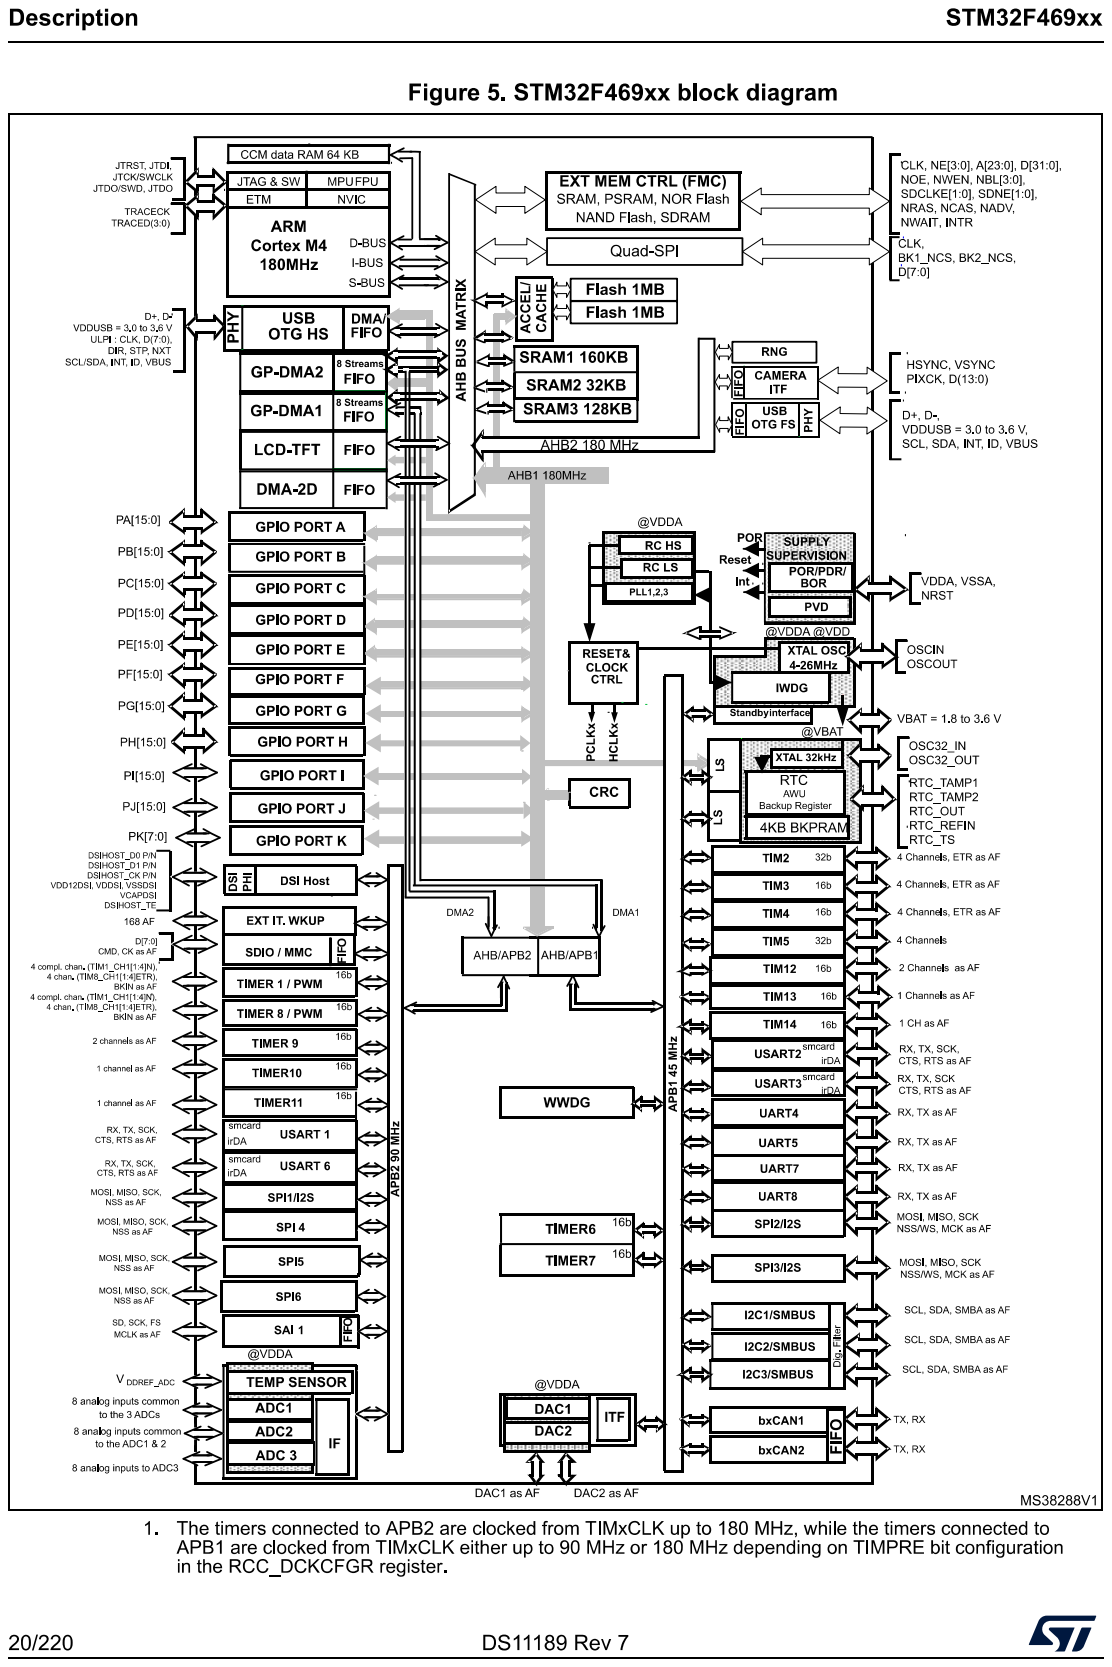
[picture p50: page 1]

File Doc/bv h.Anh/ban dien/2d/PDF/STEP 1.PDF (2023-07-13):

STEP 1

Người vẽ | Trần Hoàng Anh | 1-7 | BỘ ĐIỀU KHIỂN PCS
Kiểm tra | Hồ Minh Chính
Thiết kế - thi công bộ điều khiển | | Tỉ lệ

PCS | | 1: 2

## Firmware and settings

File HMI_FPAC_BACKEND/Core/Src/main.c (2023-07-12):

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
/* Includes ------------------------------------------------------------------*/
#include "main.h"
#include "cmsis_os.h"
#include "app_touchgfx.h"

/* USER CODE BEGIN Includes */
#include "../Components/otm8009a/otm8009a.h"
#include "stm32469i_discovery_sdram.h"
#include "stm32469i_discovery_qspi.h"

#ifndef USE_FULL_LL_DRIVER
#define USE_FULL_LL_DRIVER
#endif

#include "SEGGER_SYSVIEW.h"

#include "u_adc.h"
#include "u_gpio.h"
#include "u_pwm.h"
#include "u_rcc.h"
#include "u_firmwareDefination.h"
#include "u_appMain.h"
/* USER CODE END Includes */

/* USER CODE BEGIN PTD */
volatile uint32_t u32_testLinker[4] __attribute__((section(".touchgfxccmram")));
/* USER CODE END PTD */

/* USER CODE BEGIN PD */
/* DISPLAY */
#define LCD_ORIENTATION_LANDSCAPE 0x01
/* USER CODE END PD */

/* USER CODE BEGIN PM */
extern uint32_t _sitouchgfxccmram;
extern uint32_t _stouchgfxccmram;
extern uint32_t _etouchgfxccmram;

/* USER CODE END PM */

CRC_HandleTypeDef hcrc;

DMA2D_HandleTypeDef hdma2d;

DSI_HandleTypeDef hdsi;

I2C_HandleTypeDef hi2c1;

LTDC_HandleTypeDef hltdc;

QSPI_HandleTypeDef hqspi;

SDRAM_HandleTypeDef hsdram1;

/* Definitions for defaultTask */
osThreadId_t defaultTaskHandle;
const osThreadAttr_t defaultTask_attributes = {
    .name = "defaultTask",
    .stack_size = 128 * 4,
    .priority = (osPriority_t)osPriorityNormal,
};
/* Definitions for TouchGFXTask */
osThreadId_t TouchGFXTaskHandle;
const osThreadAttr_t TouchGFXTask_attributes = {
    .name = "TouchGFXTask",
    .stack_size = 4096 * 4,
    .priority = (osPriority_t)osPriorityNormal,
};
void SystemClock_Config(void);
static void MX_GPIO_Init(void);
static void MX_CRC_Init(void);
static void MX_DMA2D_Init(void);
static void MX_DSIHOST_DSI_Init(void);
static void MX_FMC_Init(void);
static void MX_LTDC_Init(void);
static void MX_QUADSPI_Init(void);
static void MX_I2C1_Init(void);
void StartDefaultTask(void *argument);
extern void TouchGFX_Task(void *argument);

/* USER CODE BEGIN 0 */
void initCcmRam()
{
  uint32_t sizeOfDataInCcmRam = &_etouchgfxccmram - &_stouchgfxccmram;
  uint8_t *l_des_ptr = (uint8_t *)&_stouchgfxccmram;
  uint8_t *l_src_ptr = (uint8_t *)&_sitouchgfxccmram;
  for (size_t i = 0; i < sizeOfDataInCcmRam; i++)
  {
    *l_des_ptr = *l_src_ptr;
    l_des_ptr++;
    l_src_ptr++;
  }
}
/* USER CODE END 0 */

/**
 * @brief  The application entry point.
 * @retval int
 */
int main(void)
{
  /* USER CODE BEGIN 1 */  initCcmRam();
  /* USER CODE END 1 */

  /* MCU Configuration--------------------------------------------------------*/

  /* Reset of all peripherals, Initializes the Flash interface and the Systick. */
  HAL_Init();

  /* Configure the system clock */
  SystemClock_Config();

  /* USER CODE BEGIN SysInit */
 //NVIC_SetPriorityGrouping( 0 );
 // SEGGER_SYSVIEW_Conf();
  //SEGGER_SYSVIEW_Start();

  /* USER CODE END SysInit */

  /* Initialize all configured peripherals */
  MX_GPIO_Init();
  MX_CRC_Init();
  MX_DMA2D_Init();
  MX_DSIHOST_DSI_Init();
  MX_FMC_Init();
  MX_LTDC_Init();
  MX_QUADSPI_Init();
  MX_I2C1_Init();
  MX_TouchGFX_Init();
  /* Call PreOsInit function */
  MX_TouchGFX_PreOSInit();
  /* USER CODE BEGIN 2 */
  u_gpio_OnboardInit_LED();
  u_pwm_init();
   u_adc_Init();
   u_gpio_Init_DigitalOutput();
  u_adc_initSingleConversion();
  LL_ADC_Enable(ADC1);
  HAL_Delay(10);
  u_gpio_Init_externalInterrupt();
  u_appMainCreate();
  /* creation of defaultTask */
  defaultTaskHandle = osThreadNew(StartDefaultTask, NULL, &defaultTask_attributes);
  /* creation of TouchGFXTask */
  TouchGFXTaskHandle = osThreadNew(TouchGFX_Task, NULL, &TouchGFXTask_attributes);

  /* USER CODE END 2 */

  /* Init scheduler */
  osKernelInitialize();
  /* USER CODE BEGIN Header */
  /**
   ******************************************************************************
   * @file           : main.c
   * @brief          : Main program body
   ******************************************************************************
   * @attention
   *
   * <h2><center>&copy; Copyright (c) 2020 STMicroelectronics.
   * All rights reserved.</center></h2>
   *
   * This software component is licensed by ST under Ultimate Liberty license
   * SLA0044, the "License"; You may not use this file except in compliance with
   * the License. You may obtain a copy of the License at:
   *                             www.st.com/SLA0044
   *
   ******************************************************************************
   */
  /* USER CODE END Header */
  /**
   * @}
   */
  /**
   * @}
   */

  /* Start scheduler */
  osKernelStart();

  /* We should never get here as control is now taken by the scheduler */
  /* Infinite loop */
  /* USER CODE BEGIN WHILE */
  while (1)
  {
    /* USER CODE END WHILE */

    /* USER CODE BEGIN 3 */
  }
  /* USER CODE END 3 */
}

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
/* USER CODE BEGIN Header_StartDefaultTask */
/**
 * @brief  Function implementing the defaultTask thread.
 * @param  argument: Not used
 * @retval None
 */
/* USER CODE END Header_StartDefaultTask */
void StartDefaultTask(void *argument)
{
  /* USER CODE BEGIN 5 */
  /* Infinite loop */
  for (;;)
  {
    osDelay(100);
  }
  /* USER CODE END 5 */
}

/**
 * @brief  Period elapsed callback in non blocking mode
 * @note   This function is called  when TIM6 interrupt took place, inside
 * HAL_TIM_IRQHandler(). It makes a direct call to HAL_IncTick() to increment
 * a global variable "uwTick" used as application time base.
 * @param  htim : TIM handle
 * @retval None
 */
void HAL_TIM_PeriodElapsedCallback(TIM_HandleTypeDef *htim)
{
  if (htim->Instance == TIM6)
  {
    HAL_IncTick();
  }
}

/**
 * @brief  This function is executed in case of error occurrence.
 * @retval None
 */
void Error_Handler(void)
{
  /* USER CODE BEGIN Error_Handler_Debug */
  /* User can add his own implementation to report the HAL error return state */

  /* USER CODE END Error_Handler_Debug */
}

#ifdef USE_FULL_ASSERT
/**
 * @brief  Reports the name of the source file and the source line number
 *         where the assert_param error has occurred.
 * @param  file: pointer to the source file name
 * @param  line: assert_param error line source number
 * @retval None
 */
void assert_failed(uint8_t *file, uint32_t line)
{
  /* USER CODE BEGIN 6 */
  /* User can add his own implementation to report the file name and line number,
     tex: printf("Wrong parameters value: file %s on line %d\r\n", file, line) */
  /* USER CODE END 6 */
}
#endif /* USE_FULL_ASSERT */

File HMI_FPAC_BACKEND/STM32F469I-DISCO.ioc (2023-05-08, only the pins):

Mcu.UserName=STM32F469NIHx
PA1.GPIO_Label=FRAME_RATE
PA1.Signal=GPIO_Output
PA2.GPIO_Label=VSYNC_FREQ
PA2.Signal=GPIO_Output
PA6.GPIO_Label=RENDER_TIME
PA6.Signal=GPIO_Output
PB6.Signal=QUADSPI_BK1_NCS
PB8.Signal=I2C1_SCL
PB9.Signal=I2C1_SDA
PC0.Signal=FMC_SDNWE
PC2.Signal=FMC_SDNE0
PC3.Signal=FMC_SDCKE0
PD0.Signal=FMC_D2_DA2
PD1.Signal=FMC_D3_DA3
PD10.Signal=FMC_D15_DA15
PD14.Signal=FMC_D0_DA0
PD15.Signal=FMC_D1_DA1
PD8.Signal=FMC_D13_DA13
PD9.Signal=FMC_D14_DA14
PE0.Signal=FMC_NBL0
PE1.Signal=FMC_NBL1
PE10.Signal=FMC_D7_DA7
PE11.Signal=FMC_D8_DA8
PE12.Signal=FMC_D9_DA9
PE13.Signal=FMC_D10_DA10
PE14.Signal=FMC_D11_DA11
PE15.Signal=FMC_D12_DA12
PE7.Signal=FMC_D4_DA4
PE8.Signal=FMC_D5_DA5
PE9.Signal=FMC_D6_DA6
PF0.Signal=FMC_A0
PF1.Signal=FMC_A1
PF10.Signal=QUADSPI_CLK
PF11.Signal=FMC_SDNRAS
PF12.Signal=FMC_A6
PF13.Signal=FMC_A7
PF14.Signal=FMC_A8
PF15.Signal=FMC_A9
PF2.Signal=FMC_A2
PF3.Signal=FMC_A3
PF4.Signal=FMC_A4
PF5.Signal=FMC_A5
PF6.Signal=QUADSPI_BK1_IO3
PF7.Signal=QUADSPI_BK1_IO2
PF8.Signal=QUADSPI_BK1_IO0
PF9.Signal=QUADSPI_BK1_IO1
PG0.Signal=FMC_A10
PG1.Signal=FMC_A11
PG12.GPIO_Label=MCU_ACTIVE
PG12.Signal=GPIO_Output
PG15.Signal=FMC_SDNCAS
PG4.Signal=FMC_A14_BA0
PG5.Signal=FMC_A15_BA1
PG8.Signal=FMC_SDCLK
PH0/OSC_IN.Signal=RCC_OSC_IN
PH1/OSC_OUT.Signal=RCC_OSC_OUT
PH10.Signal=FMC_D18
PH11.Signal=FMC_D19
PH12.Signal=FMC_D20
PH13.Signal=FMC_D21
PH14.Signal=FMC_D22
PH15.Signal=FMC_D23
PH7.Signal=GPIO_Output
PH8.Signal=FMC_D16
PH9.Signal=FMC_D17
PI0.Signal=FMC_D24
PI1.Signal=FMC_D25
PI10.Signal=FMC_D31
PI2.Signal=FMC_D26
PI3.Signal=FMC_D27
PI4.Signal=FMC_NBL2
PI5.Signal=FMC_NBL3
PI6.Signal=FMC_D28
PI7.Signal=FMC_D29
PI9.Signal=FMC_D30
PJ2.Signal=DSIHOST_TE
PK3.Signal=GPIO_Output

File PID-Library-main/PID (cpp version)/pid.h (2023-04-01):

 /*
------------------------------------------------------------------------------
~ File   : pid.h
~ Author : Majid Derhambakhsh
~ Version: V1.0.0
~ Created: 06/12/2021 05:00:00 PM
~ Brief  :
~ Support:
		   E-Mail : Majid.do16@gmail.com (subject : Embedded Library Support)

		   Github : https://github.com/Majid-Derhambakhsh
------------------------------------------------------------------------------
~ Description:      CPP version

~ Attention  :

~ Changes    :
------------------------------------------------------------------------------
*/

#ifndef __PID_H_
#define __PID_H_

/* ~~~~~~~~~~~~~~~~~~~~~~~~~~~~~~~~~~~~~~~~~~~~~~~~~~~~~~~~~~ Include ~~~~~~~~~~~~~~~~~~~~~~~~~~~~~~~~~~~~~~~~~~~~~~~~~~~~~~~~~~ */
#include <stdint.h>
#include <string.h>

/* ------------------------------------------------------------------ */

#ifdef __CODEVISIONAVR__  /* Check compiler */

#pragma warn_unref_func- /* Disable 'unused function' warning */

/* ------------------------------------------------------------------ */

#elif defined(__GNUC__) && !defined(USE_HAL_DRIVER)  /* Check compiler */

#pragma GCC diagnostic ignored "-Wunused-function" /* Disable 'unused function' warning */

/* ------------------------------------------------------------------ */

#elif defined(USE_HAL_DRIVER)  /* Check driver */

	#include "main.h"

	/* --------------- Check Mainstream series --------------- */

	#ifdef STM32F0
		#include "stm32f0xx_hal.h"       /* Import HAL library */
	#elif defined(STM32F1)
		#include "stm32f1xx_hal.h"       /* Import HAL library */
	#elif defined(STM32F2)
		#include "stm32f2xx_hal.h"       /* Import HAL library */
	#elif defined(STM32F3)
		#include "stm32f3xx_hal.h"       /* Import HAL library */
	#elif defined(STM32F4)
		#include "stm32f4xx_hal.h"       /* Import HAL library */
	#elif defined(STM32F7)
		#include "stm32f7xx_hal.h"       /* Import HAL library */
	#elif defined(STM32G0)
		#include "stm32g0xx_hal.h"       /* Import HAL library */
	#elif defined(STM32G4)
		#include "stm32g4xx_hal.h"       /* Import HAL library */

	/* ------------ Check High Performance series ------------ */

	#elif defined(STM32H7)
		#include "stm32h7xx_hal.h"       /* Import HAL library */

	/* ------------ Check Ultra low power series ------------- */

	#elif defined(STM32L0)
		#include "stm32l0xx_hal.h"       /* Import HAL library */
	#elif defined(STM32L1)
		#include "stm32l1xx_hal.h"       /* Import HAL library */
	#elif defined(STM32L5)
		#include "stm32l5xx_hal.h"       /* Import HAL library */
	#elif defined(STM32L4)
		#include "stm32l4xx_hal.h"       /* Import HAL library */
	#elif defined(STM32H7)
		#include "stm32h7xx_hal.h"       /* Import HAL library */
	#else
	#endif /* STM32F1 */

	/* ------------------------------------------------------- */

	#if defined ( __ICCARM__ ) /* ICCARM Compiler */

	#pragma diag_suppress=Pe177   /* Disable 'unused function' warning */

	#elif defined   (  __GNUC__  ) /* GNU Compiler */

	#pragma diag_suppress 177     /* Disable 'unused function' warning */

	#endif /* __ICCARM__ */

/* ------------------------------------------------------------------ */

#else                     /* Compiler not found */

#error Chip or Library not supported  /* Send error */

#endif /* __CODEVISIONAVR__ */

/* ------------------------------------------------------------------ */

/* ~~~~~~~~~~~~~~~~~~~~~~~~~~~~~~~~~~~~~~~~~~~~~~~~~~~~~~~~~~ Defines ~~~~~~~~~~~~~~~~~~~~~~~~~~~~~~~~~~~~~~~~~~~~~~~~~~~~~~~~~~ */
/* ------------------------ Library ------------------------ */
#define _PID_LIBRARY_VERSION    1.0.0

/* ------------------------ Public ------------------------- */
#define _PID_8BIT_PWM_MAX       UINT8_MAX
#define _PID_SAMPLE_TIME_MS_DEF 100

#ifndef _FALSE

	#define _FALSE 0

#endif

#ifndef _TRUE

	#define _TRUE 1

#endif

/* ---------------------- By compiler ---------------------- */
#ifndef GetTime

	/* ---------------------- By compiler ---------------------- */

	#ifdef __CODEVISIONAVR__  /* Check compiler */

		#define GetTime()   0

	/* ------------------------------------------------------------------ */

	#elif defined(__GNUC__) && !defined(USE_HAL_DRIVER)  /* Check compiler */

		#define GetTime()   0

	/* ------------------------------------------------------------------ */

	#elif defined(USE_HAL_DRIVER)  /* Check driver */

		#define GetTime()   HAL_GetTick()

	/* ------------------------------------------------------------------ */

	#else
	#endif /* __CODEVISIONAVR__ */
	/* ------------------------------------------------------------------ */

#endif

/* --------------------------------------------------------- */

/* ~~~~~~~~~~~~~~~~~~~~~~~~~~~~~~~~~~~~~~~~~~~~~~~~~~~~~~~~~~~ Types ~~~~~~~~~~~~~~~~~~~~~~~~~~~~~~~~~~~~~~~~~~~~~~~~~~~~~~~~~~~ */
/* PID Mode */
typedef enum
{
	
	_PID_MODE_MANUAL    = 0,
	_PID_MODE_AUTOMATIC = 1
	
}PIDMode_TypeDef;

/* PID P On x */
typedef enum
{
	
	_PID_P_ON_M = 0, /* Proportional on Measurement */
	_PID_P_ON_E = 1
	
}PIDPON_TypeDef;

/* PID Control direction */
typedef enum
{
	
	_PID_CD_DIRECT  = 0,
	_PID_CD_REVERSE = 1
	
}PIDCD_TypeDef;
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

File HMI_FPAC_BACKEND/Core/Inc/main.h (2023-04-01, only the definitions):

#define MCU_ACTIVE_Pin GPIO_PIN_12
#define MCU_ACTIVE_GPIO_Port GPIOG
#define FRAME_RATE_Pin GPIO_PIN_1
#define FRAME_RATE_GPIO_Port GPIOA
#define VSYNC_FREQ_Pin GPIO_PIN_2
#define VSYNC_FREQ_GPIO_Port GPIOA
#define RENDER_TIME_Pin GPIO_PIN_6
#define RENDER_TIME_GPIO_Port GPIOA

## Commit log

2023-04-02 4.2.2023 pid Insimulator
2023-04-02 4.2.2023 PID Sim App
2023-04-02 4.2.2023 PID Sim App It GOOD from here
2023-04-02 4.2.2023 End of the day, still congested with PID algorithm
2023-04-05 4.5.2023_Laptop PID screen, PID setting screen
2023-05-22 Destop - add more doc
    [pinOut.xlsx]
2023-05-23 Destop - before delete pid.C
2023-06-06 Destop - add new Files
    [pinOut.xlsx]
2023-06-11 Destop - Fix 2000Bug
    [u_appMain.c, u_appPwm.c]
2023-06-11 Destop - test pwm to analog is done!!! Goodnight
    [pinOut.xlsx]
2023-06-12 Destop - add more documents
    [pinOut.xlsx]
2023-06-12 edit doc
    [Test Debug.cfg, pinOut.xlsx]
2023-06-15 Fix digitalOutput, Done but note load to board
    [u_appDigitalOutput.c]
2023-06-16 notify active screen is done, already load on board
2023-06-21 PC bug rigit this point
    [SettingView.cpp, u_appAdc.c, u_appDigitalOutput.c]
2023-06-23 CloseLoopGraph, Contrains PID parameter
2023-06-24 ADC not run, bux here
2023-06-24 Adc is work again
2023-06-24 Bug had fixed, relevent to priority of Task
    [u_appMain.c]
2023-06-24 dev Pid App
2023-06-25 SEGGER BUG. Miss task's name
    [main.c, u_appDigitalOutput.c, u_appMain.c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]
2023-06-26 Dev Pid
2023-06-27 add a word file
    [pinOut.xlsx]
2023-07-02 SEGGER sysremview overfloat BUX have been fixed
    [u_appPwm.c]
2023-07-02 add function Suspend and Resume for apps
    [pinOut.xlsx]
2023-07-02 Backup point
    [pinOut.xlsx]
2023-07-02 all State machine is done
    [pinOut.xlsx]
2023-07-03 modify some wigget for more readability
    [pinOut.xlsx]
2023-07-04 no thing
    [pinOut.xlsx]
2023-07-04 FIX_BUG, app pwm suspend, pwm not off
    [u_appPwm.c]
2023-07-04 fix pwm app
2023-07-05 Fix bug, digital pin DO_2_PIN is wrong
    [pinOut.xlsx]
2023-07-07 fixing too much, do not remember what i has done
    [pinOut.xlsx]
2023-07-07 Bug send pid to backend
    [pinOut.xlsx]
2023-07-08 fix divide by 0
    [main.c, u_appMain.c]
2023-07-09 add zoom, forward, backward
    [pinOut.xlsx]
2023-07-09 update doc
    [pinOut.xlsx]
2023-07-11 Desktop fix doc
    [pinOut.xlsx]
2023-07-13 write doc
    [1.SLDDRW, 1.SLDPRT, 2.SLDDRW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]
